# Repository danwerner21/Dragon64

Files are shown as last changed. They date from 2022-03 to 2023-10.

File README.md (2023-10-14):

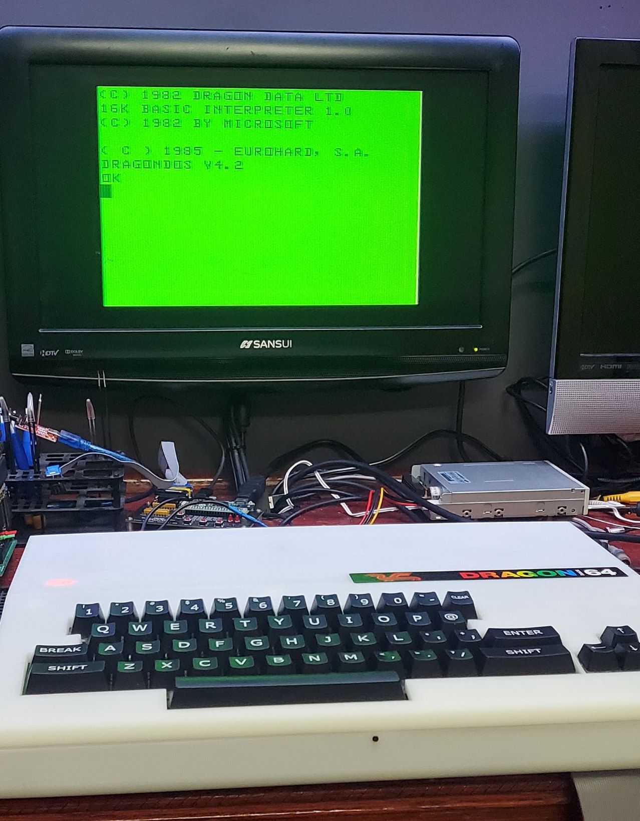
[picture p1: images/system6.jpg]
System

(note that I need to get a better picture of the screen, this is s-video and is very clear in person)

# Dragon 64 Clone PCB

The Dragon 64 is a home computer that was built in the 1980s for the European market by Dragon Data, Ltd. The Dragons are very similar to the TRS-80 Color Computer, and in fact provisions have been made to allow the keyboard to become compatible with a TRS-80 color computer clone.   This version of the Dragon 64 computer produces NTSC rather than PAL composite video and has the ability to produce "Commodore style LCA" s-video output for a much clearer video display.  It also supports either a vertical or horizontal cartridge slot and TTL level serial capabilities for convenient use of modern TTL to USB adaptors.

It should be possible for this PCB to become a Tandy Color Computer clone as well, but this is not implimented in V1.

A regulated 12V and 5V power supply is required.

The main PCB also includes a DragonDOS floppy controller that can be optionally populated to support floppy disk support.

A design is included for a 3d-printed retro style case.

Note that much of this work is based on the work done by Ciaran Anscomb.  Without that original work, this would have taken much longer to complete.

More generalized information on this line of retro computers can be found here:

   * https://en.wikipedia.org/wiki/Dragon_32/64
   * https://colorcomputerarchive.com/
   * https://cococentral.com/
   * https://www.6809.org.uk/dragon/
   * http://dragondata.co.uk/

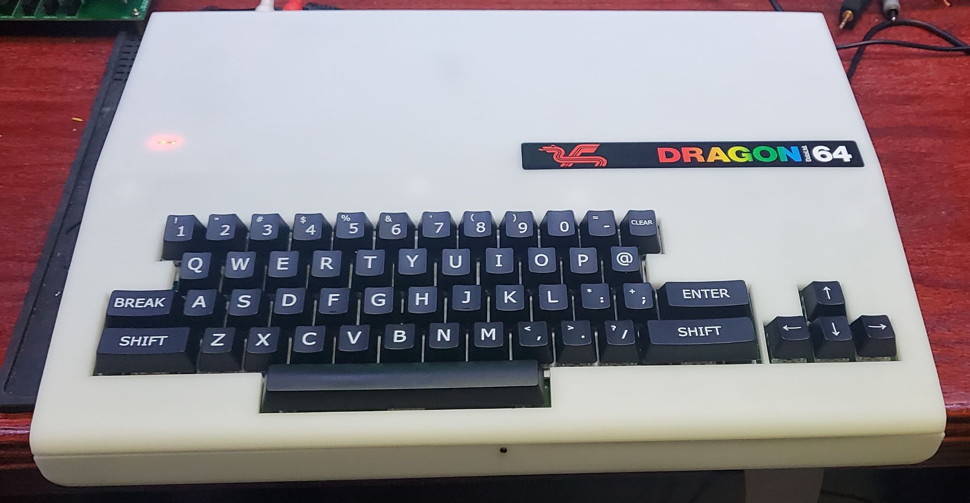
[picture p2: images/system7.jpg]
System

System
System

---

## To Do:
* test the joystick interface
* test the cassette interface
* test the printer interface
---

## What is included in this repo?
As of this time, the repo includes

1. The Mainboard PCB Kicad design and Gerber files
2. The Keyboard PCB Kicad design and Gerber files
3. OpenSCAD and STL files for a 3d printed case
4. SVG file for custom keycaps from MAX Keyboard

---

## Known Bugs

### System Jumpers
LK1 - Ram Size Selection 64K=1&2, 32K=2&3

J3 - Composite on Luma J3 on for composite video, off for S-video

J5 - Enable Disk ROM

---

## Bill Of Materials

### Mainboard
QTY|ref|value|part|description
--------|--------|----|--------|--------
1|IC4|4050|4050|
1|IC7|4069|4069|Hex inverter
8|IC15, IC16, IC21, IC22, IC26, IC27, IC32, IC33|4164|4164|
1|IC6|4529|4529|
1|IC11|6551|6551|
2|IC5,IC8|6821|6821|Peripheral Interface Adapter 1MHz| DIP-40
1|IC10|6847|6847|
1|IC39|6883|6883|
1|D8|1N914|1N914|100V 0.3A Small Signal Fast Switching Diode| DO-35
2|IC34,IC37|27C128|27C128|OTP EPROM 128 KiBit| [Obsolete 2004-01]
1|U5|27C64|27C64|OTP EPROM 64 KiBit| [Obsolete 2004-01]
2|IC35,U3|74LS00|74LS00|quad 2-input NAND gate
1|IC36|74LS02|74LS02|quad 2-input NOR gate
1|U6|74LS04|74LS04|Hex Inverter
1|U8|74LS06N|74LS06N|Inverter Open Collect
1|U4|74LS07|74LS07|Hex Buffers and Drivers With Open Collector High Voltage Outputs
1|IC40|74LS138|74LS138|Decoder 3 to 8 active low outputs
1|U7|74LS139|74LS139|Dual Decoder 1 of 4| Active low outputs
1|U9|74LS174|74LS174|Hex D-type Flip-Flop| reset
2|IC1|,C25|74LS244|74LS244|Octal Buffer and Line Driver With 3-State Output| active-low enables| non-inverting outputs
1|IC20|74LS273|74LS273|8-bit D Flip-Flop| reset
1|J1|Screw Terminal|5mm pitch|Power supply
1|C3|.002u|C|Unpolarized capacitor
37|C1, C7, C11, C12, C18, C20, C21, C22, C29, C31, C32, C34, C38, C39, C40, C41, C42, C43, C45, C46, C47, C50, C51, C52, C53, C55, C56, C57, C62, C65, C66, C70, C71, C72, C73, C74, C75, C76|.01u|C|Unpolarized capacitor
5|C6,C13,C14,C15,C16|.02u|C|Unpolarized capacitor
7|C27, C33, C4, C49, C59, C60, C61|.1u|C|Unpolarized capacitor
2|C33,C49|0.1uf|C|Unpolarized capacitor
1|C2|0.22uf|C|Unpolarized capacitor
1|C37|100pf|C|Unpolarized capacitor
1|C78|10nf|C|Unpolarized capacitor
2|C8,C48|1u|C|Unpolarized capacitor
1|C17|22p|C|Unpolarized capacitor
1|C35|25uf|C|Unpolarized capacitor
1|C44|470pf|C|Unpolarized capacitor
1|C67|47p|C|Unpolarized capacitor
1|C30|56pf|C|Unpolarized capacitor
1|C10|10u|C_Polarized_Small_US|Polarized capacitor| small US symbol
4|C9,C24,C25,C54|1u|C_Polarized_Small_US|Polarized capacitor| small US symbol
1|C26|C63|100uf|C_Polarized_US|Polarized capacitor| US symbol
1|C19|10uf|C_Polarized_US|Polarized capacitor| US symbol
1|C23|10uf 16v|C_Polarized_US|Polarized capacitor| US symbol
2|C58,C64|4.7uf|C_Polarized_US|Polarized capacitor| US symbol
1|C36|47uf|C_Polarized_US|Polarized capacitor| US symbol
2|C11,C7|.01u|C_Small|Unpolarized capacitor| small symbol
1|C77|8-70pf|C_Trim|Trimmable capacitor
1|J3|composite on luma|Conn_01x02_Male|Generic connector| single row| 01x02| script generated (kicad-library-utils/schlib/autogen/connector/)
1|J5|DISK ROM ENABLE|Conn_01x02_Male|Generic connector| single row| 01x02| script generated (kicad-library-utils/schlib/autogen/connector/)
1|J2|TTL Serial Connector|Conn_01x06_Male|Generic connector| single row| 01x06| script generated (kicad-library-utils/schlib/autogen/connector/)
1|PL6|Power/Video|Conn_01x09|Generic connector| single row| 01x09| script generated (kicad-library-utils/schlib/autogen/connector/)
1|PL1|Keyboard|Conn_01x16|Generic connector| single row| 01x16| script generated (kicad-library-utils/schlib/autogen/connector/)
1|PL2|Printer|Conn_02x10_Odd_Even|Generic connector| double row| 02x10| odd/even pin numbering scheme (row 1 odd numbers| row 2 even numbers)| script generated (kicad-library-utils/schlib/autogen/connector/)
1|J6|Floppy Interface|Conn_02x17_Odd_Even|Generic connector| double row| 02x17| odd/even pin numbering scheme (row 1 odd numbers| row 2 even numbers)| script generated (kicad-library-utils/schlib/autogen/connector/)
1|PL7|Cartridge|Conn_02x20_Odd_Even|Generic connector| double row| 02x20| odd/even pin numbering scheme (row 1 odd numbers| row 2 even numbers)| script generated (kicad-library-utils/schlib/autogen/connector/)
1|Y2|1.8432Mhz|Crystal|Two pin crystal
1|X1|14.31818Mhz|CXO_DIP14|Crystal Clock Oscillator| DIP14-style metal package
1|D4|1N4002|D|Diode
4|D5,D6,D7,D11|1N4148|D|Diode
4|D1,D12,D13,D14|1N914|D|Diode
2|D2,D3|BZX 61|D_Zener_Small|Zener diode| small symbol
1|J4|DB9_Male|DB9_Male|9-pin male D-SUB connector
1|PL4|Cassette|DIN-5_180degree|5-pin DIN connector (5-pin DIN-5 stereo)
2|PL3,PL5|Joystick L|DIN-6|6-pin DIN connector
1|LK1|Jumper_3_Bridged12| pins 1+2 closed/bridged
4|L1,L2,L3,L4|3.3u|L|Inductor
1|IC2|LM393|LM393|Low-Power| Low-Offset Voltage| Dual Comparators| DIP-8/SOIC-8/TO-99-8
1|U1|MAX232|MAX232|Dual RS232 driver/receiver| 5V supply| 120kb/s| 0C-70C
1|U2|MC1372|MC1372|
1|IC38|MC6809E|MC6809E|
2|Q2,Q3|2N2222|Q_NPN_BCE|NPN transistor| base/collector/emitter
1|TR1|BC182L|Q_NPN_BCE|NPN transistor| base/collector/emitter
1|Q1|BC557|Q_PNP_BCE|PNP transistor| base/collector/emitter
4|R45,R46,R47,R48|150|R|Resistor
2|R7,R12|390|R|Resistor
1|R30|420|R|Resistor
3|R6,R31,R85|470|R|Resistor
1|R43|750|R|Resistor
1|R13|820|R|Resistor
3|R17,R32,R42|100K|R|Resistor
1|R1|100R|R|Resistor
6|R9,R11,R15,R16,R26,R28|10K|R|Resistor
1|R29|10M|R|Resistor
1|R23|15K|R|Resistor
6|R10,R18,R27,R41,R44,R64|1K|R|Resistor
1|R22|1M5|R|Resistor
1|R4|220R|R|Resistor
11|R73,R74,R75,R76,R77 ,R78,R79,R80,R81,R82,R83|22R|R|Resistor
1|R40|33K|R|Resistor
1|R3|470R|R|Resistor
11|R14,R2,R24,R25,R65 ,R66,R67,R68,R69,R70,R71|4K7|R|Resistor
1|R8|5.6k|R|Resistor
2|R20,R21|56K|R|Resistor
1|R39|68K|R|Resistor
1|R19|6K8|R|Resistor
1|R5|8K2|R|Resistor
2|RV1,RV2|10K-Read|R_Potentiometer_Trim|Trim-potentiometer
1|R38|10K 1%|R_Small|Resistor| small symbol
1|R33|160K|R_Small|Resistor| small symbol
1|R37|20K 1%|R_Small|Resistor| small symbol
1|R34|330K|R_Small|Resistor| small symbol
1|R36|40K2 1%|R_Small|Resistor| small symbol
1|R35|80K6 1%|R_Small|Resistor| small symbol
1|RLA1|SPDT|TIANBO-HJR-4102-L|TIANBO HJR-4102-L| Single Pole Relay| 5mm Pitch| 3A
1|U10|WD2797|WD2797|Floppy disk controller| DIP-40
1|X2|1Mhz|XO91|HCMOS Clock Oscillator

### Keyboard
QTY|ref|value|part|description
--------|--------|----|--------|--------
53|SW(X)|KEYSWITCH|MX Cherry - Linear
3||Switch Leveling Kit|LEVELING KIT FOR LARGER KEYS|EXAMPLE:https://www.amazon.com/Keyboard-Screw-Stabilizers-6-25u-Mechanical/dp/B094R45K8Z  -or-   https://www.amazon.com/dp/B0978PWJG9 
1||Switch Leveling Kit|LEVELING KIT FOR SPACEBAR| EXAMPLE:https://www.amazon.com/Keyboard-Screw-Stabilizers-6-25u-Mechanical/dp/B094R45K8Z  -or-   https://www.amazon.com/dp/B0978PWJG9 
2|J1,J2|01X16 HEADER|Connector_PinHeader_2.54mm:PinHeader_1x16_P2.54mm_Vertical

### Floppy Drive Calibration (an oscilloscope is required)
1. power on, allow machine to reset and boot

2. ground Pin 22 of U10(WD2797)

3. Set VC0 by Measuring at pin 16 of the U10(WD2797),  Adjust the signal to 250 KHz (capacitor C77)

4. WP setting by Measuring signal at pin 31 of the U10(WD2797), Set pulse width to 300ns (RV2 potentiometer)

5. PR adjustment by Measuring signal at pin 29 of U10(WD2797), Set pulse width to 600ns (potentiometer RV1)

6. remove Pin 22 of the U10(WD2797) from ground

7. restart machine

### Case

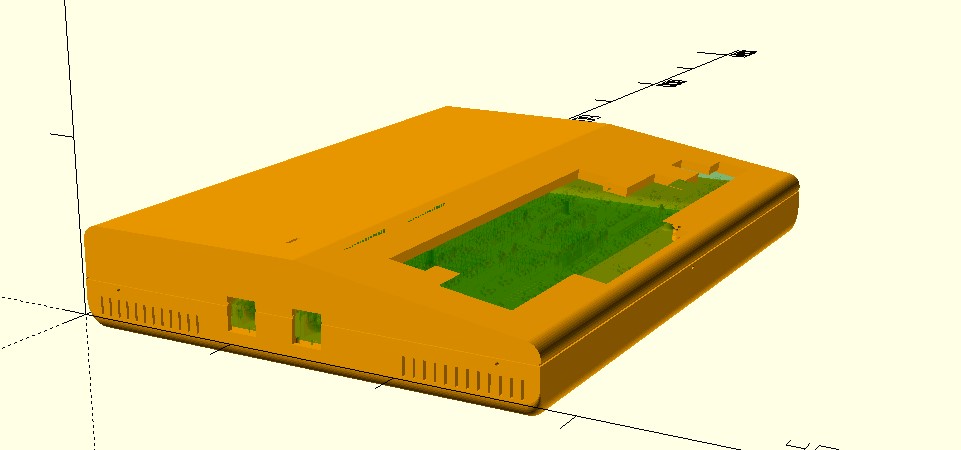
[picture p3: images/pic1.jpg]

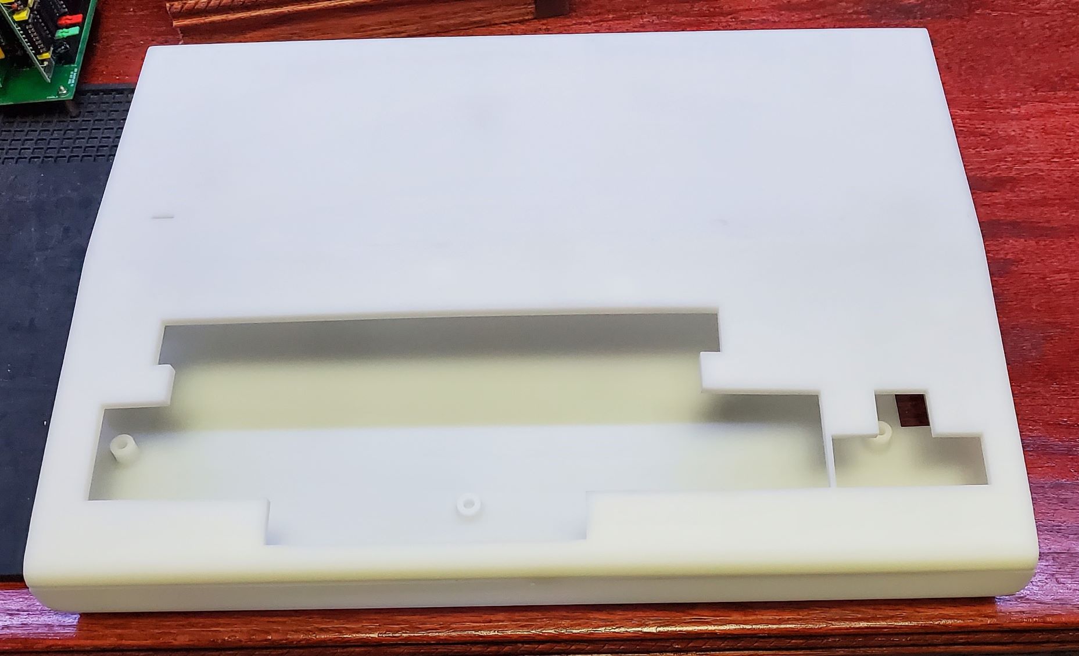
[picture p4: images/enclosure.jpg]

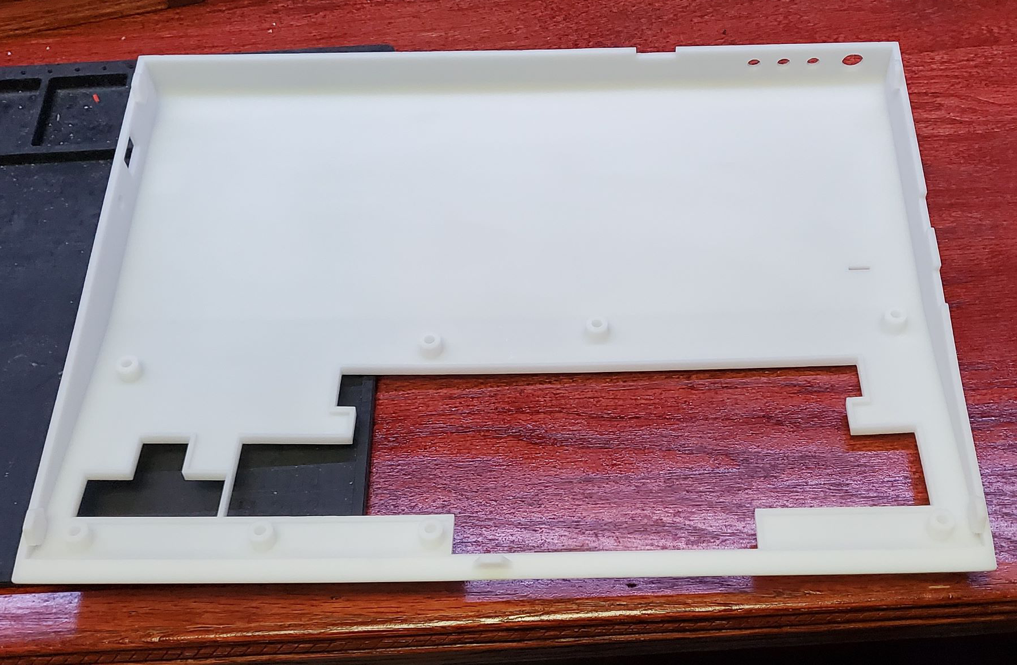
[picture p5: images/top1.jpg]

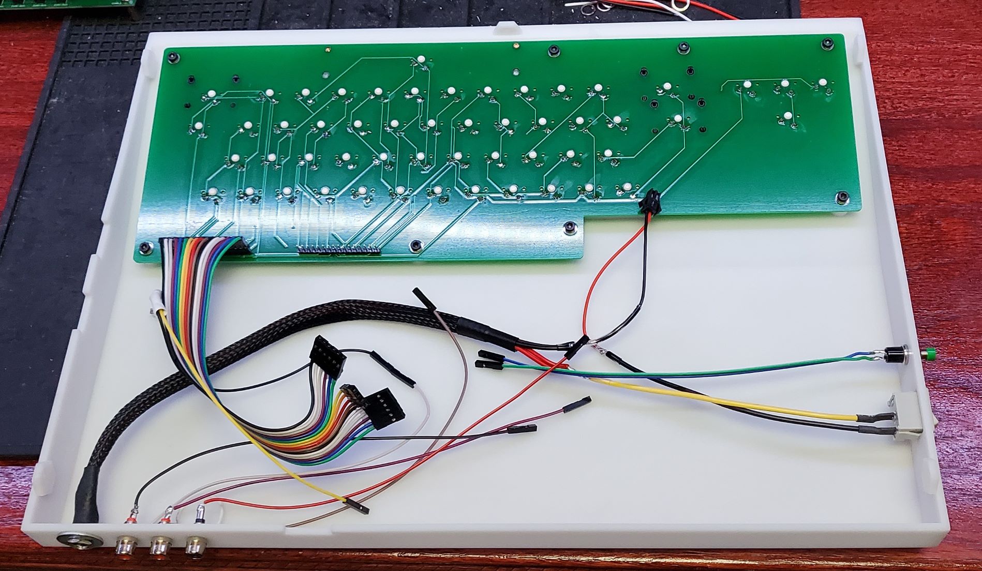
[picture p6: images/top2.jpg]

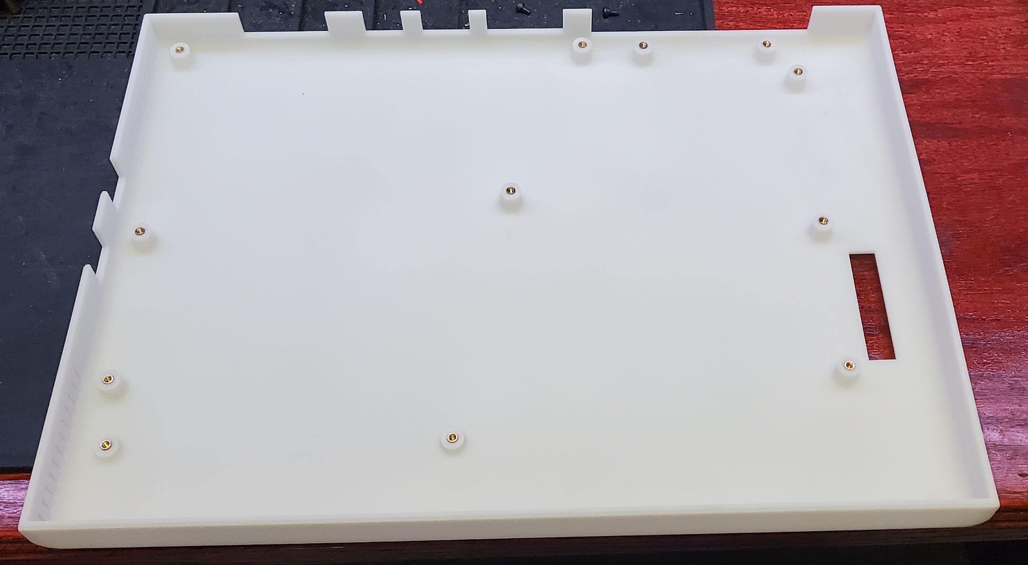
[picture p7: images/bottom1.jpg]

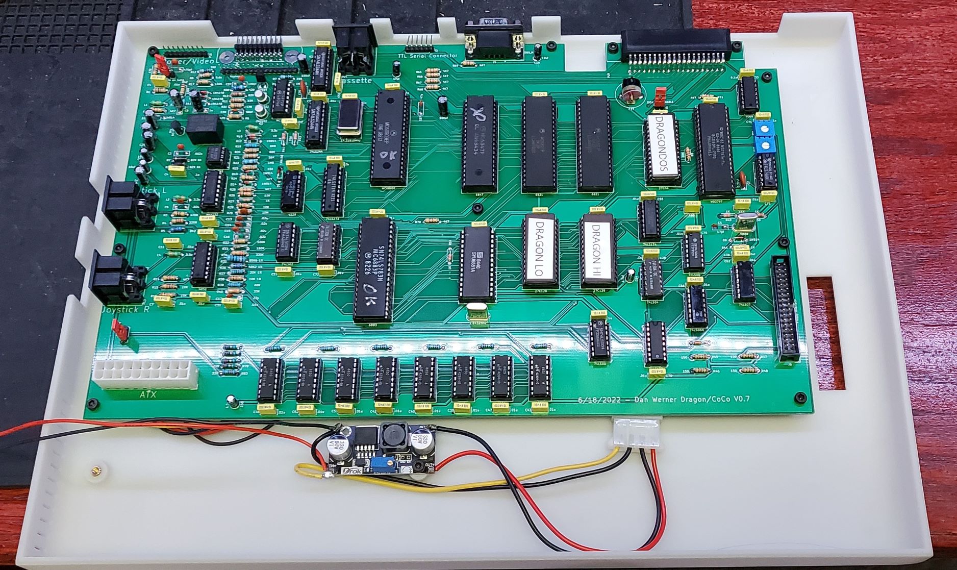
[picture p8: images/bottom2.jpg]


### Questions?

If there are any questions, I can be reached at vic2020Dan at gmail dot com.

---

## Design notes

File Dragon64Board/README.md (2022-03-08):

# Dragon 64 schematic

... and PCB layout, in [KiCad](https://www.kicad.org/).

The schematic capture is complete, and I've done one full verification pass.
But I'm still making no promises about correctness!  I've uploaded a PDF for
those without access to KiCad.

 * [Dragon 64 schematic PDF](https://www.6809.org.uk/dragon/dragon64-schematic.pdf)

A lot of the PCB positioning is now correct - at least to the nearest mm,
usually better - and everything's pointing in a sensible direction with the
exception of some diodes: Dragon Data ensured they always had the cathode to
the right, presumably to avoid manufacturing confusion, and I've preserved that
decision.

As it stands the PCB is now fully routed.  I think it has reasonable power
distribution, and where possible, I've tried to route such that the decoupling
capacitor positions make sense.  Crystal tracks should be reasonably well
separated from anything else, and apart from a tiny skirt around the outside of
the ACIA crystal housing, no tracks pass underneath them either.

[Freerouting](https://github.com/freerouting/freerouting) did the rest, and it
looks ok to me!  Less than 200 vias in the end.  Fully autorouted achieves a
lot less, but I wasn't terribly happy with how it dealt with the sensitive bits
above.  I think 200 still compares pretty well to the original boards.

It would be nice to learn some FreeCAD to make the 3D view nicer, but
I must admit that's looking pretty low priority for now.

 * [3D view](https://www.6809.org.uk/dragon/dragon64-kicad-pcb.jpg)

Changes from the original:

 * The 240° 5-pin DIN sockets used for joysticks appear to be a bit harder to
   find now.  I've replaced them with (compatible) 6-pin sockets.
 * The footprint for the 7-pin DIN serial connector is incompatible (2-3-2
   instead of 3-4).  This reflects what I've found to be available today.
 * Two more inductors and capacitors have been added as optional components to
   enable the second firebutton on CoCo 3 compatible joysticks.

Note also that the mounting holes for the edge connector are placed
differently, and not very well with respect to the board, so definitely don't
use this layout as-is.  40-way 2.54mm pitch card edge connector sockets seem to
be like hen's teeth at the moment.  Stewart Orchard points out that EDAC list
some, and that's the footprint you currently see.  Not that anyone appears to
sell it.  Likely I'll update the footprint to match what's in our Dragons so
that if anyone's fool enough to get a board made, they can take a donor.

## Acknowledgements

Thanks to Richard Harding for hosting high quality copies of the original
drawings - doing this from the old scans would have been nigh on impossible.

 * [Original drawings](http://dragondata.co.uk/tech/circuit-diag/index.html)

Thanks also to Stewart Orchard, who has done a similar capture of the Dragon's
PSU board.  I also nabbed his 3D model of the DIN socket to represent all the
similar ports in this project (you'll notice they're the wrong shape for the
joystick ports, and none of them have more than three pins).

 * [DragonISS4PSU](https://gitlab.com/sorchard001/dragoniss4psu)

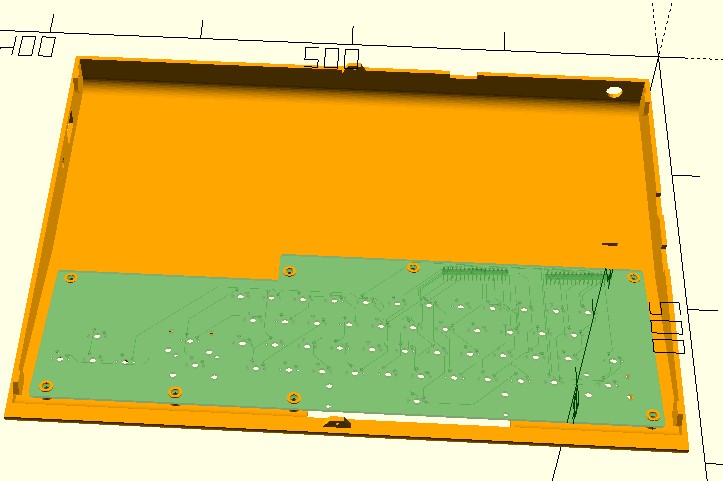
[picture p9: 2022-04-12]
images/pic5.jpg

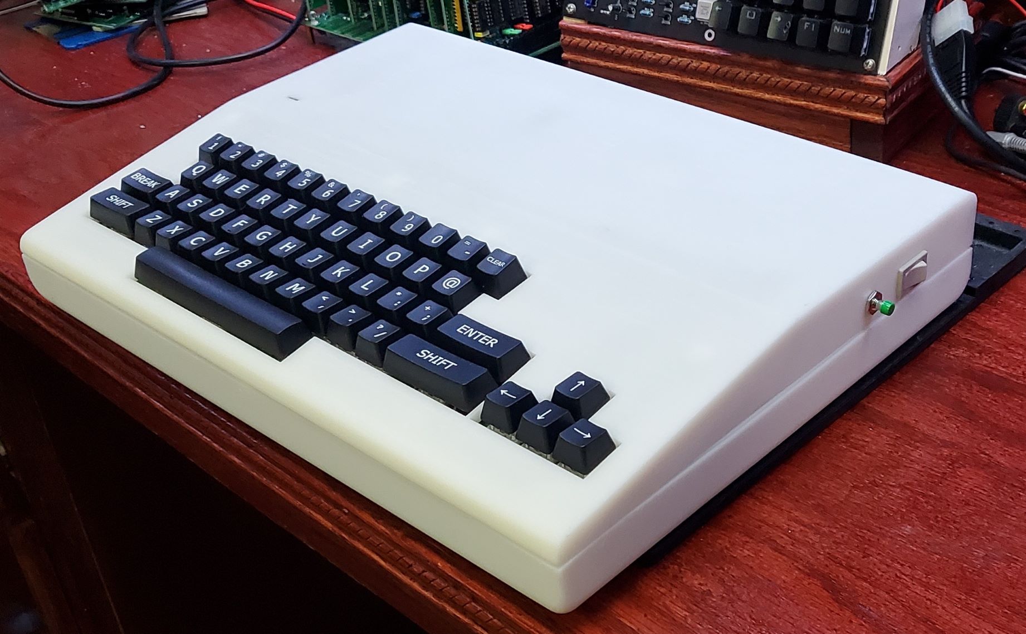
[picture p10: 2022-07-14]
images/system4.jpg

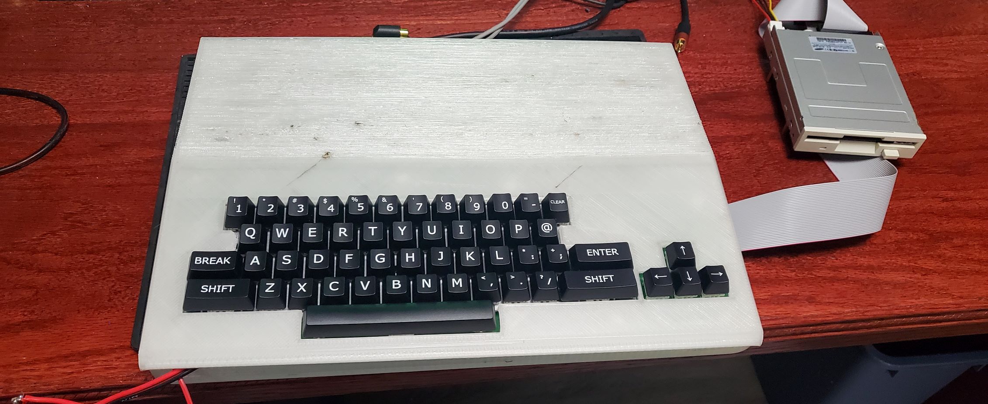
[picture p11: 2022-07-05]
images/system2.jpg

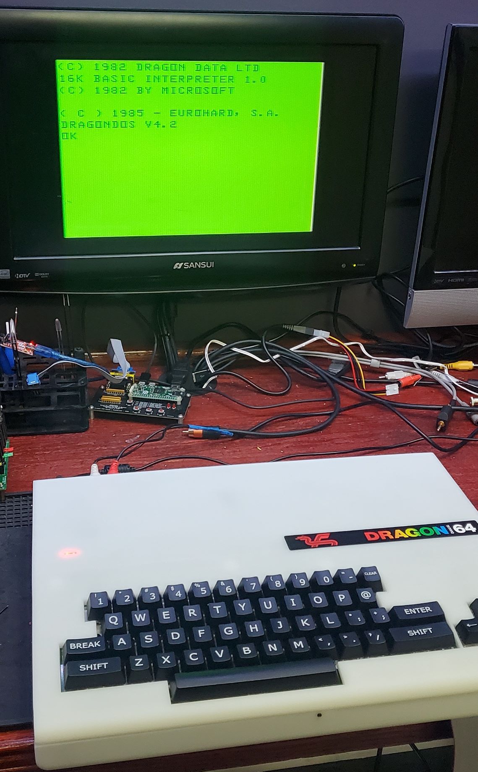
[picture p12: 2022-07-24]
images/system5.jpg

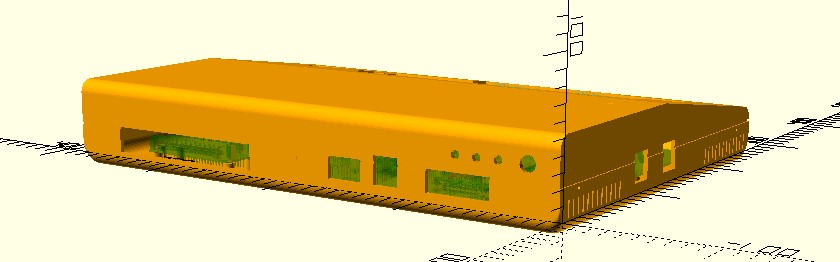
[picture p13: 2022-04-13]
images/pic2.jpg

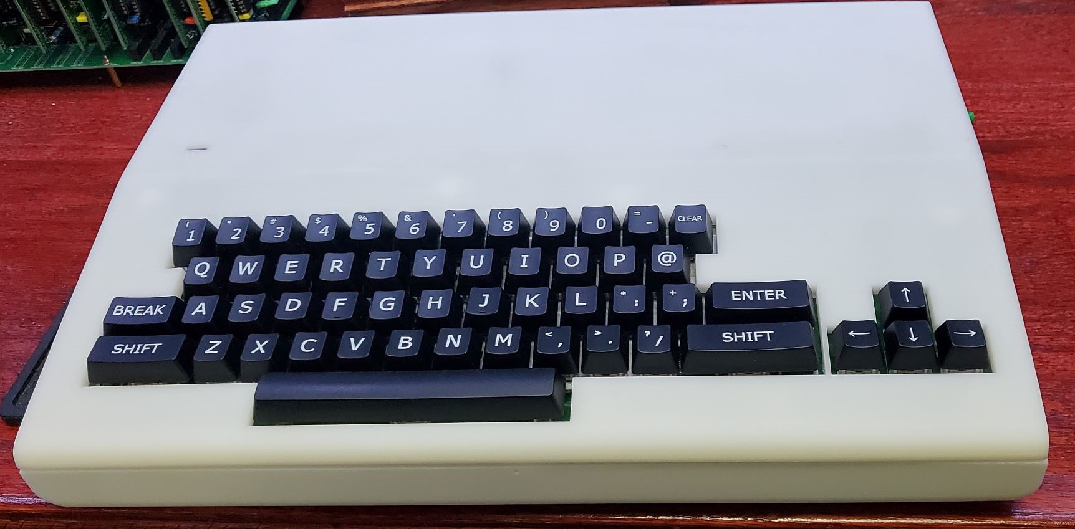
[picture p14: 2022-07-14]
images/system3a.jpg

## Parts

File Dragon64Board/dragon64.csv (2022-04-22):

Comment | Designator | Footprint | LCSC
10u | C10 | Capacitor_THT:CP_Radial_D4.0mm_P2.00mm
22p | C17 | Capacitor_THT:C_Disc_D7.5mm_W2.5mm_P5.00mm
10uf | C19 | Capacitor_THT:CP_Radial_D4.0mm_P2.00mm
10uf 16v | C23 | Capacitor_THT:CP_Radial_D4.0mm_P2.00mm
.002u | C3 | Capacitor_THT:C_Disc_D7.5mm_W2.5mm_P5.00mm
56pf | C30 | Capacitor_THT:C_Disc_D7.5mm_W2.5mm_P5.00mm
0.1uf | C33,C49 | Capacitor_THT:C_Disc_D7.5mm_W2.5mm_P5.00mm
25uf | C35 | Capacitor_THT:C_Disc_D7.5mm_W2.5mm_P5.00mm
47uf | C36 | Capacitor_THT:CP_Radial_D4.0mm_P2.00mm
100pf | C37 | Capacitor_THT:C_Disc_D7.5mm_W2.5mm_P5.00mm
470pf | C44 | Capacitor_THT:C_Disc_D7.5mm_W2.5mm_P5.00mm
.02u | C6,C13,C14,C15,C16 | Capacitor_THT:C_Disc_D7.5mm_W2.5mm_P5.00mm
.1u | C2,C4,C5,C27,C28,C59,C60,C61,C68,C69 | Capacitor_THT:C_Disc_D7.5mm_W2.5mm_P5.00mm
.01u | C1,C7,C11,C12,C18,C20,C21,C22,C29,C31,C32,C34,C38,C39,C40,C41,C42,C43,C45,C46,C47,C50,C51,C52,C53,C55,C56,C57,C62,C65,C66,C70,C71,C72,C73,C74,C75,C76 | Capacitor_THT:C_Disc_D7.5mm_W2.5mm_P5.00mm
100uf | C26,C63 | Capacitor_THT:CP_Radial_D4.0mm_P2.00mm
4.7uf | C58,C64 | Capacitor_THT:CP_Radial_D4.0mm_P2.00mm
47p | C67 | Capacitor_THT:C_Disc_D7.5mm_W2.5mm_P5.00mm
8-70pf | C77 | Capacitor_THT:C_Radial_D6.3mm_H7.0mm_P2.50mm
10nf | C78 | Capacitor_THT:C_Disc_D7.5mm_W2.5mm_P5.00mm
1u | C8,C48 | Capacitor_THT:C_Disc_D7.5mm_W2.5mm_P5.00mm
1u | C9,C24,C25,C54 | Capacitor_THT:CP_Radial_D4.0mm_P2.00mm
1N914 | D1,D8,D12,D13,D14 | Diode_THT:D_DO-35_SOD27_P7.62mm_Horizontal
1N4148 | D5,D6,D7,D11 | Diode_THT:D_DO-35_SOD27_P7.62mm_Horizontal
BZX 61 | D2,D3 | Diode_THT:D_DO-35_SOD27_P7.62mm_Horizontal
1N4002 | D4 | Diode_THT:D_DO-35_SOD27_P7.62mm_Horizontal
MountingHole | H1,H2,H3,H4,H5,H6,H7,H8 | MountingHole:MountingHole_3.2mm_M3
6847 | IC10 | Package_DIP:DIP-40_W15.24mm_Socket_LongPads
6551 | IC11 | Package_DIP:DIP-28_W15.24mm_Socket_LongPads
4164 | IC15,IC16,IC21,IC22,IC26,IC27,IC32,IC33 | Package_DIP:DIP-16_W7.62mm_Socket_LongPads
LM393 | IC2 | Package_DIP:DIP-8_W7.62mm_Socket_LongPads
74LS273 | IC20 | Package_DIP:DIP-20_W7.62mm_Socket_LongPads
74LS244 | IC1,IC25 | Package_DIP:DIP-20_W7.62mm_Socket_LongPads
74LS00 | U3,IC35 | Package_DIP:DIP-14_W7.62mm_Socket_LongPads
74LS02 | IC36 | Package_DIP:DIP-14_W7.62mm_Socket_LongPads
27C128 | IC34,IC37 | Package_DIP:DIP-28_W15.24mm_Socket_LongPads
MC6809E | IC38 | Package_DIP:DIP-40_W15.24mm_Socket_LongPads
6883 | IC39 | Package_DIP:DIP-40_W15.24mm_Socket_LongPads
4050 | IC4 | Package_DIP:DIP-16_W7.62mm_Socket_LongPads
74LS138 | IC40 | Package_DIP:DIP-16_W7.62mm_Socket_LongPads
6821 | IC5,IC8 | Package_DIP:DIP-40_W15.24mm_Socket_LongPads
4529 | IC6 | Package_DIP:DIP-16_W7.62mm_Socket_LongPads
4069 | IC7 | Package_DIP:DIP-14_W7.62mm_Socket_LongPads
ATX | J1 | Connector_Molex:Molex_Mini-Fit_Jr_5566-20A_2x10_P4.20mm_Vertical
TTL Serial Connector | J2 | Connector_PinHeader_2.54mm:PinHeader_1x06_P2.54mm_Vertical
composite on luma | J3 | Connector_PinHeader_2.54mm:PinHeader_1x02_P2.54mm_Vertical
DB9_Male | J4 | Connector_Dsub:DSUB-9_Male_Horizontal_P2.77x2.84mm_EdgePinOffset4.94mm_Housed_MountingHolesOffset7.48mm
DISK ROM ENABLE | J5 | Connector_PinHeader_2.54mm:PinHeader_1x02_P2.54mm_Vertical
Floppy Interface | J6 | Connector_IDC:IDC-Header_2x17_P2.54mm_Vertical
3.3u | L1,L2,L3,L4 | Inductor_THT:L_Axial_L5.3mm_D2.2mm_P7.62mm_Horizontal_Vishay_IM-1
~ | LK1 | Connector_PinHeader_2.54mm:PinHeader_1x03_P2.54mm_Vertical
Keyboard | PL1 | Connector_PinHeader_2.54mm:PinHeader_1x16_P2.54mm_Vertical
Printer | PL2 | dragon64:IDC-Header_2x10-1MP_P2.54mm_Latch_Horizontal
Joystick R | PL3 | dragon64:DIN-6_DELTRON_671-0601_Horizontal
Cassette | PL4 | dragon64:DIN-5_DELTRON_671-0501_45deg_Horizontal
Joystick L | PL5 | dragon64:DIN-6_DELTRON_671-0601_Horizontal
Power/Video | PL6 | Connector_PinHeader_2.54mm:PinHeader_1x09_P2.54mm_Vertical
Cartridge | PL7,PL9 | dragon64:Edge_2x20_P2.54mm_Horizontal
BC557 | Q1 | logo:TO-92_HandSolder_FIXED
2N2222 | Q2,Q3 | logo:TO-18-3_FIXED
100R | R1 | Resistor_THT:R_Axial_DIN0207_L6.3mm_D2.5mm_P7.62mm_Horizontal
10K | R9,R11,R15,R16,R26,R28 | Resistor_THT:R_Axial_DIN0207_L6.3mm_D2.5mm_P7.62mm_Horizontal
820 | R13 | Resistor_THT:R_Axial_DIN0207_L6.3mm_D2.5mm_P7.62mm_Horizontal
100K | R17,R32,R42 | Resistor_THT:R_Axial_DIN0207_L6.3mm_D2.5mm_P7.62mm_Horizontal
6K8 | R19 | Resistor_THT:R_Axial_DIN0207_L6.3mm_D2.5mm_P7.62mm_Horizontal
56K | R20,R21 | Resistor_THT:R_Axial_DIN0207_L6.3mm_D2.5mm_P7.62mm_Horizontal
1M5 | R22 | Resistor_THT:R_Axial_DIN0207_L6.3mm_D2.5mm_P7.62mm_Horizontal
15K | R23 | Resistor_THT:R_Axial_DIN0207_L6.3mm_D2.5mm_P7.62mm_Horizontal
10M | R29 | Resistor_THT:R_Axial_DIN0207_L6.3mm_D2.5mm_P7.62mm_Horizontal
470R | R3 | Resistor_THT:R_Axial_DIN0207_L6.3mm_D2.5mm_P7.62mm_Horizontal
420 | R30 | Resistor_THT:R_Axial_DIN0207_L6.3mm_D2.5mm_P7.62mm_Horizontal
160K | R33 | Resistor_THT:R_Axial_DIN0207_L6.3mm_D2.5mm_P7.62mm_Horizontal
330K | R34 | Resistor_THT:R_Axial_DIN0207_L6.3mm_D2.5mm_P7.62mm_Horizontal
80K6 1% | R35 | Resistor_THT:R_Axial_DIN0207_L6.3mm_D2.5mm_P7.62mm_Horizontal
40K2 1% | R36 | Resistor_THT:R_Axial_DIN0207_L6.3mm_D2.5mm_P7.62mm_Horizontal
20K 1% | R37 | Resistor_THT:R_Axial_DIN0207_L6.3mm_D2.5mm_P7.62mm_Horizontal
10K 1% | R38 | Resistor_THT:R_Axial_DIN0207_L6.3mm_D2.5mm_P7.62mm_Horizontal
68K | R39 | Resistor_THT:R_Axial_DIN0207_L6.3mm_D2.5mm_P7.62mm_Horizontal
220R | R4 | Resistor_THT:R_Axial_DIN0207_L6.3mm_D2.5mm_P7.62mm_Horizontal
33K | R40 | Resistor_THT:R_Axial_DIN0207_L6.3mm_D2.5mm_P7.62mm_Horizontal
750 | R43 | Resistor_THT:R_Axial_DIN0207_L6.3mm_D2.5mm_P7.62mm_Horizontal
150 | R45,R46,R47,R48 | Resistor_THT:R_Axial_DIN0207_L6.3mm_D2.5mm_P7.62mm_Horizontal
8K2 | R5 | Resistor_THT:R_Axial_DIN0207_L6.3mm_D2.5mm_P7.62mm_Horizontal
1K | R10,R18,R27,R41,R44,R64 | Resistor_THT:R_Axial_DIN0207_L6.3mm_D2.5mm_P7.62mm_Horizontal
390 | R7,R12 | Resistor_THT:R_Axial_DIN0207_L6.3mm_D2.5mm_P7.62mm_Horizontal
4K7 | R2,R14,R24,R25,R65,R66,R67,R68,R69,R70,R71 | Resistor_THT:R_Axial_DIN0207_L6.3mm_D2.5mm_P7.62mm_Horizontal
22R | R73,R74,R75,R76,R77,R78,R79,R80,R81,R82,R83 | Resistor_THT:R_Axial_DIN0207_L6.3mm_D2.5mm_P7.62mm_Horizontal
5.6k | R8 | Resistor_THT:R_Axial_DIN0207_L6.3mm_D2.5mm_P7.62mm_Horizontal
470 | R6,R31,R85 | Resistor_THT:R_Axial_DIN0207_L6.3mm_D2.5mm_P7.62mm_Horizontal
SPDT | RLA1 | Relay_THT:Relay_SPDT_HJR-4102
10K-Read | RV1 | Potentiometer_THT:Potentiometer_Vishay_T73YP_Vertical
10K-Write | RV2 | Potentiometer_THT:Potentiometer_Vishay_T73YP_Vertical
BC182L | TR1 | Package_TO_SOT_THT:TO-92
MAX232 | U1 | Package_DIP:DIP-16_W7.62mm_Socket_LongPads
WD2797 | U10 | Package_DIP:DIP-40_W15.24mm
MC1372 | U2 | Package_DIP:DIP-14_W7.62mm_Socket_LongPads
74LS07 | U4 | Package_DIP:DIP-14_W7.62mm_Socket_LongPads
27C64 | U5 | Package_DIP:DIP-28_W15.24mm_Socket_LongPads
74LS04 | U6 | Package_DIP:DIP-14_W7.62mm_Socket_LongPads
74LS139 | U7 | Package_DIP:DIP-16_W7.62mm_Socket_LongPads
74LS06N | U8 | Package_DIP:DIP-14_W7.62mm_Socket_LongPads
74LS174 | U9 | Package_DIP:DIP-16_W7.62mm_Socket_LongPads
14.31818Mhz | X1 | Package_DIP:DIP-14_W7.62mm_Socket_LongPads
4Mhz | X3 | Package_DIP:DIP-14_W7.62mm_Socket_LongPads
1.8432Mhz | Y2 | Crystal:Crystal_HC49-U_Vertical

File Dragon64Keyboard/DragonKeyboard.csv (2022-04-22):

Comment | Designator | Footprint | LCSC
MountingHole | H1,H2,H3,H4,H5,H6,H7,H8 | MountingHole:MountingHole_3.2mm_M3_Pad
DRAGON_CONNECTION | J1 | Connector_PinHeader_2.54mm:PinHeader_1x16_P2.54mm_Vertical
CoCo_CONNECTION | J2 | Connector_PinHeader_2.54mm:PinHeader_1x16_P2.54mm_Vertical
0 | SW1 | Cherry_MX:CHERRY_PCB_100H
9 | SW10 | Cherry_MX:CHERRY_PCB_100H
RIGHT | SW11 | Cherry_MX:CHERRY_PCB_100H
MINUS | SW12 | Cherry_MX:CHERRY_PCB_100H
AT | SW14 | Cherry_MX:CHERRY_PCB_100H
COLON | SW16 | Cherry_MX:CHERRY_PCB_100H
SEMICOLON | SW17 | Cherry_MX:CHERRY_PCB_100H
COMMA | SW19 | Cherry_MX:CHERRY_PCB_100H
1 | SW2 | Cherry_MX:CHERRY_PCB_100H
PERIOD | SW20 | Cherry_MX:CHERRY_PCB_100H
SLASH | SW21 | Cherry_MX:CHERRY_PCB_100H
A | SW23 | Cherry_MX:CHERRY_PCB_100H
B | SW24 | Cherry_MX:CHERRY_PCB_100H
C | SW25 | Cherry_MX:CHERRY_PCB_100H
D | SW26 | Cherry_MX:CHERRY_PCB_100H
E | SW27 | Cherry_MX:CHERRY_PCB_100H
F | SW28 | Cherry_MX:CHERRY_PCB_100H
G | SW29 | Cherry_MX:CHERRY_PCB_100H
2 | SW3 | Cherry_MX:CHERRY_PCB_100H
H | SW30 | Cherry_MX:CHERRY_PCB_100H
I | SW31 | Cherry_MX:CHERRY_PCB_100H
J | SW32 | Cherry_MX:CHERRY_PCB_100H
K | SW33 | Cherry_MX:CHERRY_PCB_100H
L | SW34 | Cherry_MX:CHERRY_PCB_100H
M | SW35 | Cherry_MX:CHERRY_PCB_100H
N | SW36 | Cherry_MX:CHERRY_PCB_100H
O | SW37 | Cherry_MX:CHERRY_PCB_100H
P | SW38 | Cherry_MX:CHERRY_PCB_100H
Q | SW39 | Cherry_MX:CHERRY_PCB_100H
3 | SW4 | Cherry_MX:CHERRY_PCB_100H
R | SW40 | Cherry_MX:CHERRY_PCB_100H
S | SW41 | Cherry_MX:CHERRY_PCB_100H
T | SW42 | Cherry_MX:CHERRY_PCB_100H
U | SW43 | Cherry_MX:CHERRY_PCB_100H
V | SW44 | Cherry_MX:CHERRY_PCB_100H
W | SW45 | Cherry_MX:CHERRY_PCB_100H
X | SW46 | Cherry_MX:CHERRY_PCB_100H
Y | SW47 | Cherry_MX:CHERRY_PCB_100H
Z | SW48 | Cherry_MX:CHERRY_PCB_100H
SHIFT | SW49 | Cherry_MX:CHERRY_PCB_225H
4 | SW5 | Cherry_MX:CHERRY_PCB_100H
DOWN | SW50 | Button_Switch_Keyboard:SW_Cherry_MX_1.00u_PCB
5 | SW6 | Cherry_MX:CHERRY_PCB_100H
BREAK | SW61 | Button_Switch_Keyboard:SW_Cherry_MX_1.75u_PCB
ENTER | SW64 | Cherry_MX:CHERRY_PCB_225H
SPACE | SW65 | Cherry_MX:CHERRY_PCB_625H
CLEAR | SW66 | Cherry_MX:CHERRY_PCB_100H
LEFT | SW69 | Cherry_MX:CHERRY_PCB_100H
6 | SW7 | Cherry_MX:CHERRY_PCB_100H
UP | SW70 | Cherry_MX:CHERRY_PCB_100H
SHIFT | SW73 | Cherry_MX:CHERRY_PCB_275H
7 | SW8 | Cherry_MX:CHERRY_PCB_100H
8 | SW9 | Cherry_MX:CHERRY_PCB_100H

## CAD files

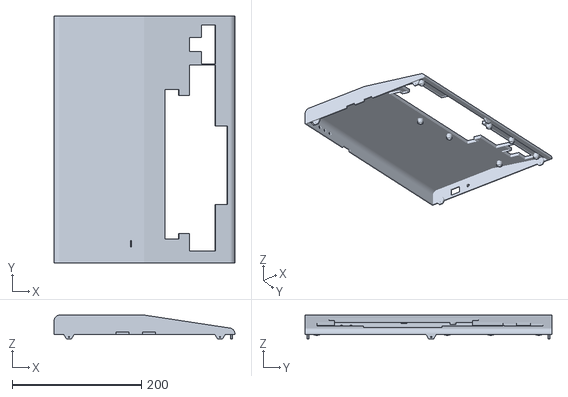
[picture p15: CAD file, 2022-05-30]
Enclosure/DragonCase_top.stl
280.0 x 382.5 x 36.9

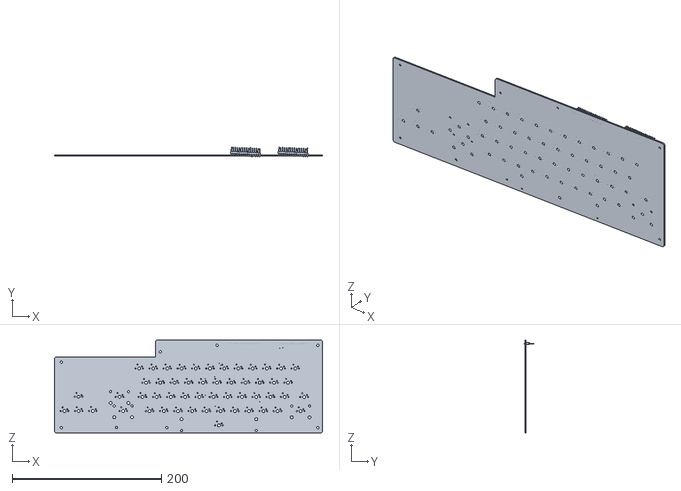
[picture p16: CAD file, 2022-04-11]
Enclosure/keyboard.stl
359.1 x 13.4 x 124.5

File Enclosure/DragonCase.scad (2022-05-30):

/* [Box dimensions] */
  Length        = 280;       
  Width         = 385;                     
  TopHeight        = 10;  
  BottomHeight     = 21;  
  SlopeHeight      = 20;
  BackShelf     =130;
  Thick         = 3;//[2:5]  


  
/* [Box options] */
  PCBFeet       = 1;// [0:No, 1:Yes]
  Vent          = 1;// [0:No, 1:Yes]
  Vent_width    = 1.5;   



  Filet         = 9;//[0.1:12] 
  Resolution    = 50;//[1:100] 
  m             = 0.9;
  
/* [PCB_Feet--the_board_will_not_be_exported) ] */
PCBPosX         = 0;
PCBPosY         = 0;
PCBLength       = 142;
PCBWidth        = 360;
FootHeight      = 5;
FootDia         = 10;
FootHole        = 5;  /* 4.4 for melt in 5 for glue in */
  

/* [STL element to export] */
//Top shell
  TShell        = 0;// [0:No, 1:Yes]
//Bottom shell
  BShell        = 1;// [0:No, 1:Yes]
// Show PCBs
  ShowPCB       = 0;// [0:No, 1:Yes]
  
/* [Hidden] */
Couleur1        = "Orange";       
Couleur2        = "OrangeRed";    
Dec_Thick       = Vent ? Thick*2 : Thick; 
Dec_size        = Vent ? Thick*2 : 0.8;

PCBL=PCBLength;
PCBW=PCBWidth;



   
module SlopeRoundBox($a=Length, $b=Width, $c=TopHeight+BottomHeight){
                    $fn=Resolution;     
                         
                        translate([Filet,-Filet/2,Filet])
                        {  
                    minkowski ()
                    {  
              
                    translate([0,($b/2)+1,TopHeight])
                       rotate(a=[0,-90,90])
                          linear_extrude(height =(($b/2)-Filet/2)+1, center = false, convexity = 0, twist = 0)
                              polygon(points=[[0,0],[(SlopeHeight+TopHeight)*-1,0],[(SlopeHeight+TopHeight)*-1,BackShelf*-1],  [TopHeight*-1,($a-Filet*2)*-1],[0,($a-Filet*2)*-1]], paths=[[3,2,1,0]]);                      
                        
                     rotate([270,0,0]){    
                        cylinder(r=Filet,h=Width/2+1, center = false);
                            } 
                        }
                    }
                }// End of SlopeRoundBox Module                


module RoundBox($a=Length, $b=Width, $c=TopHeight+BottomHeight){
                    $fn=Resolution;            
                    translate([0,Filet,Filet]){  
                    minkowski (){                                              
                        cube ([$a-(Length/2),$b-(2*Filet),$c-(2*Filet)], center = false);
                        rotate([0,90,0]){   
                           translate([0,0,Filet]){  
                        cylinder(r=Filet,h=Length/2-(2*Filet), center = false);}
                            } 
                        rotate([270,0,0]){    
                        cylinder(r=Filet,h=.1, center = false);
                            } 
                        }
                    }
                }// End of RoundBox Module

      


module TopShell(){
    Thick = Thick*2;  
    difference(){    
        difference(){
            union(){    
                     difference() {
                      
                        difference(){
                            union() {                                
                                        KeyboardCutoutReinforcement();

                            difference(){
                                SlopeRoundBox();
                                translate([Thick/2,Thick/2,Thick/2]){     
                                        SlopeRoundBox($a=Length-Thick*2, $b=Width-Thick*2, $c=TopHeight+BottomHeight-Thick);
                                        }
                                        }
                                    }
                               translate([-Thick,-Thick,TopHeight]){
                                   cube ([Length+100, Width+100, TopHeight+BottomHeight], center=false);
                                            }                                            
                                      }
                                }                                          
                // These are the tabs that attach the top to the bottom
                difference(){
                    union(){
                        
                        // four sides
                        translate([3*Thick +5,Thick,TopHeight]){
                            rotate([90,0,0]){
                                    $fn=6;
                                    cylinder(d=16,Thick/2);
                                    }   
                            }
                            
                       translate([Length-((3*Thick)+5),Thick,TopHeight]){
                            rotate([90,0,0]){
                                    $fn=6;
                                    cylinder(d=16,Thick/2);
                                    }   
                            }

                    translate([3*Thick +5,Width-Thick/2-2.4,TopHeight]){
                            rotate([90,0,0]){
                                    $fn=6;
                                    cylinder(d=16,Thick/2);
                                    }   
                            }
                            
                       translate([Length-((3*Thick)+5),Width-Thick/2-2.4,TopHeight]){
                            rotate([90,0,0]){
                                    $fn=6;
                                    cylinder(d=16,Thick/2);
                                    }   
                            }

                        // front and back
                       translate([Length-Thick-0.5,(Width/2)-Thick/2-2.4,TopHeight]){
                            rotate([90,0,90]){
                                    $fn=6;
                                    cylinder(d=16,Thick/2);
                                    }   
                            }
                            
                        }




                            
                    } 
                    
                    
            }

       }


///Put Difference Keyboard Cutout Here

            union(){ //sides holes
                $fn=50;
                translate([3*Thick+5,20,TopHeight+4]){
                    rotate([90,0,0]){
                    cylinder(d=2,20);
                    }
                }
                translate([Length-((3*Thick)+5),20,TopHeight+4]){
                    rotate([90,0,0]){
                    cylinder(d=2,20);
                    }
                }
                translate([3*Thick+5,Width+5,TopHeight+4]){
                    rotate([90,0,0]){
                    cylinder(d=2,20);
                    }
                }
                translate([Length-((3*Thick)+5),Width+5,TopHeight+4]){
                    rotate([90,0,0]){
                    cylinder(d=2,20);
                    }
                }
                
                
                translate([Thick/2,(Width/2)-Thick/2-2.4,TopHeight+4]){
                    rotate([90,0,90]){
                    cylinder(d=2,20);
                    }
                }
                translate([Length-Thick-0.5,(Width/2)-Thick/2-2.4,TopHeight+4]){
                    rotate([90,0,90]){
                    cylinder(d=2,20);
                    }
                }
                
            }

         // Serial Opening    
            translate([-1,(Thick)+245,Thick]){
              cube([20,20,BottomHeight-9]);
            }   
            
        // Joystick Opening    
            translate([96,20,Thick]){    
              cube([20,Width+2,BottomHeight-9]);
            }
            translate([137,20,Thick]){    
              cube([20,Width+2,BottomHeight-9]);
            }

         // Power Switch Opening    
            translate([45,Thick-10,Thick-13]){
              cube([20,13,13]);
            }   


         // Reset Switch Opening    
            translate([85,(Thick),Thick-7]){
             rotate([90,0,0])
                    cylinder(d=7,20);
            }   


        // Power Jack Opening    
            translate([-1,(Thick)+355,Thick-7]){
             rotate([0,90,0])
                    cylinder(d=11,20);
            }
                
       
        // Audio and Video RCA Jack Openings    
            translate([-1,(Thick)+305,Thick-7]){
             rotate([0,90,0])
                    cylinder(d=7,20);
            }   
             translate([-1,(Thick)+320,Thick-7]){
             rotate([0,90,0])
                    cylinder(d=7,20);
            }   
             translate([-1,(Thick)+335,Thick-7]){
             rotate([0,90,0])
                    cylinder(d=7,20);
            }   



        KeyboardCutout();

        }//fin de difference holes
        KeyboardFeet();
        
   // Reset Switch Opening    
          //  translate([85,(Thick),Thick-7]){
           //  rotate([90,0,0])
             //       cylinder(d=7,20);
            //}   
        
        

}// fin coque
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

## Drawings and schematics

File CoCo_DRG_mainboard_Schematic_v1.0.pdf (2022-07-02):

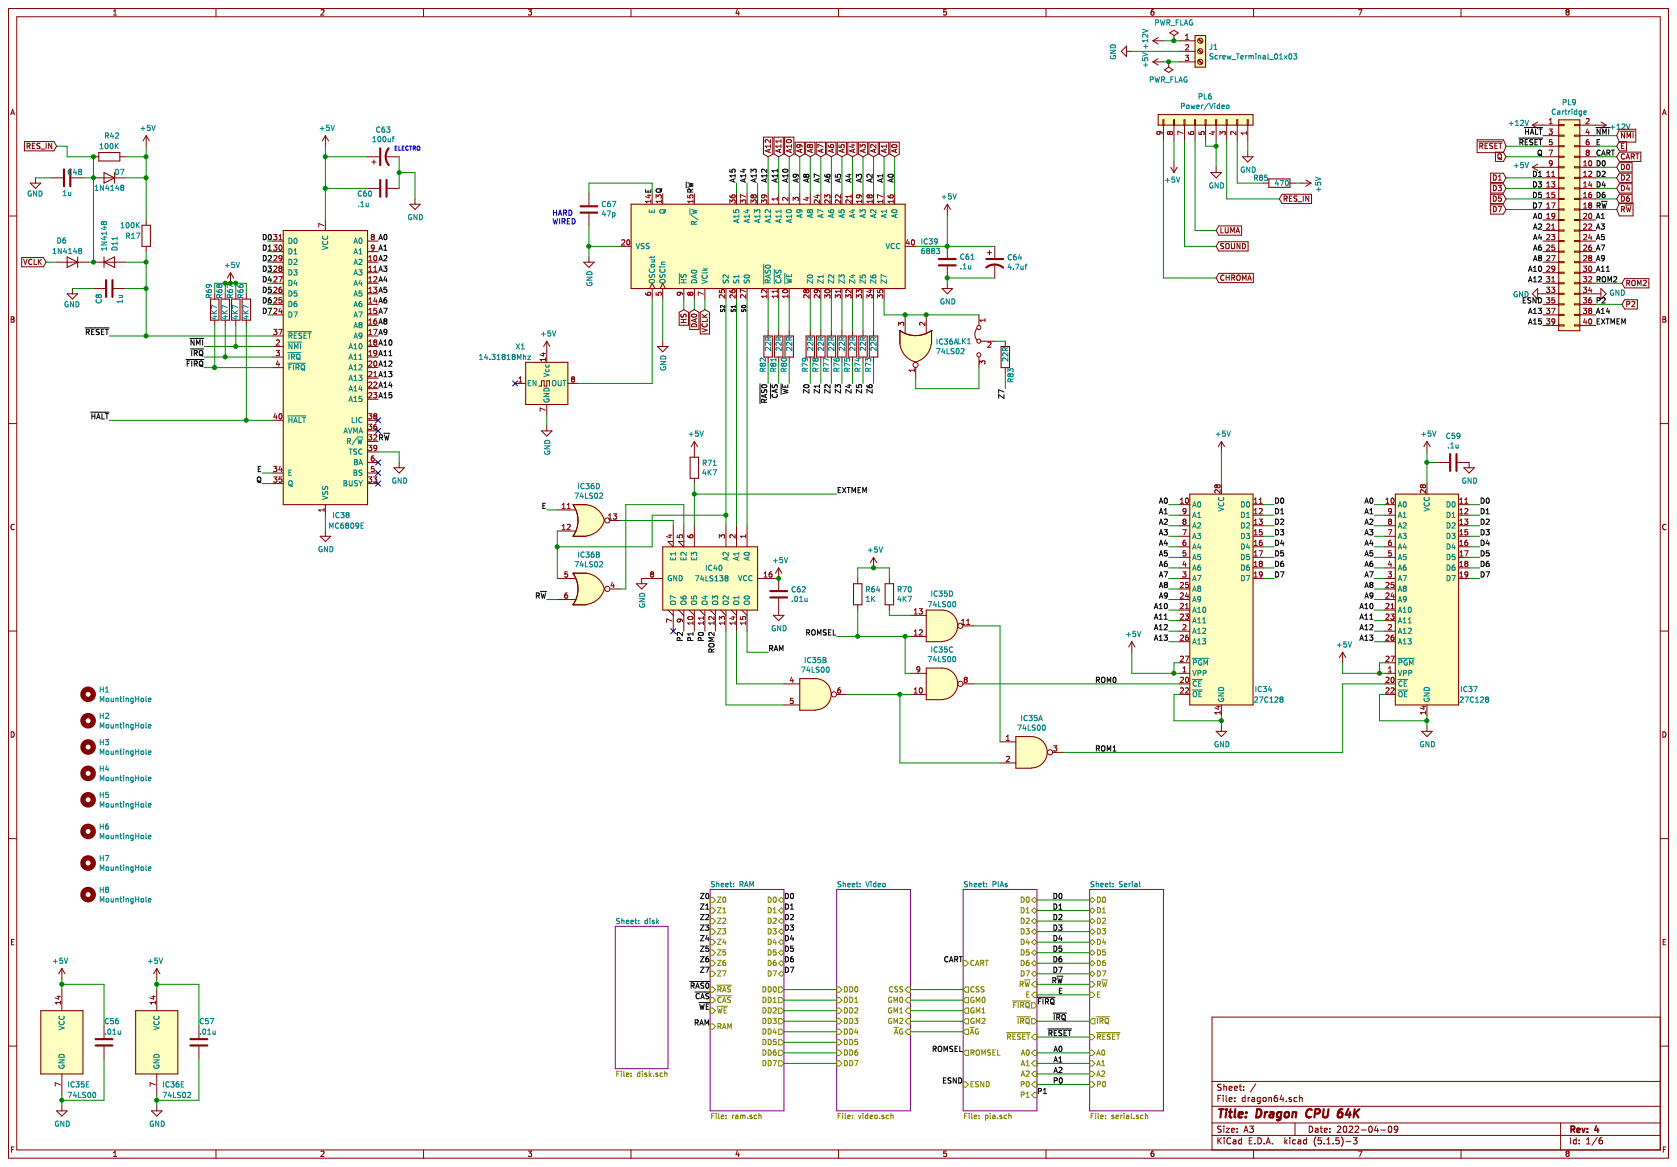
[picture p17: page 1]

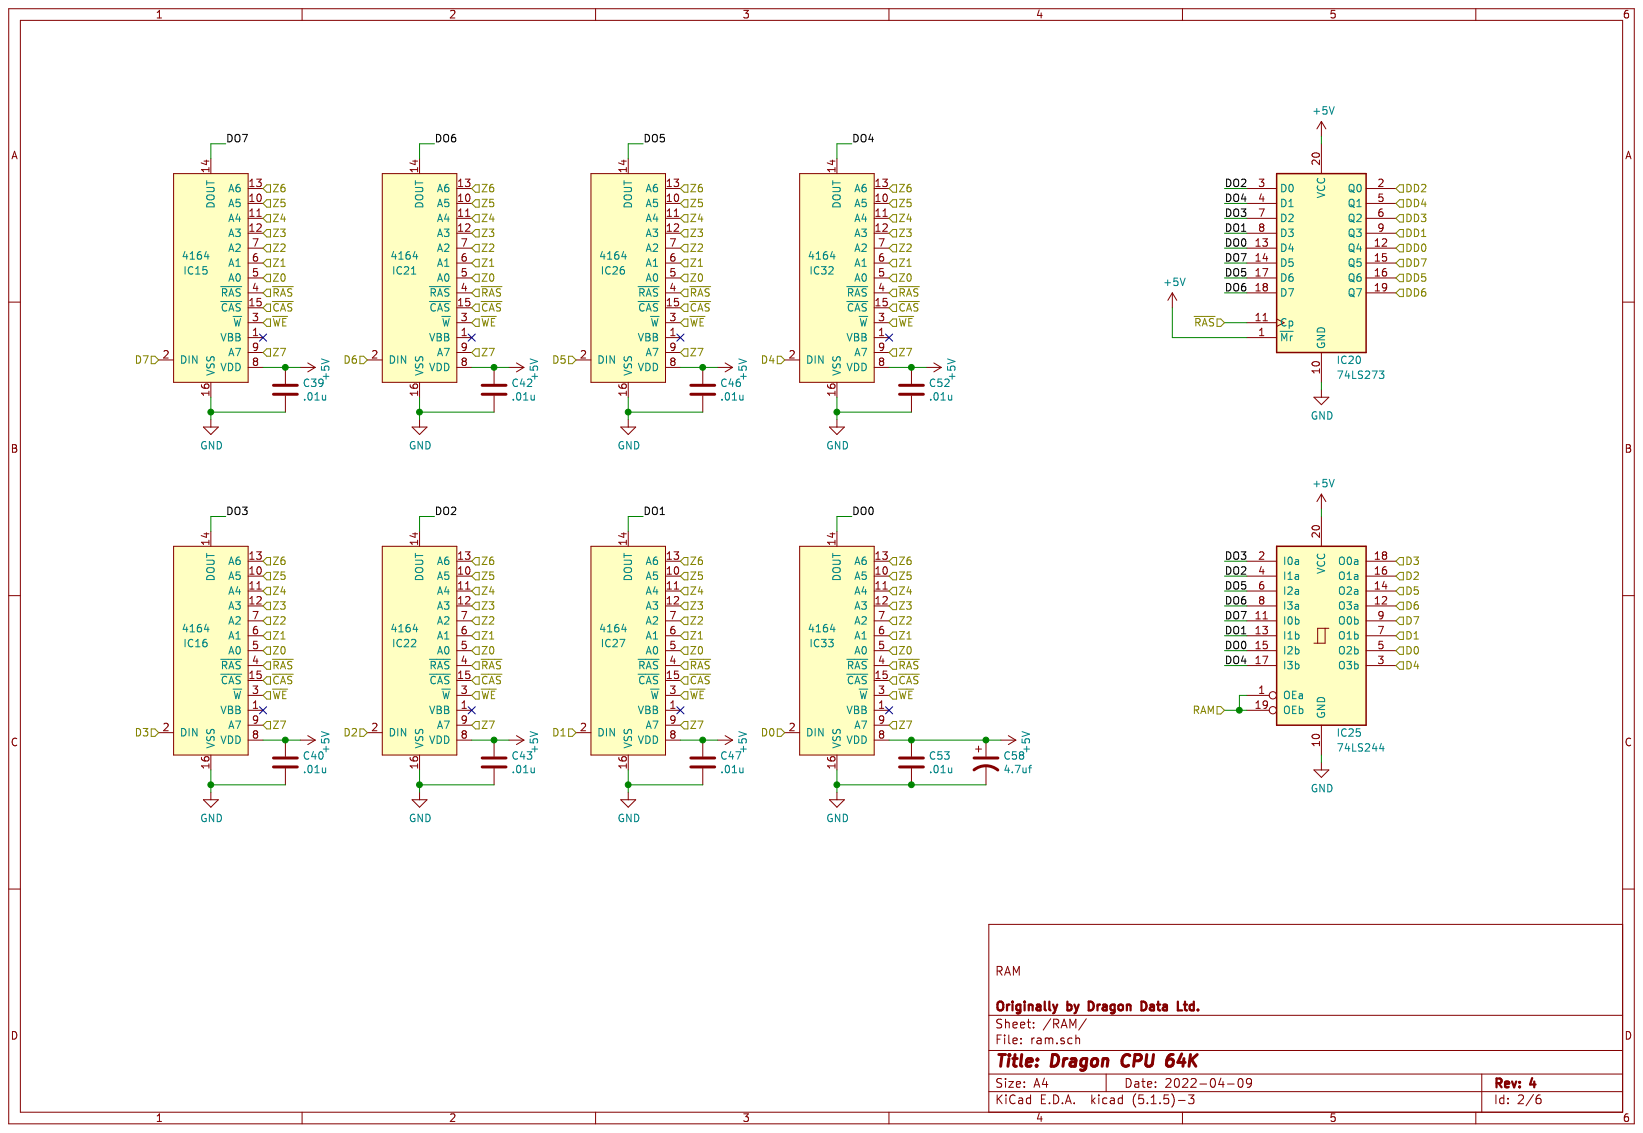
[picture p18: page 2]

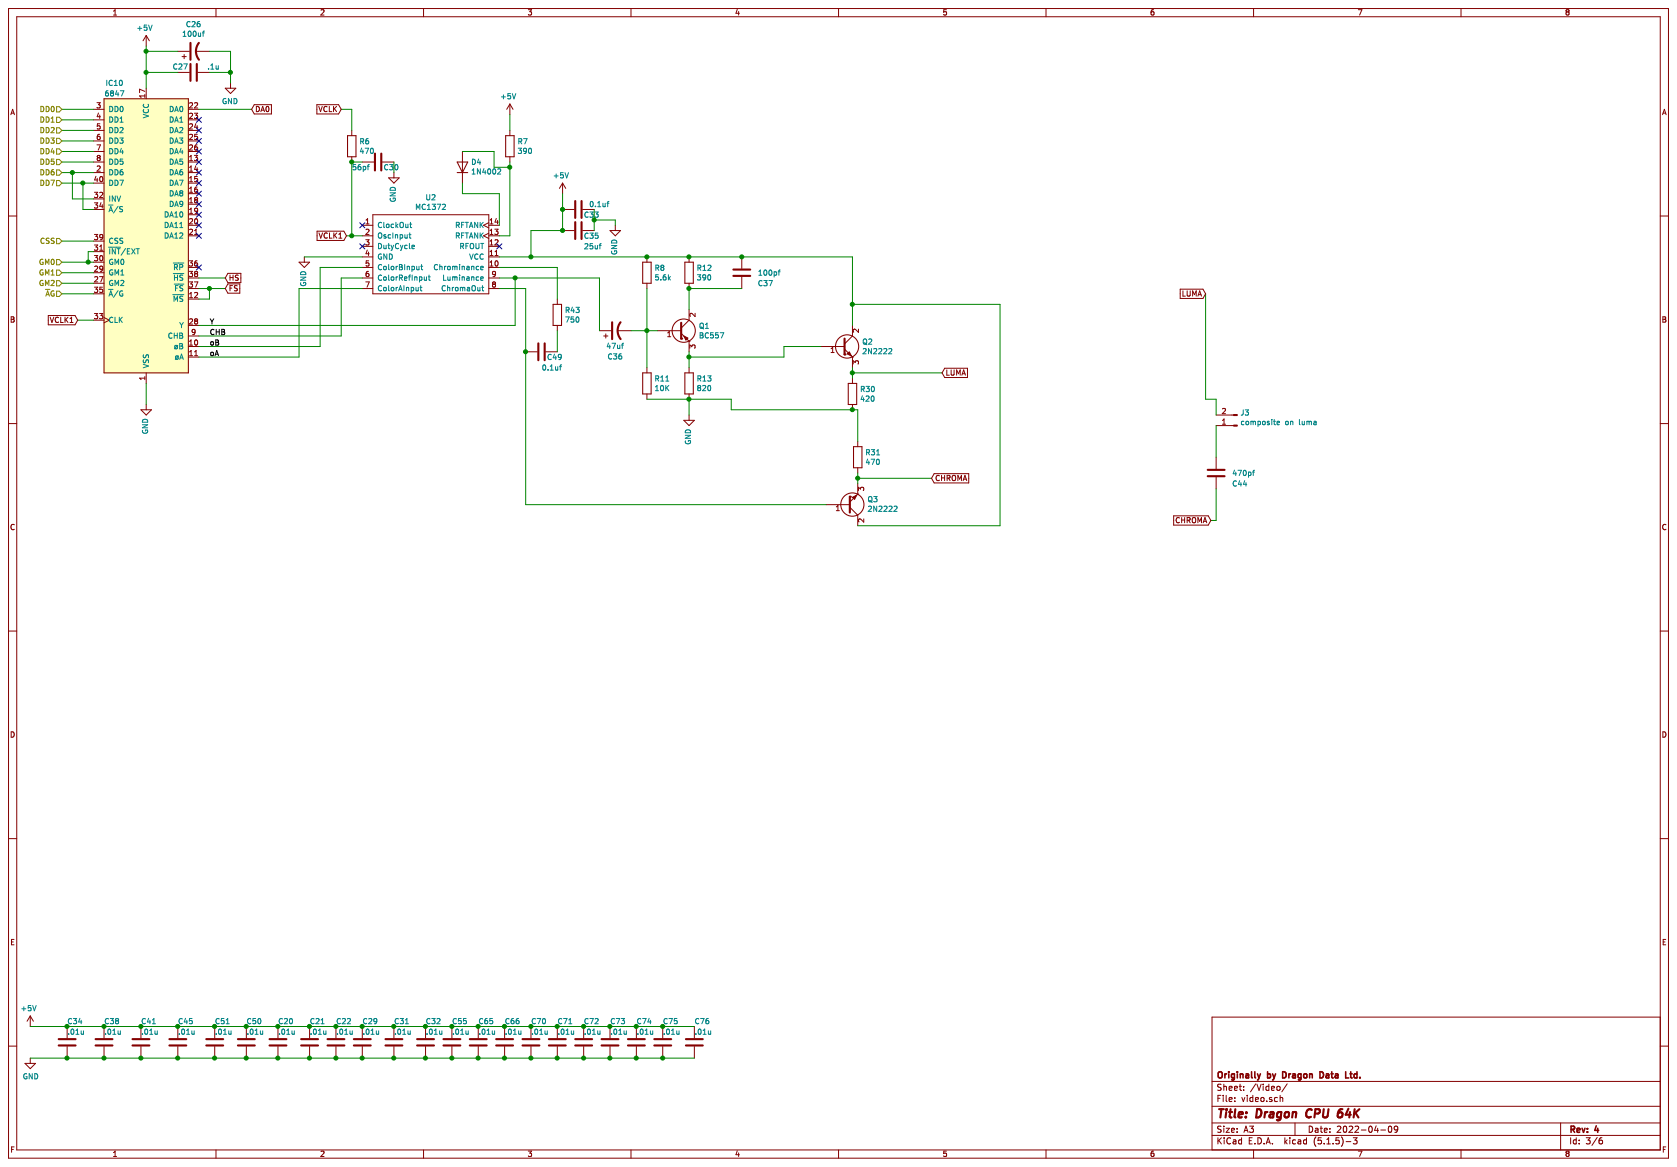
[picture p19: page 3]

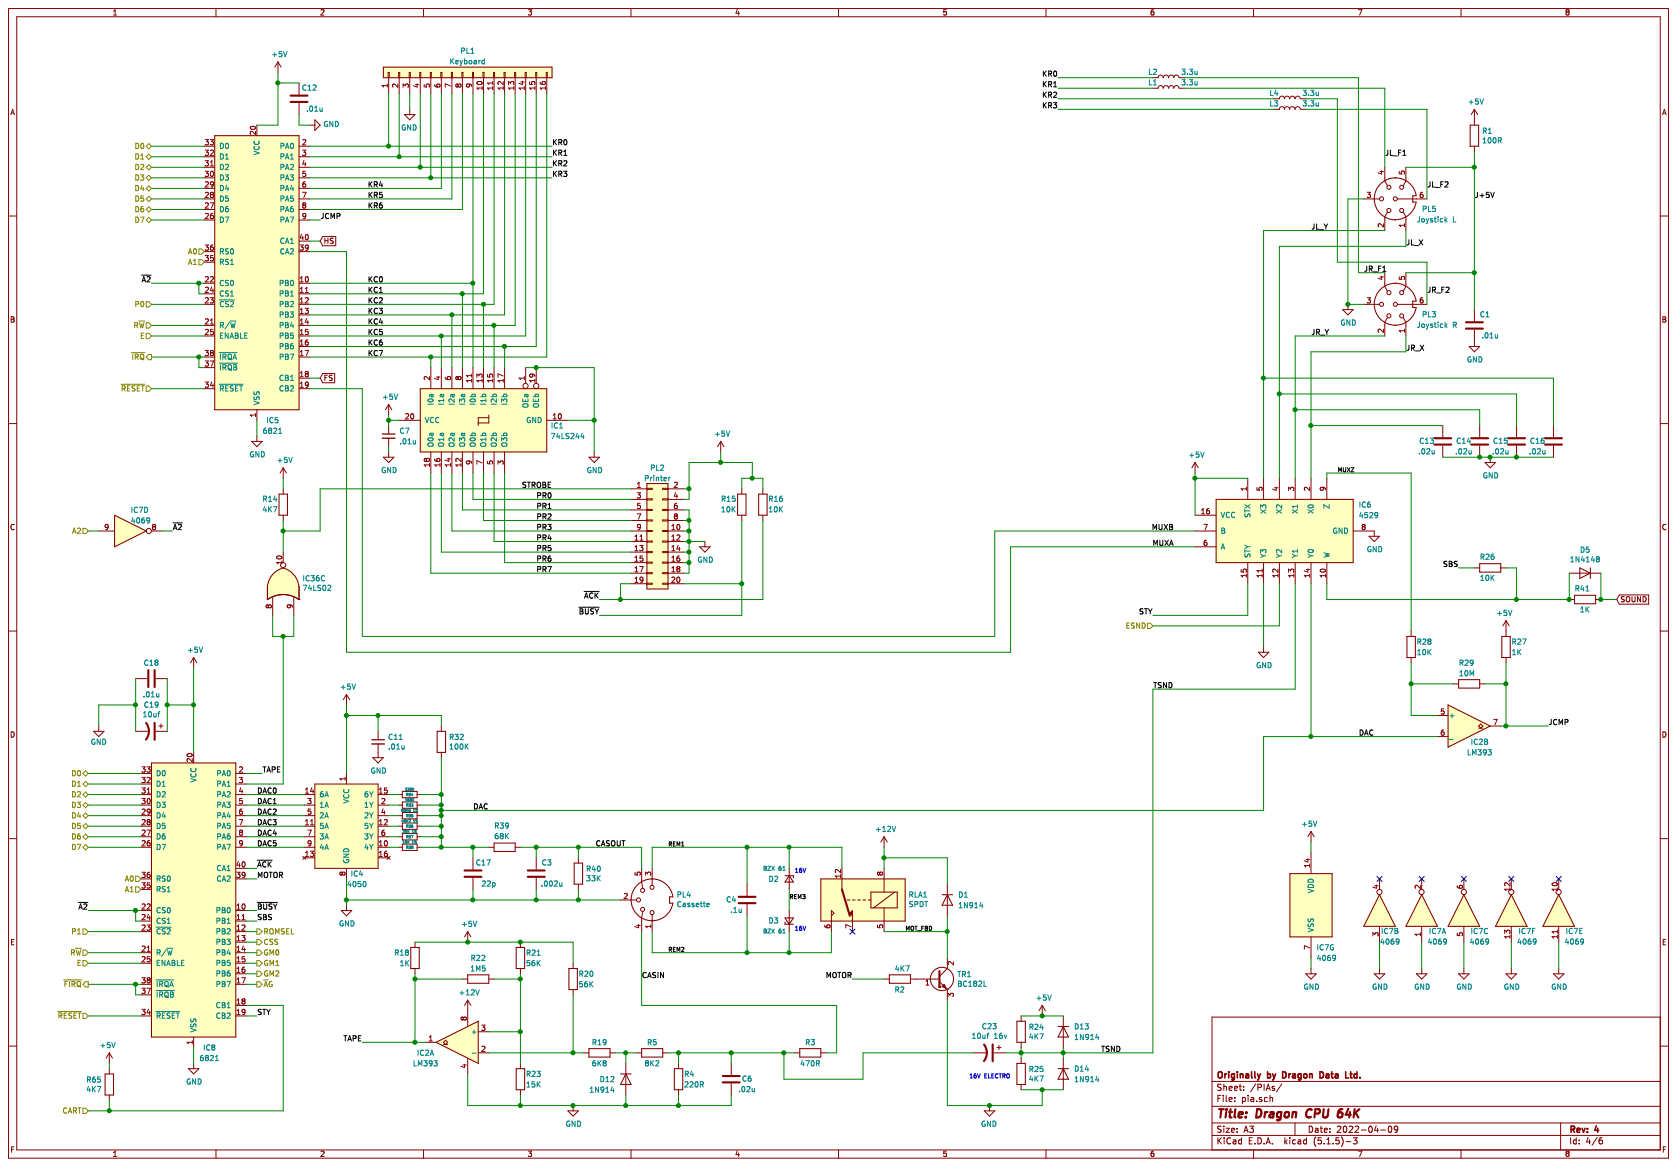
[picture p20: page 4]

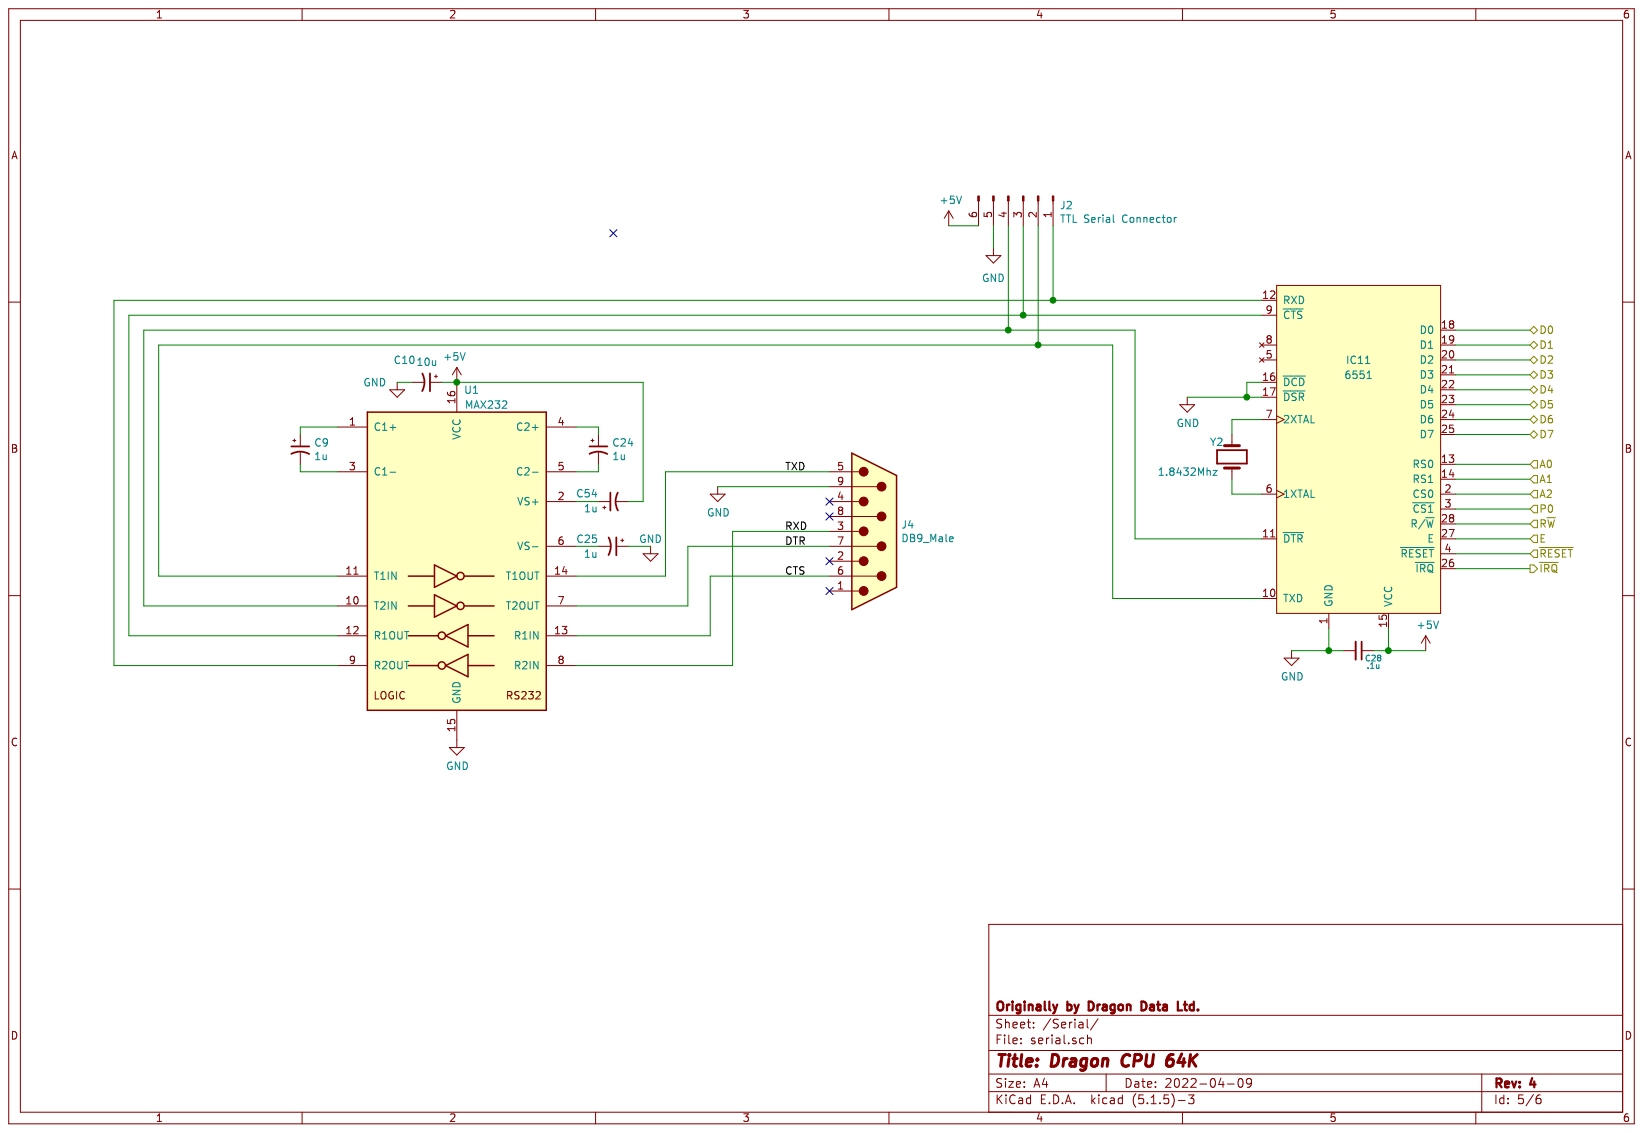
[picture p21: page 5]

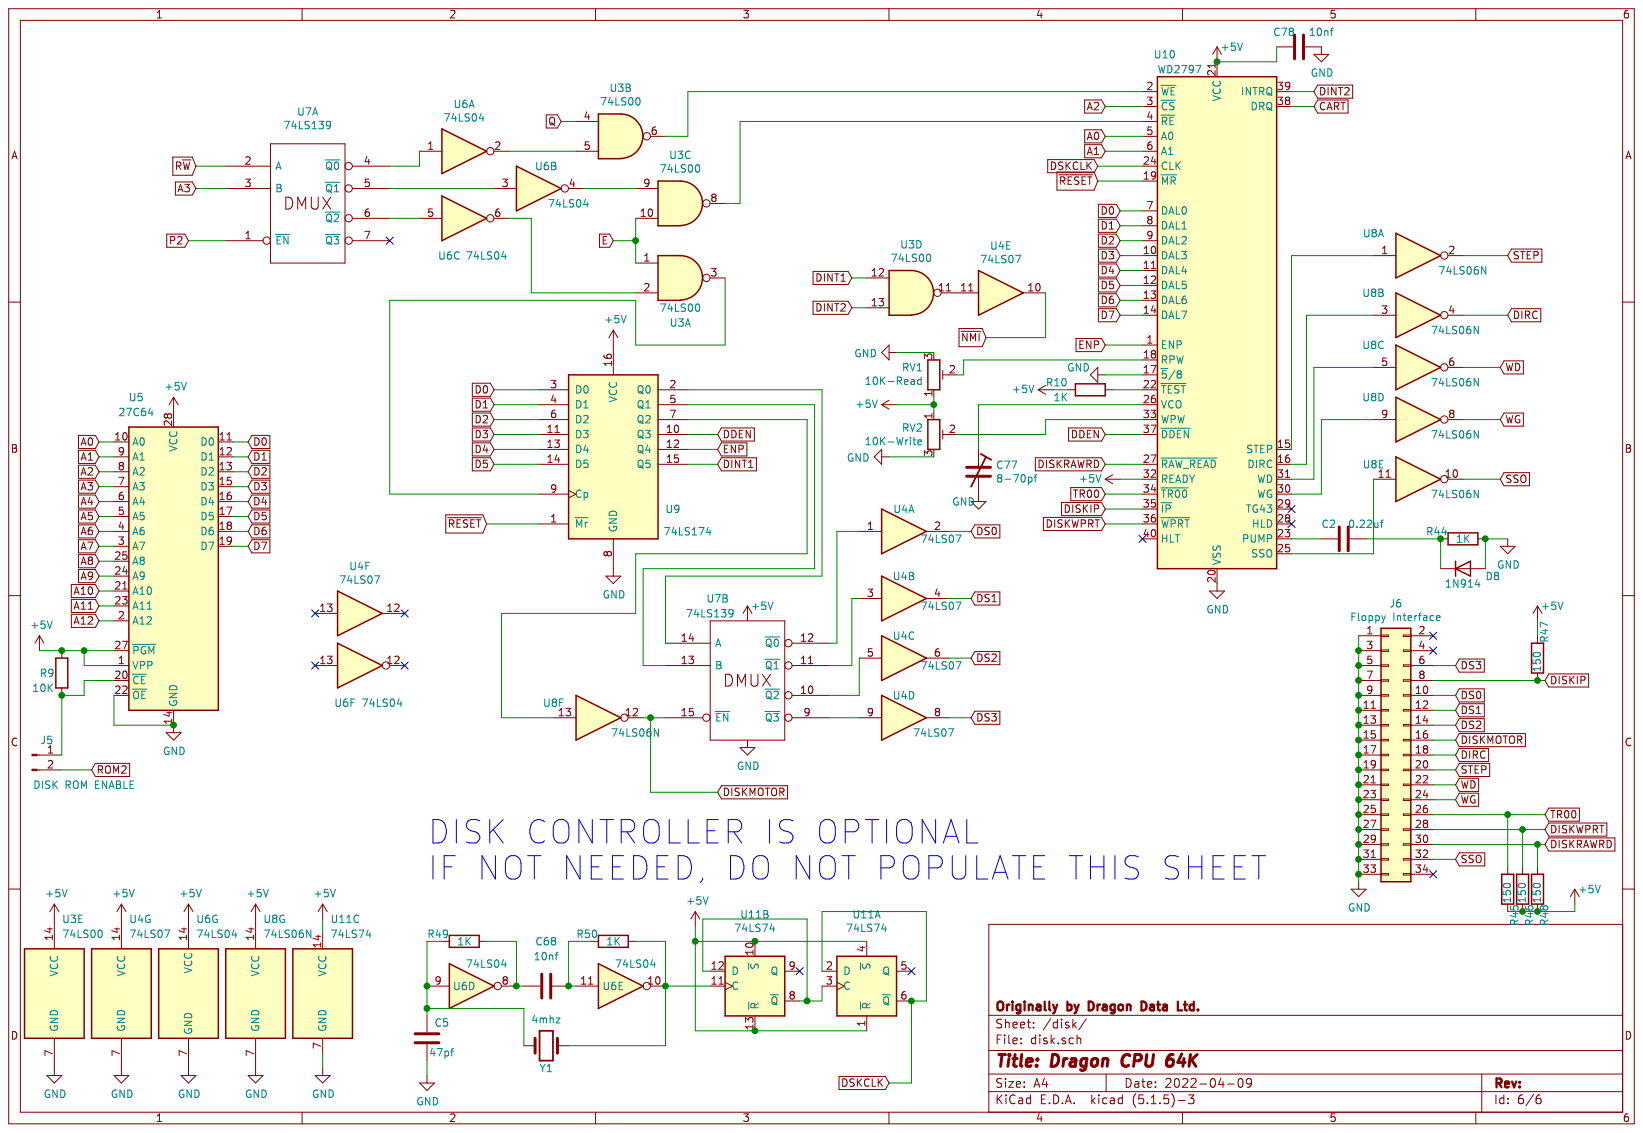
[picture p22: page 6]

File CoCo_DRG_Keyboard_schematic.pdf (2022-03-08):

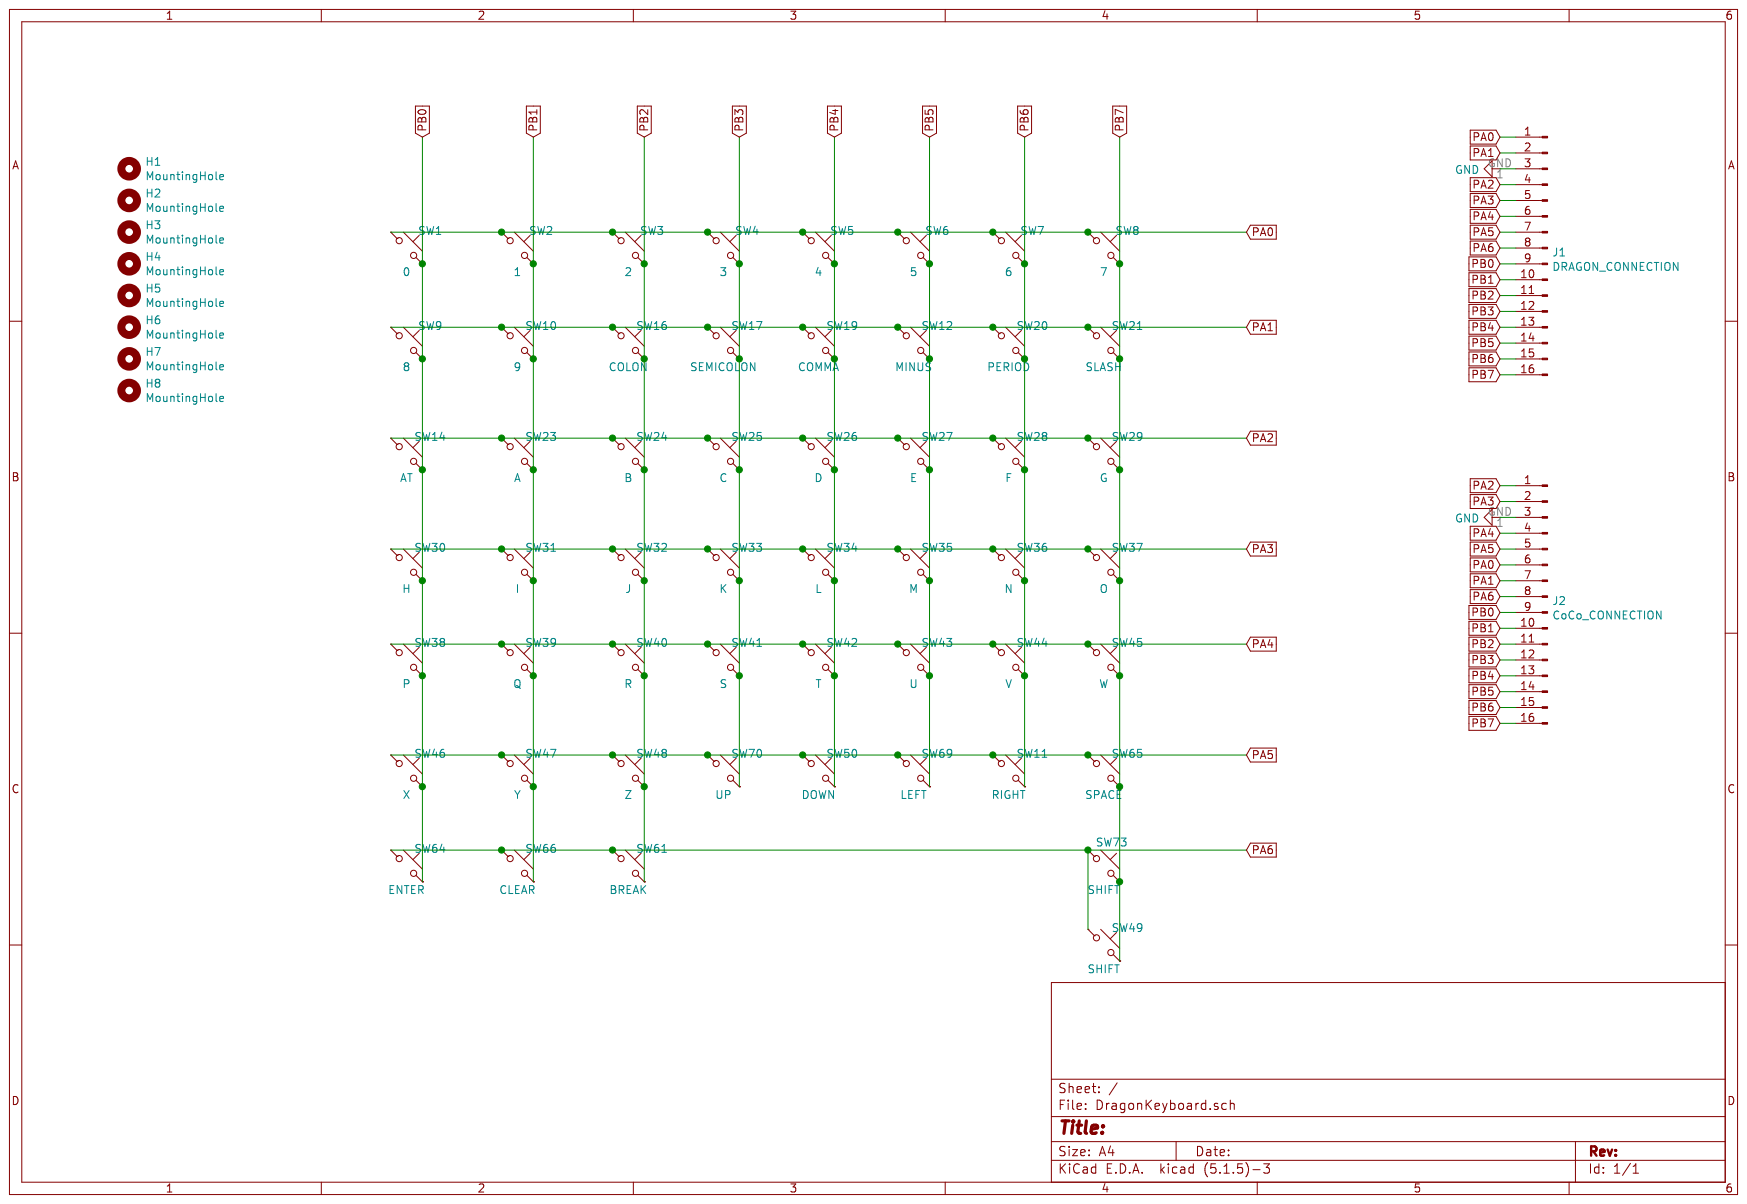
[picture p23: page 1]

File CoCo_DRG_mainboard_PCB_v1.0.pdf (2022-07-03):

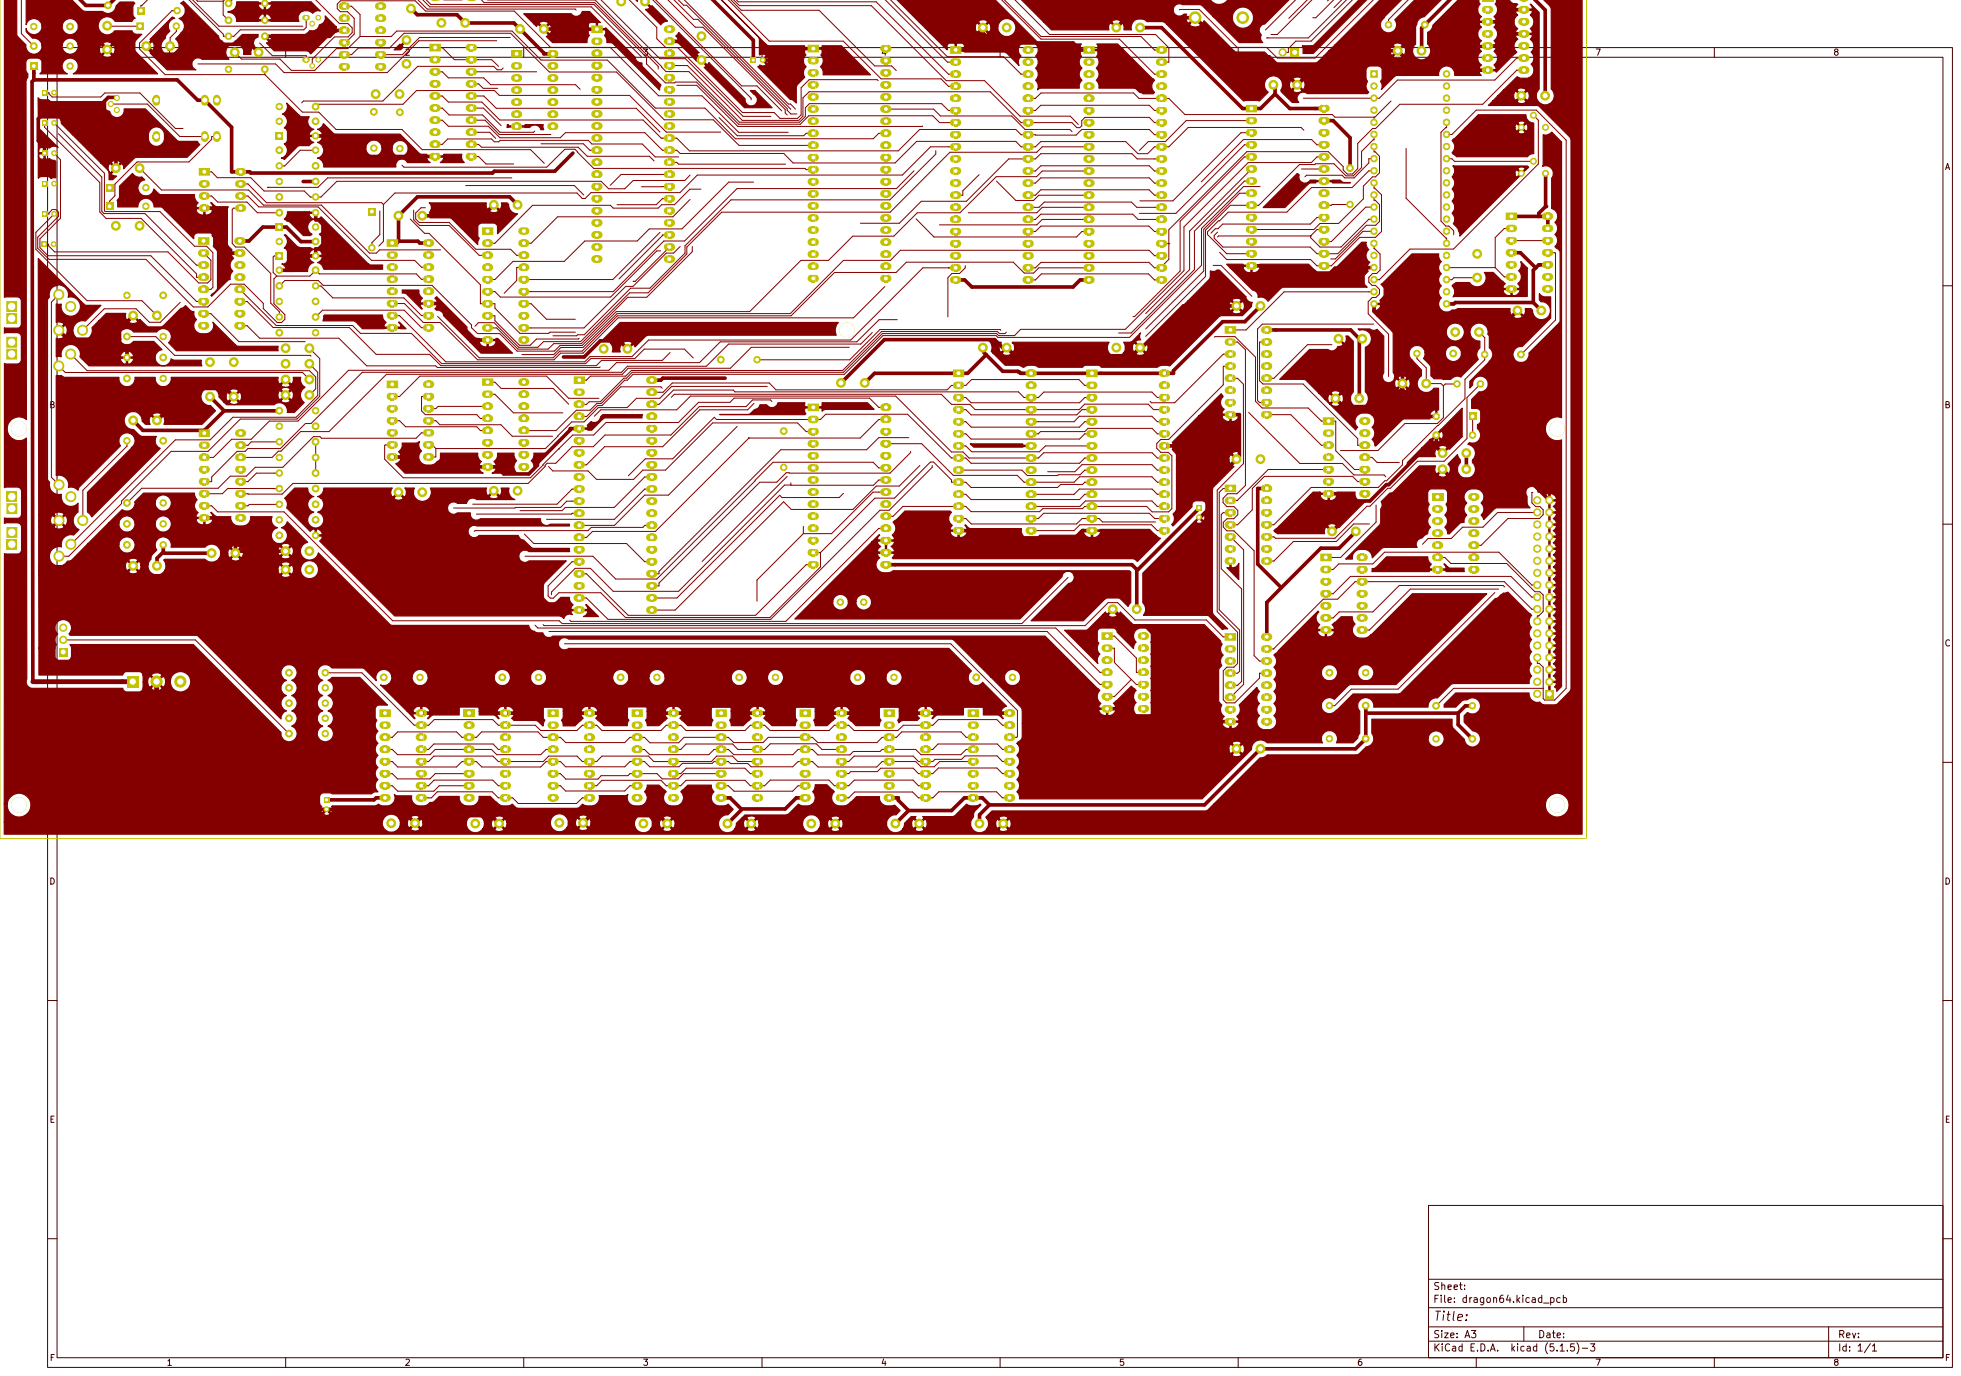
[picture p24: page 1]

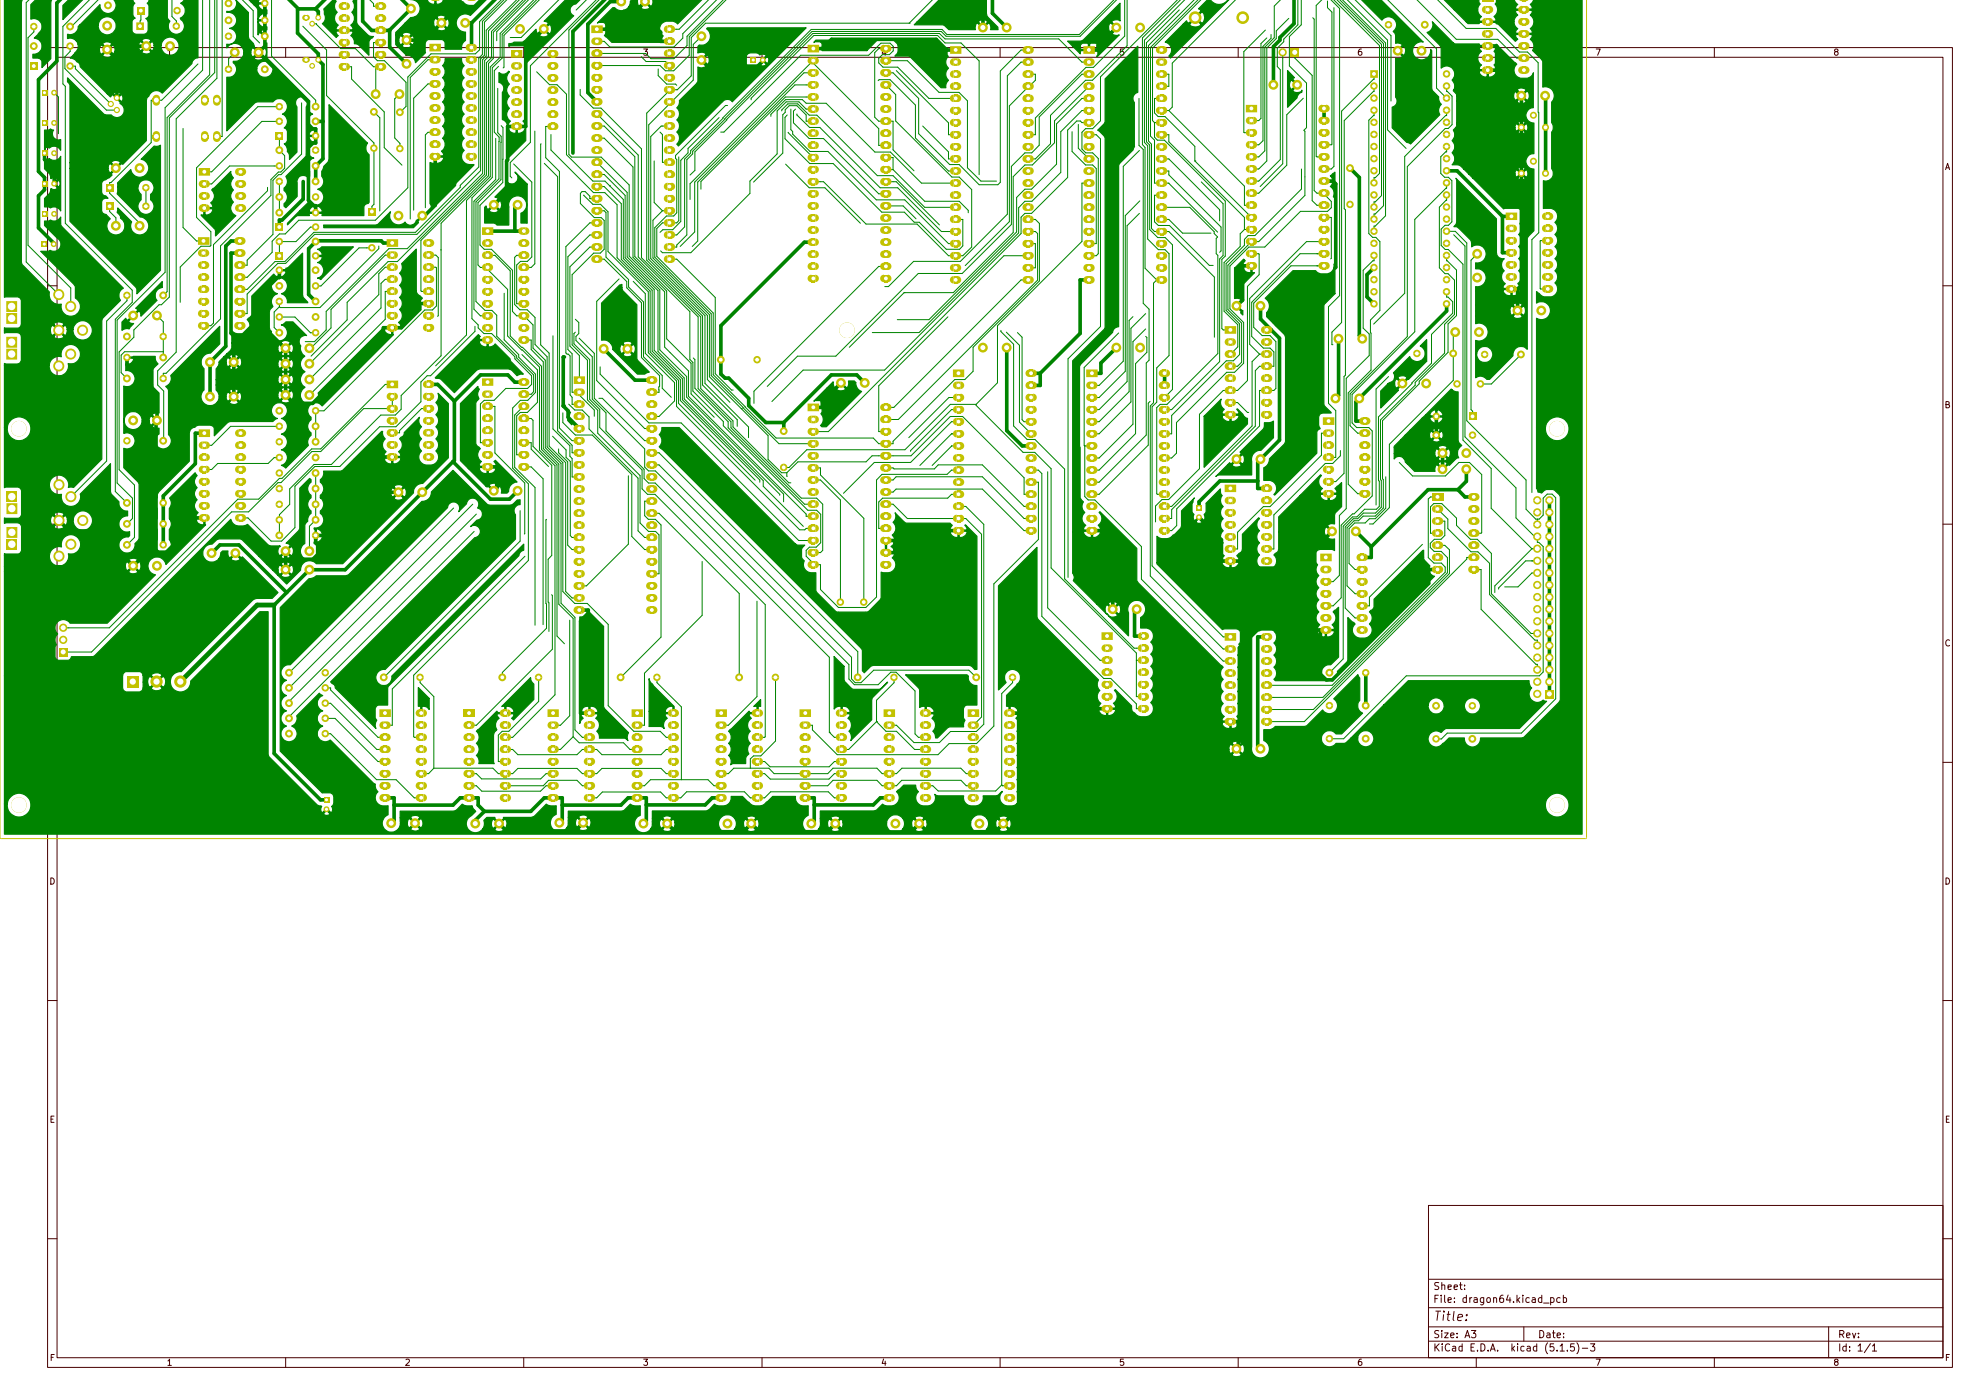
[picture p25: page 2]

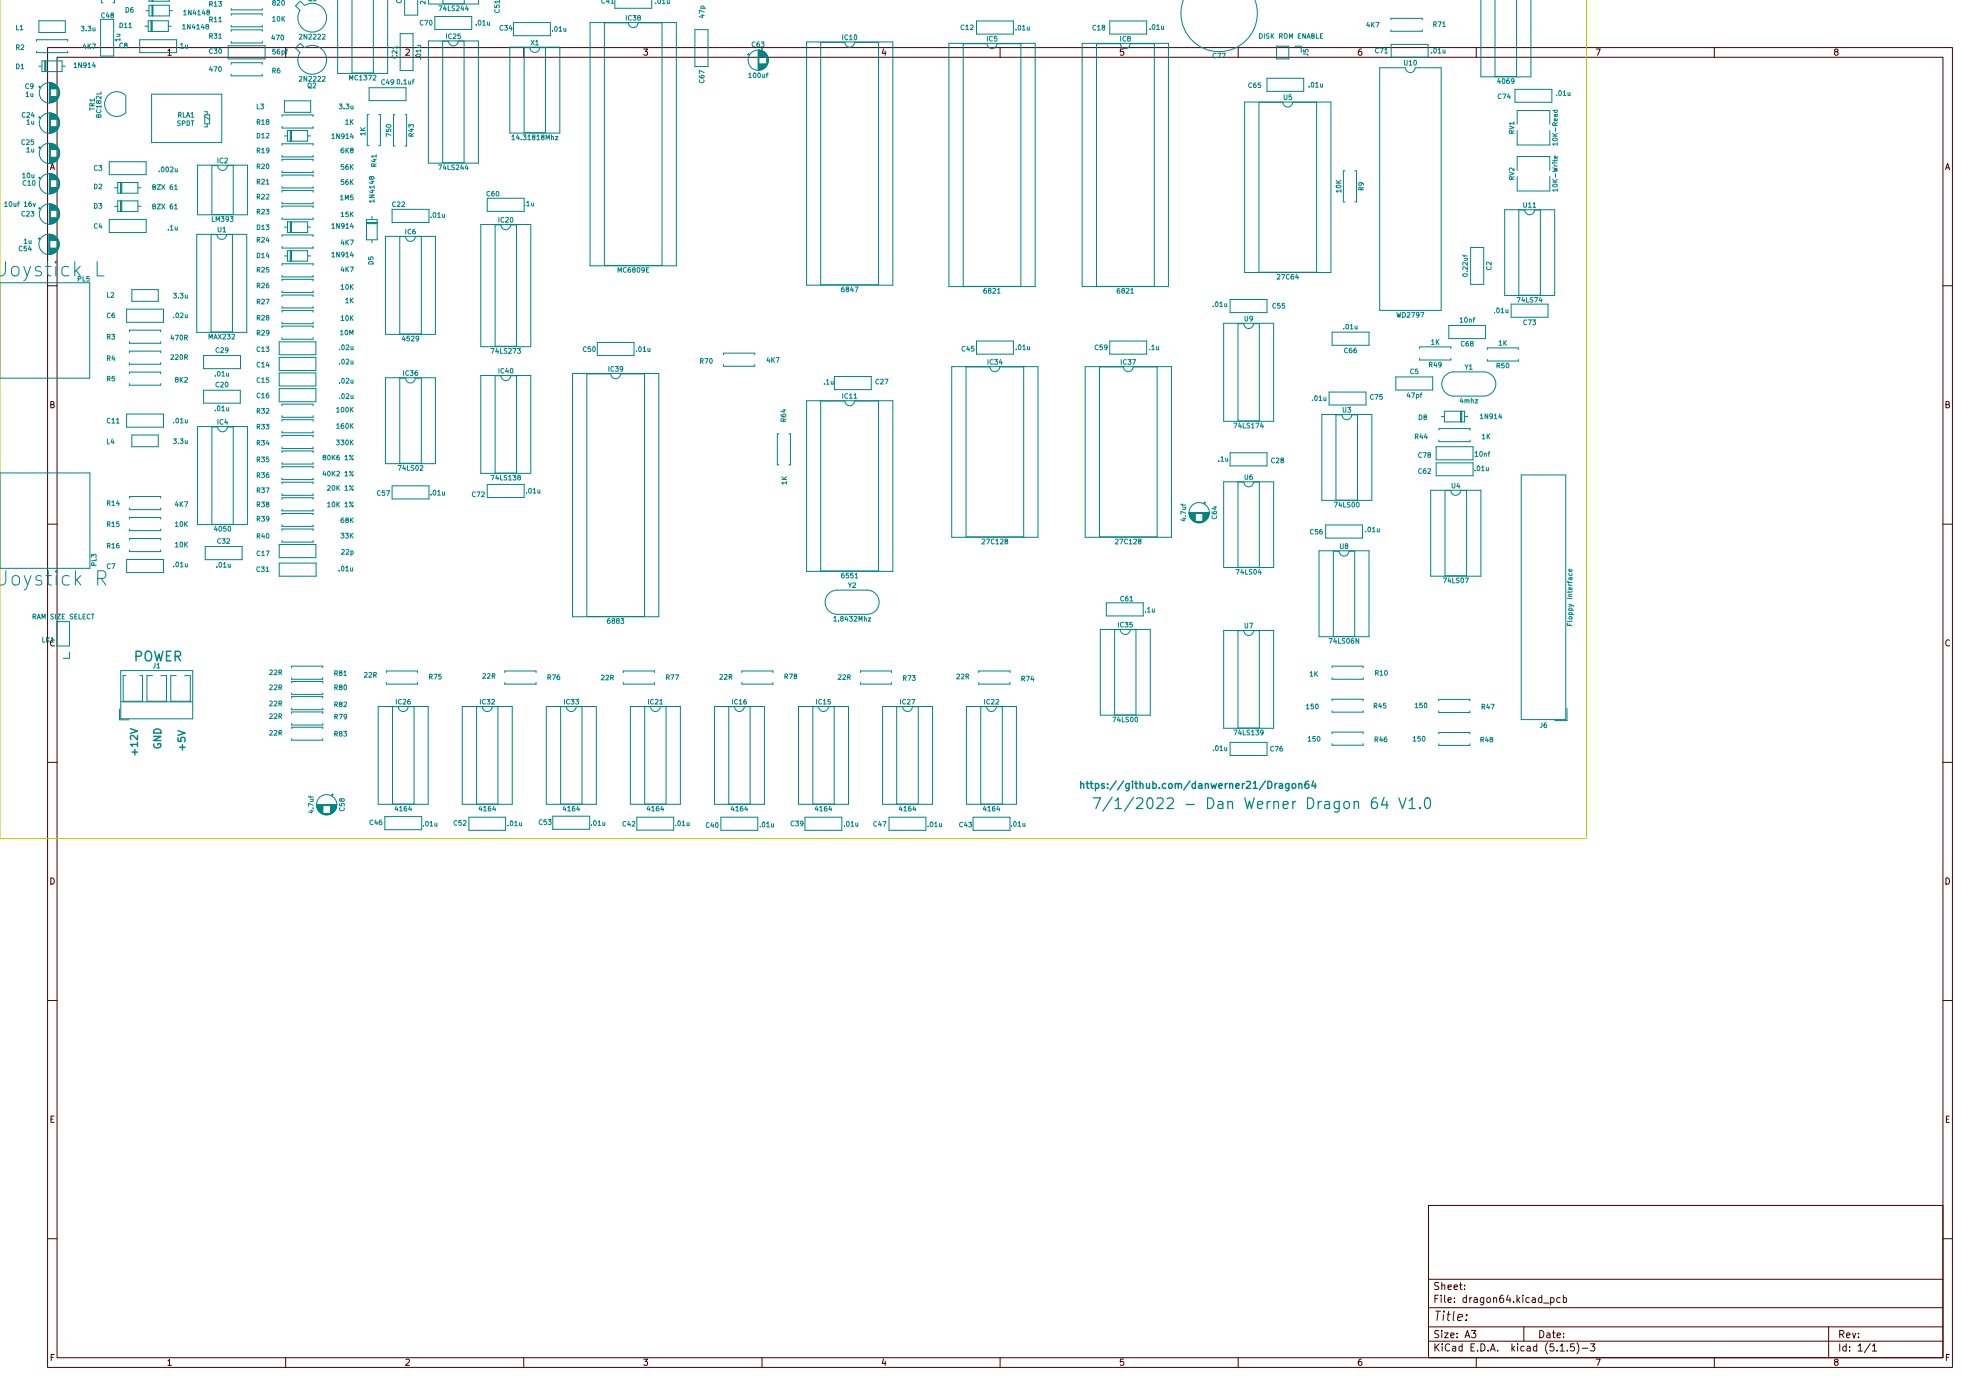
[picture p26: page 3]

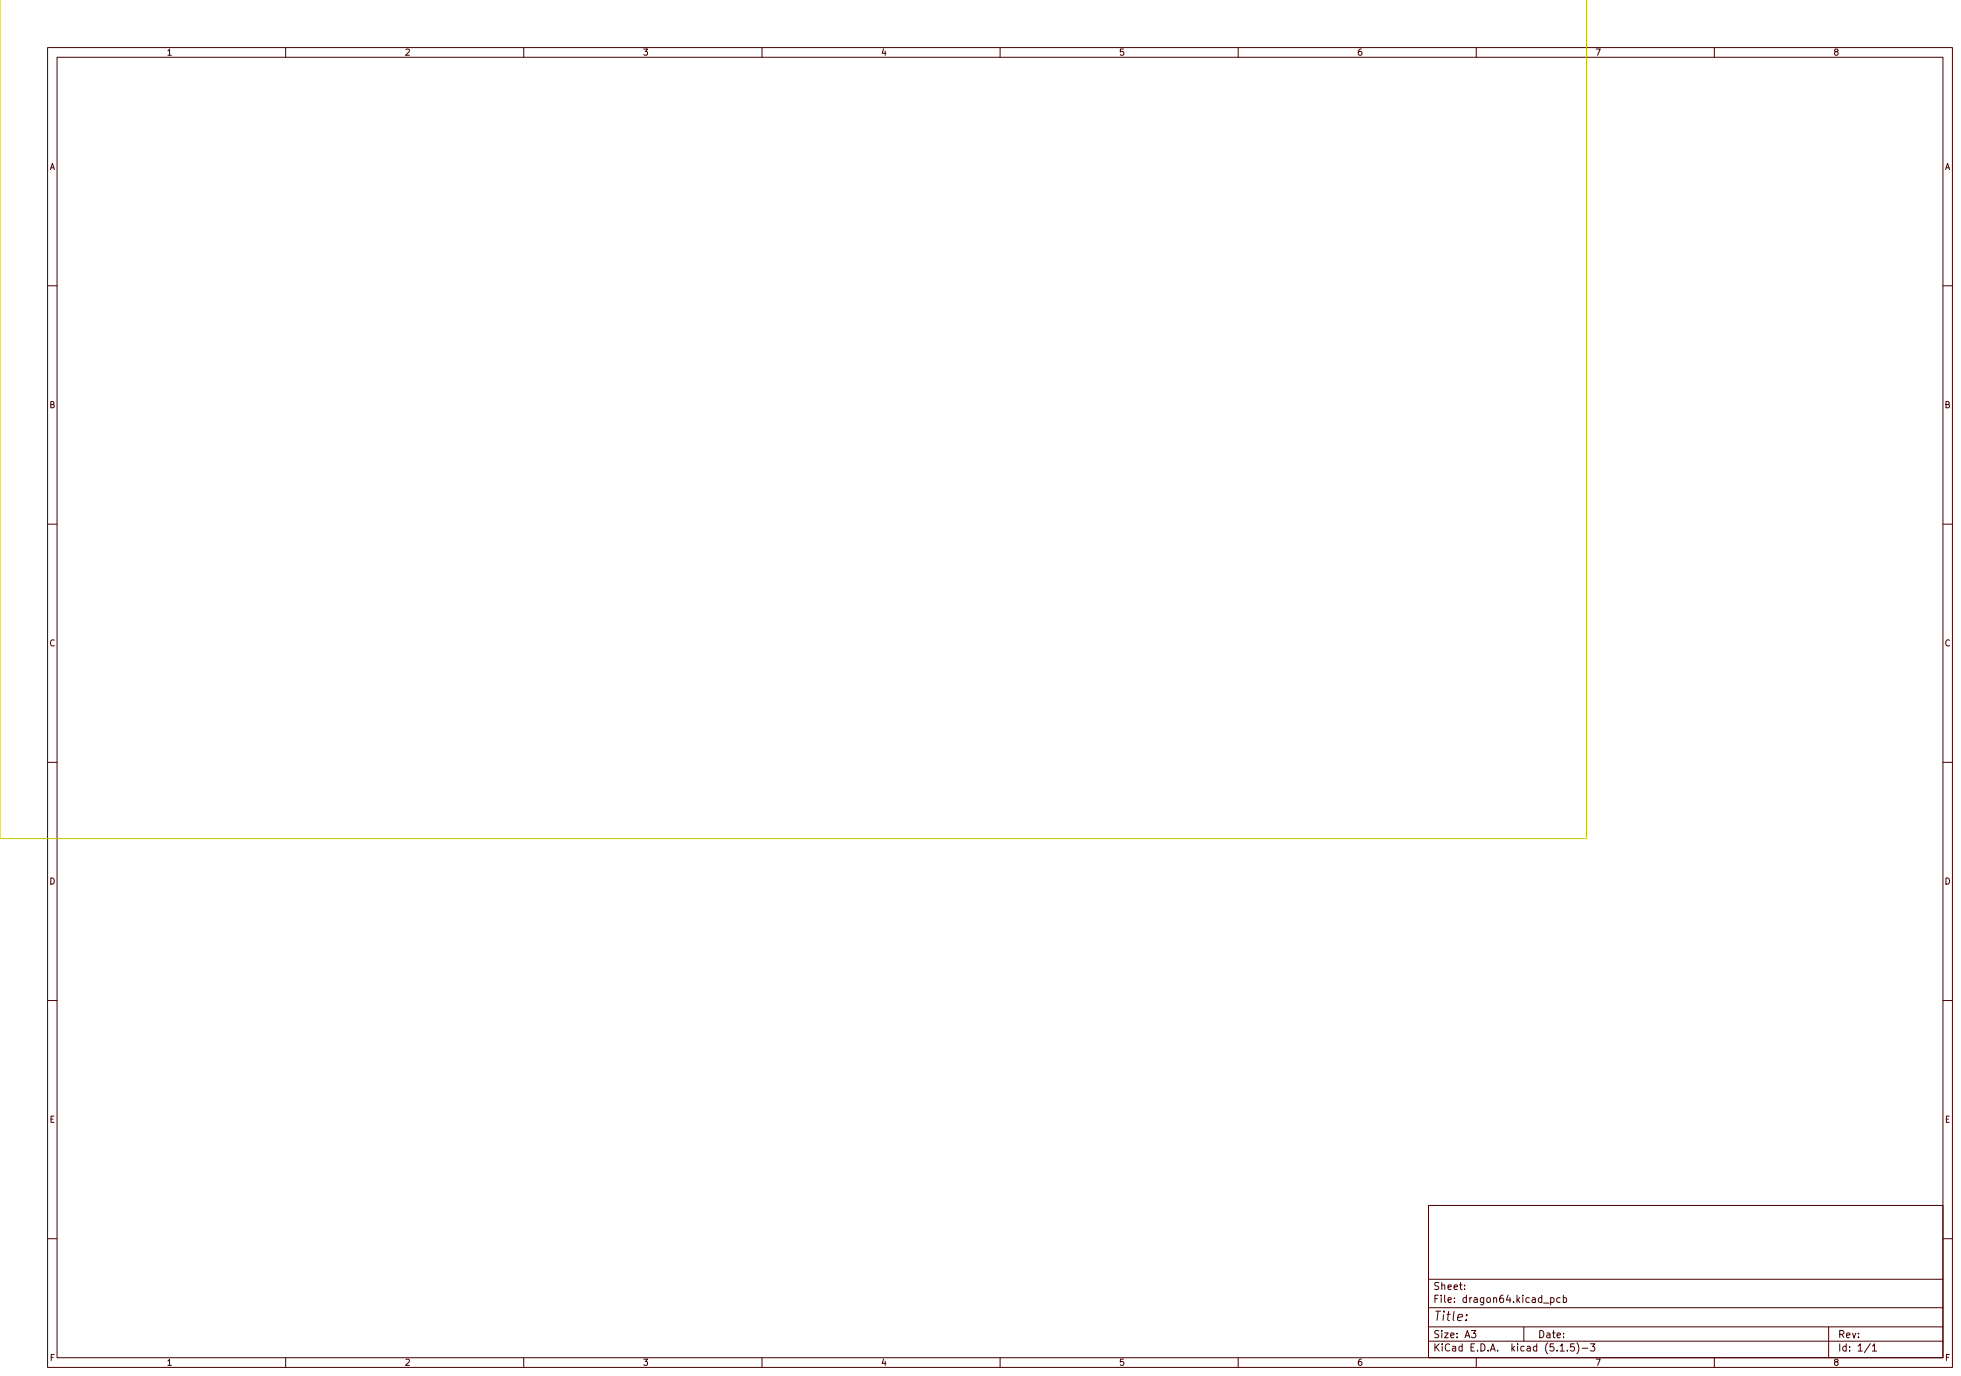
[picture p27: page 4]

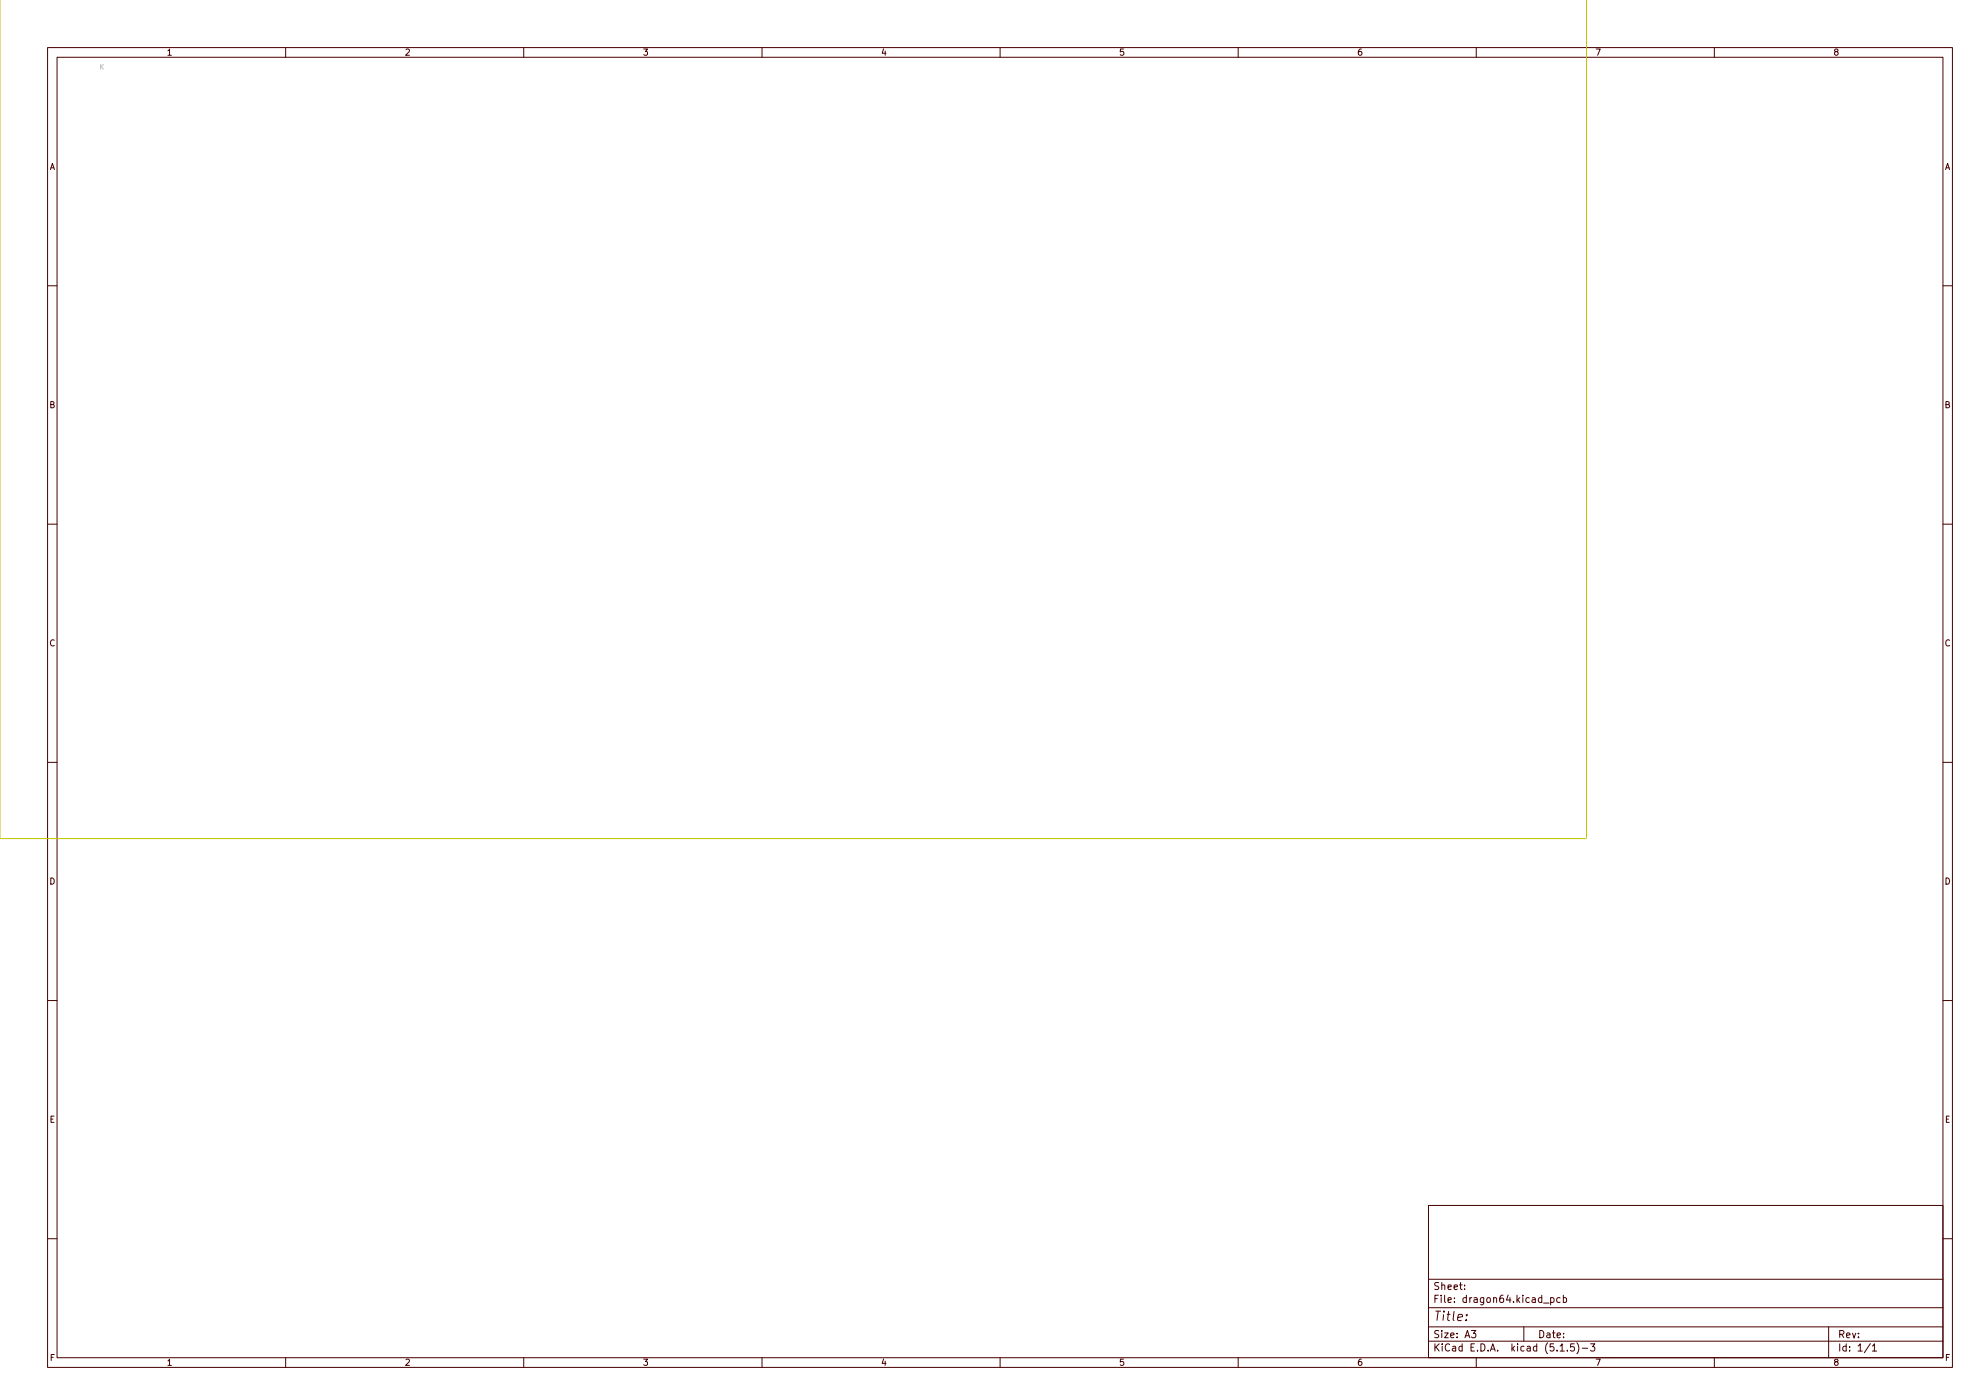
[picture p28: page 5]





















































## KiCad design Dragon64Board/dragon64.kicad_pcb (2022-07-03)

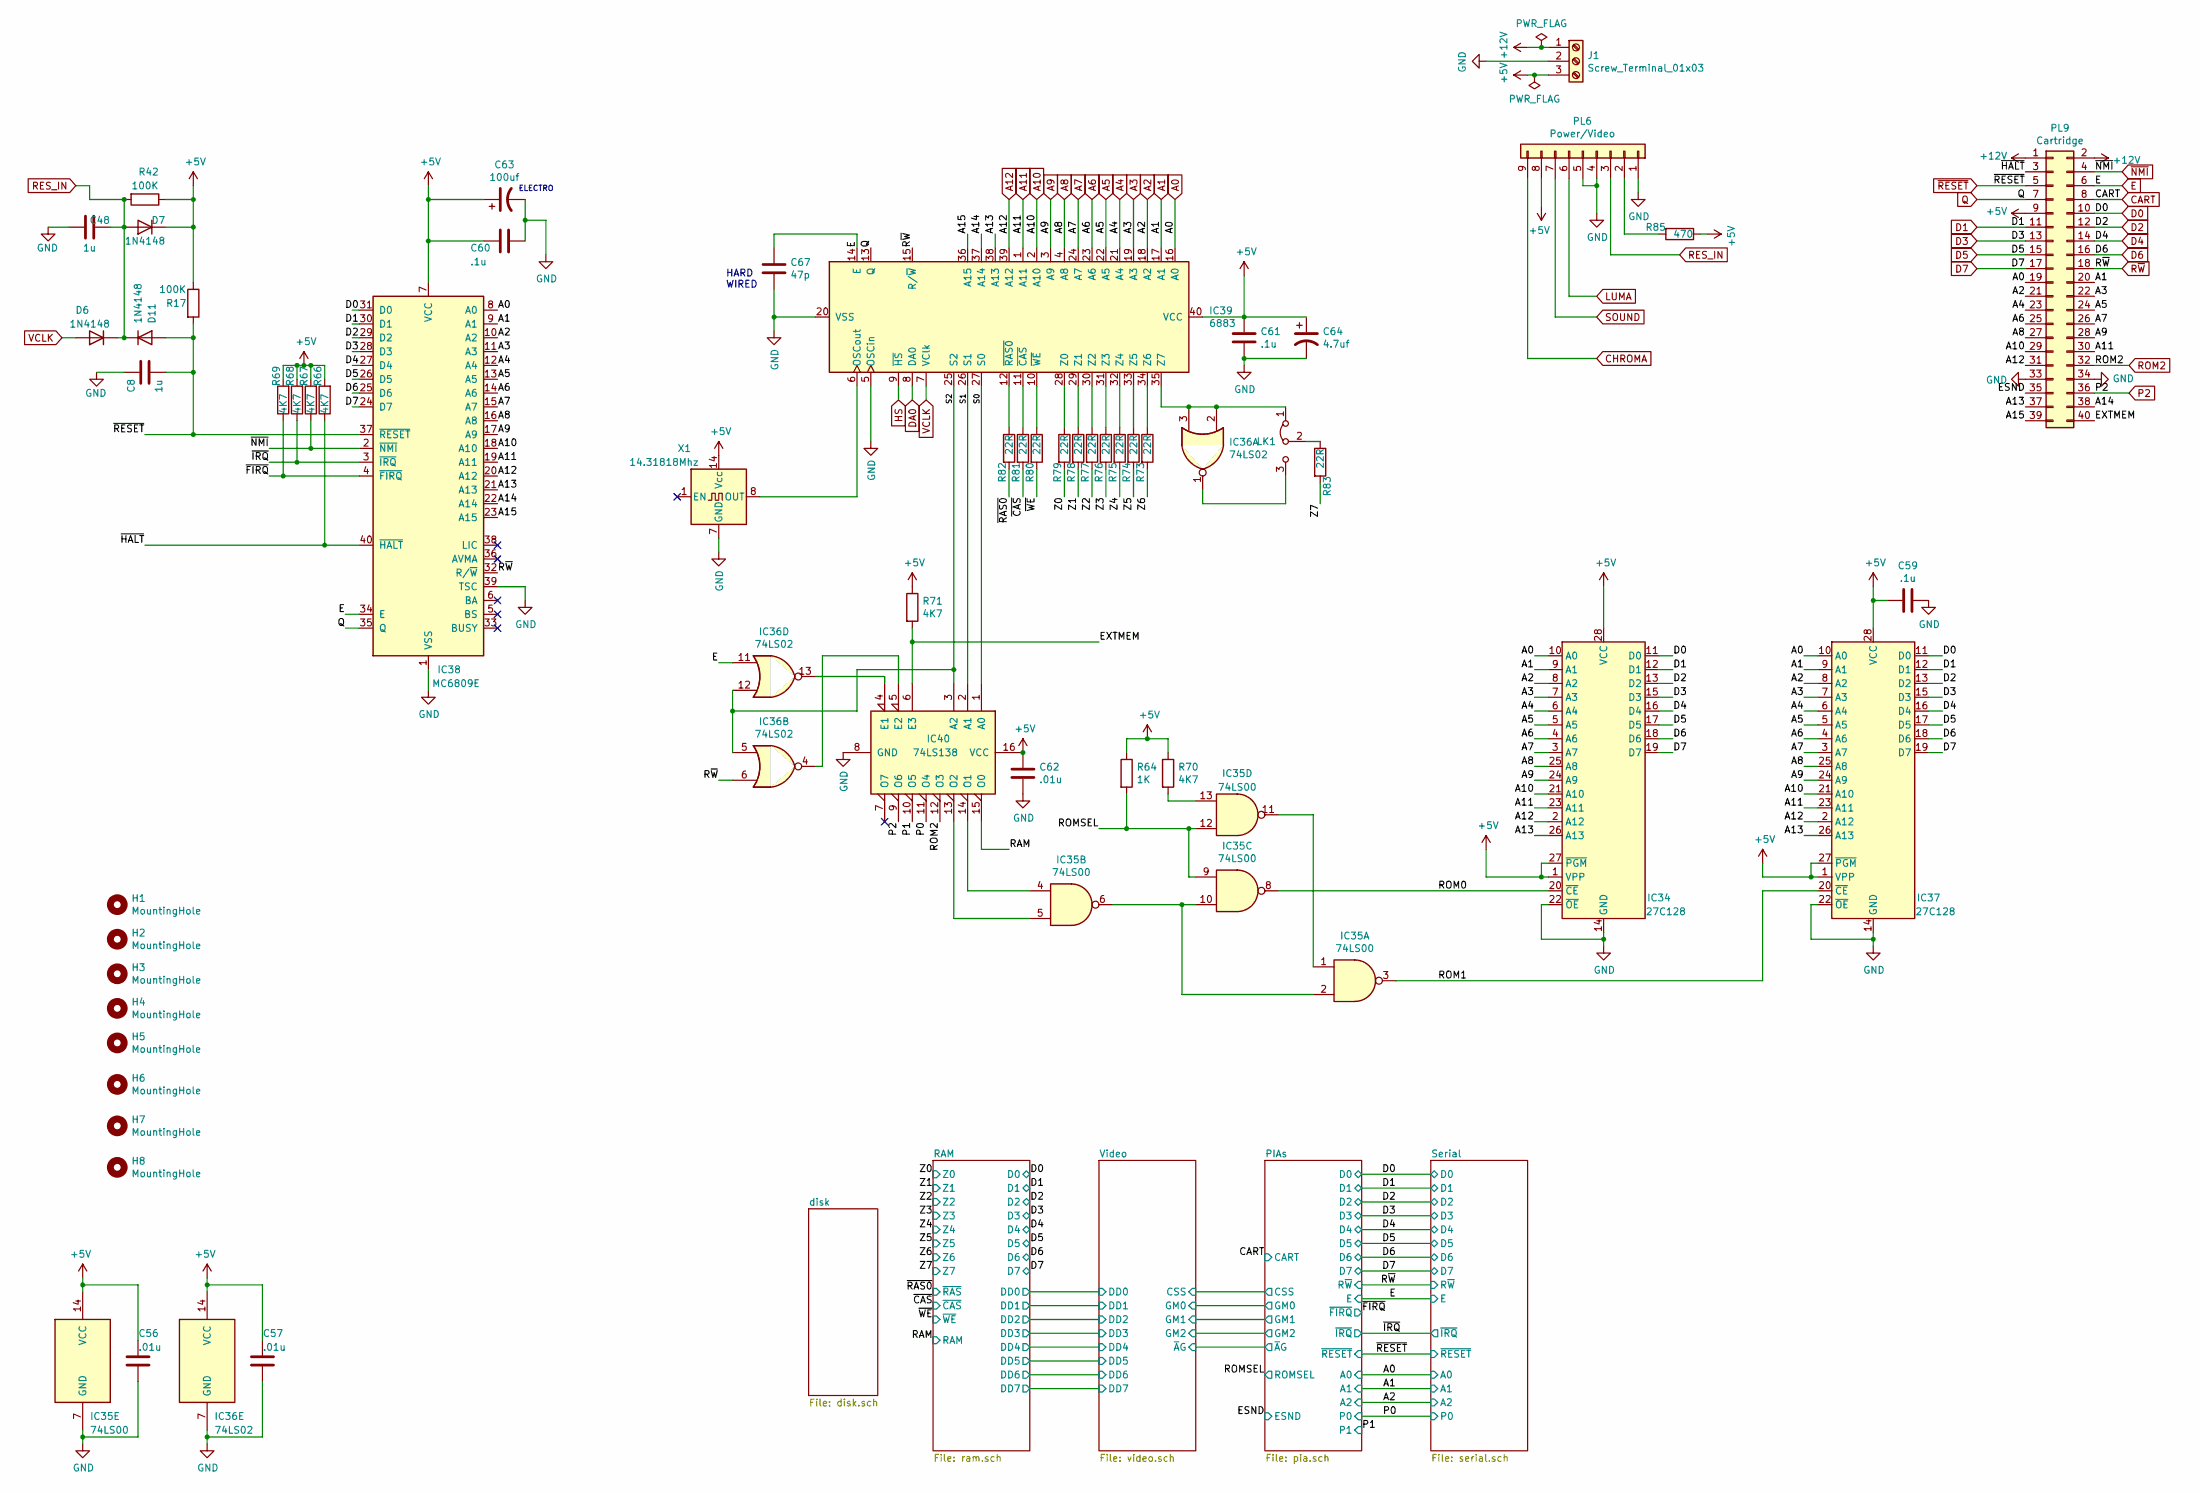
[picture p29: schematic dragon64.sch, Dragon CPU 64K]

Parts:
C8, C48: 1u; C_Disc_D7.5mm_W2.5mm_P5.00mm
C56, C57, C62: .01u; C_Disc_D7.5mm_W2.5mm_P5.00mm
C59, C60, C61: .1u; C_Disc_D7.5mm_W2.5mm_P5.00mm
C63: 100uf; CP_Radial_D4.0mm_P2.00mm
C64: 4.7uf; CP_Radial_D4.0mm_P2.00mm
C67: 47p; C_Disc_D7.5mm_W2.5mm_P5.00mm
D6, D7, D11: 1N4148; D_DO-35_SOD27_P7.62mm_Horizontal
H1, H2, H3, H4, H5, H6, H7, H8: MountingHole; MountingHole_3.2mm_M3
IC34, IC37: 27C128; DIP-28_W15.24mm_Socket_LongPads
IC35: 74LS00; DIP-14_W7.62mm_Socket_LongPads
IC36: 74LS02; DIP-14_W7.62mm_Socket_LongPads
IC38: MC6809E; DIP-40_W15.24mm_Socket_LongPads
IC39: 6883; DIP-40_W15.24mm_Socket_LongPads
IC40: 74LS138; DIP-16_W7.62mm_Socket_LongPads
J1: Screw_Terminal_01x03; TerminalBlock_RND_205-00277_1x03_P5.00mm_Vertical
LK1: PinHeader_1x03_P2.54mm_Vertical
PL6: Power/Video; PinHeader_1x09_P2.54mm_Vertical
PL9: Cartridge; Edge_2x20_P2.54mm_Horizontal
R17, R42: 100K; R_Axial_DIN0207_L6.3mm_D2.5mm_P7.62mm_Horizontal
R64: 1K; R_Axial_DIN0207_L6.3mm_D2.5mm_P7.62mm_Horizontal
R66, R67, R68, R69, R70, R71: 4K7; R_Axial_DIN0207_L6.3mm_D2.5mm_P7.62mm_Horizontal
R73, R74, R75, R76, R77, R78, R79, R80, R81, R82, R83: 22R; R_Axial_DIN0207_L6.3mm_D2.5mm_P7.62mm_Horizontal
R85: 470; R_Axial_DIN0207_L6.3mm_D2.5mm_P7.62mm_Horizontal
X1: 14.31818Mhz; DIP-14_W7.62mm_Socket_LongPads

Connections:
+5V: C56.1, C57.1, C59.2, C60.2, C61.2, C62.1, C63.1, C64.1, D7.1 (K), IC34.1 (VPP), IC34.27 (~PGM), IC34.28 (VCC), IC35.14 (VCC), IC36.14 (VCC), IC37.1 (VPP), IC37.27 (~PGM), IC37.28 (VCC), IC38.7 (VCC), IC39.40 (VCC), IC40.16 (VCC), J1.3, PL6.8, PL9.9, R17.1, R42.1, R64.1, R66.2, R67.2, R68.2, R69.2, R70.1, R71.1, R85.1, X1.14 (Vcc); also elsewhere on the board
+12V: J1.1, PL9.1, PL9.2; also elsewhere on the board
/A13: IC34.26 (A13), IC37.26 (A13), IC38.21 (A13), IC39.38 (A13), PL9.37
/A14: IC38.22 (A14), IC39.37 (A14), PL9.38
/A15: IC38.23 (A15), IC39.36 (A15), PL9.39
/ESND: PL9.35; also elsewhere on the board
/EXTMEM: IC40.6 (E3), PL9.40, R71.2
/P0: IC40.11 (O4); also elsewhere on the board
/P1: IC40.10 (O5); also elsewhere on the board
/RAM: IC40.15 (O0); also elsewhere on the board
/ROM0: IC34.20 (~CE), IC35.8
/ROM1: IC35.3, IC37.20 (~CE)
/ROMSEL: IC35.9, IC35.12, R64.2; also elsewhere on the board
/S0: IC39.27 (S0), IC40.1 (A0)
/S1: IC39.26 (S1), IC40.2 (A1)
/S2: IC36.5, IC36.12, IC39.25 (S2), IC40.3 (A2)
/Z0: R79.2; also elsewhere on the board
/Z1: R78.2; also elsewhere on the board
/Z2: R77.2; also elsewhere on the board
/Z3: R76.2; also elsewhere on the board
/Z4: R75.2; also elsewhere on the board
/Z5: R74.2; also elsewhere on the board
/Z6: R73.2; also elsewhere on the board
/Z7: R83.2; also elsewhere on the board
/~CAS: R81.2; also elsewhere on the board
/~FIRQ: IC38.4 (~FIRQ), R69.1; also elsewhere on the board
/~HALT: IC38.40 (~HALT), PL9.3, R66.1
/~IRQ: IC38.3 (~IRQ), R68.1; also elsewhere on the board
/~RAS0: R82.2; also elsewhere on the board
/~WE: R80.2; also elsewhere on the board
A0: IC34.10 (A0), IC37.10 (A0), IC38.8 (A0), IC39.16 (A0), PL9.19; also elsewhere on the board
A1: IC34.9 (A1), IC37.9 (A1), IC38.9 (A1), IC39.17 (A1), PL9.20; also elsewhere on the board
A2: IC34.8 (A2), IC37.8 (A2), IC38.10 (A2), IC39.18 (A2), PL9.21; also elsewhere on the board
A3: IC34.7 (A3), IC37.7 (A3), IC38.11 (A3), IC39.19 (A3), PL9.22; also elsewhere on the board
A4: IC34.6 (A4), IC37.6 (A4), IC38.12 (A4), IC39.21 (A4), PL9.23; also elsewhere on the board
A5: IC34.5 (A5), IC37.5 (A5), IC38.13 (A5), IC39.22 (A5), PL9.24; also elsewhere on the board
A6: IC34.4 (A6), IC37.4 (A6), IC38.14 (A6), IC39.23 (A6), PL9.25; also elsewhere on the board
A7: IC34.3 (A7), IC37.3 (A7), IC38.15 (A7), IC39.24 (A7), PL9.26; also elsewhere on the board
A8: IC34.25 (A8), IC37.25 (A8), IC38.16 (A8), IC39.4 (A8), PL9.27; also elsewhere on the board
A9: IC34.24 (A9), IC37.24 (A9), IC38.17 (A9), IC39.3 (A9), PL9.28; also elsewhere on the board
A10: IC34.21 (A10), IC37.21 (A10), IC38.18 (A10), IC39.2 (A10), PL9.29; also elsewhere on the board
A11: IC34.23 (A11), IC37.23 (A11), IC38.19 (A11), IC39.1 (A11), PL9.30; also elsewhere on the board
A12: IC34.2 (A12), IC37.2 (A12), IC38.20 (A12), IC39.39 (A12), PL9.31; also elsewhere on the board
CART: PL9.8; also elsewhere on the board
CHROMA: PL6.9; also elsewhere on the board
D0: IC34.11 (D0), IC37.11 (D0), IC38.31 (D0), PL9.10; also elsewhere on the board
D1: IC34.12 (D1), IC37.12 (D1), IC38.30 (D1), PL9.11; also elsewhere on the board
D2: IC34.13 (D2), IC37.13 (D2), IC38.29 (D2), PL9.12; also elsewhere on the board
D3: IC34.15 (D3), IC37.15 (D3), IC38.28 (D3), PL9.13; also elsewhere on the board
D4: IC34.16 (D4), IC37.16 (D4), IC38.27 (D4), PL9.14; also elsewhere on the board
D5: IC34.17 (D5), IC37.17 (D5), IC38.26 (D5), PL9.15; also elsewhere on the board
D6: IC34.18 (D6), IC37.18 (D6), IC38.25 (D6), PL9.16; also elsewhere on the board
D7: IC34.19 (D7), IC37.19 (D7), IC38.24 (D7), PL9.17; also elsewhere on the board
DA0: IC39.8 (DA0); also elsewhere on the board
E: C67.2, IC36.11, IC38.34 (E), IC39.14 (E), PL9.6; also elsewhere on the board
GND: C8.1, C48.1, C56.2, C57.2, C59.1, C60.1, C61.1, C62.2, C63.2, C64.2, C67.1, IC34.14 (GND), IC34.22 (~OE), IC35.7 (GND), IC36.7 (GND), IC37.14 (GND), IC37.22 (~OE), IC38.1 (VSS), IC38.39 (TSC), IC39.5 (OSCin), IC39.20 (VSS), IC40.8 (GND), J1.2, PL6.1, PL6.4, PL6.5, PL9.33, PL9.34, X1.7 (GND); also elsewhere on the board
HS: IC39.9 (~HS~); also elsewhere on the board
LUMA: PL6.6; also elsewhere on the board
unnamed: IC35.1, IC35.11
unnamed: IC35.4, IC40.14 (O1)
unnamed: IC35.5, IC40.13 (O2)
unnamed: IC35.2, IC35.6, IC35.10
unnamed: IC35.13, R70.2
unnamed: IC36.1, LK1.3 (B)
unnamed: IC36.2, IC36.3, IC39.35 (Z7), LK1.1 (A)
unnamed: IC36.4, IC40.5 (E2)
unnamed: IC36.13, IC40.4 (E1)
unnamed: IC39.6 (OSCout), X1.8 (OUT)
unnamed: IC39.10 (~WE~), R80.1
unnamed: IC39.11 (~CAS~), R81.1
unnamed: IC39.12 (~RAS0~), R82.1
unnamed: IC39.28 (Z0), R79.1
unnamed: IC39.29 (Z1), R78.1
unnamed: IC39.30 (Z2), R77.1
unnamed: IC39.31 (Z3), R76.1
unnamed: IC39.32 (Z4), R75.1
unnamed: IC39.33 (Z5), R74.1
unnamed: IC39.34 (Z6), R73.1
unnamed: LK1.2 (C), R83.1
unnamed: PL6.2, R85.2
P2: IC40.9 (O6), PL9.36; also elsewhere on the board
Q: IC38.35 (Q), IC39.13 (Q), PL9.7; also elsewhere on the board
RES_IN: C48.2, D6.1 (K), D7.2 (A), D11.1 (K), PL6.3, R42.2
ROM2: IC40.12 (O3), PL9.32; also elsewhere on the board
R~W~: IC36.6, IC38.32 (R/~W), IC39.15 (R/~W~), PL9.18; also elsewhere on the board
SOUND: PL6.7; also elsewhere on the board
VCLK: D6.2 (A), IC39.7 (VClk); also elsewhere on the board
~NMI: IC38.2 (~NMI), PL9.4, R67.1; also elsewhere on the board
~RESET: C8.2, D11.2 (A), IC38.37 (~RESET), PL9.5, R17.2; also elsewhere on the board

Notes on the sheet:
HARD WIRED
ELECTRO

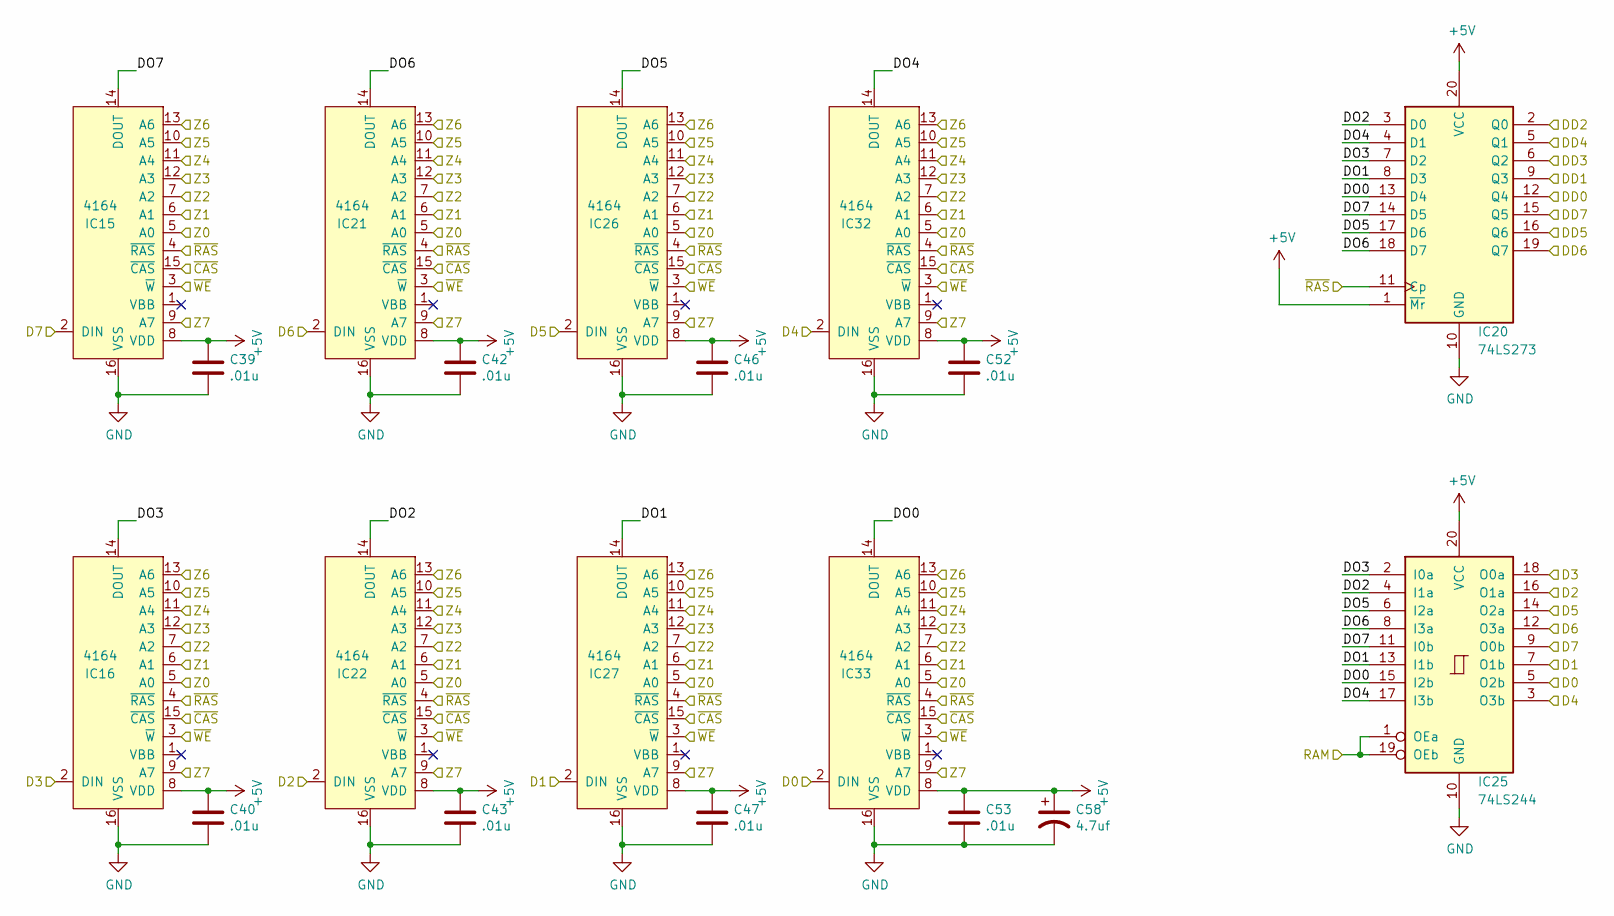
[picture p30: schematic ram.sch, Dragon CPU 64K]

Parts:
C39, C40, C42, C43, C46, C47, C52, C53: .01u; C_Disc_D7.5mm_W2.5mm_P5.00mm
C58: 4.7uf; CP_Radial_D4.0mm_P2.00mm
IC15, IC16, IC21, IC22, IC26, IC27, IC32, IC33: 4164; DIP-16_W7.62mm_Socket_LongPads
IC20: 74LS273; DIP-20_W7.62mm_Socket_LongPads
IC25: 74LS244; DIP-20_W7.62mm_Socket_LongPads

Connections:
+5V: C39.1, C40.1, C42.1, C43.1, C46.1, C47.1, C52.1, C53.1, C58.1, IC15.8 (VDD), IC16.8 (VDD), IC20.1 (~Mr), IC20.20 (VCC), IC21.8 (VDD), IC22.8 (VDD), IC25.20 (VCC), IC26.8 (VDD), IC27.8 (VDD), IC32.8 (VDD), IC33.8 (VDD); also elsewhere on the board
/RAM: IC25.1 (OEa), IC25.19 (OEb); also elsewhere on the board
/RAM/DD0: IC20.12 (Q4); also elsewhere on the board
/RAM/DD1: IC20.9 (Q3); also elsewhere on the board
/RAM/DD2: IC20.2 (Q0); also elsewhere on the board
/RAM/DD3: IC20.6 (Q2); also elsewhere on the board
/RAM/DD4: IC20.5 (Q1); also elsewhere on the board
/RAM/DD5: IC20.16 (Q6); also elsewhere on the board
/RAM/DD6: IC20.19 (Q7); also elsewhere on the board
/RAM/DD7: IC20.15 (Q5); also elsewhere on the board
/RAM/DO0: IC20.13 (D4), IC25.15 (I2b), IC33.14 (DOUT)
/RAM/DO1: IC20.8 (D3), IC25.13 (I1b), IC27.14 (DOUT)
/RAM/DO2: IC20.3 (D0), IC22.14 (DOUT), IC25.4 (I1a)
/RAM/DO3: IC16.14 (DOUT), IC20.7 (D2), IC25.2 (I0a)
/RAM/DO4: IC20.4 (D1), IC25.17 (I3b), IC32.14 (DOUT)
/RAM/DO5: IC20.17 (D6), IC25.6 (I2a), IC26.14 (DOUT)
/RAM/DO6: IC20.18 (D7), IC21.14 (DOUT), IC25.8 (I3a)
/RAM/DO7: IC15.14 (DOUT), IC20.14 (D5), IC25.11 (I0b)
/Z0: IC15.5 (A0), IC16.5 (A0), IC21.5 (A0), IC22.5 (A0), IC26.5 (A0), IC27.5 (A0), IC32.5 (A0), IC33.5 (A0); also elsewhere on the board
/Z1: IC15.6 (A1), IC16.6 (A1), IC21.6 (A1), IC22.6 (A1), IC26.6 (A1), IC27.6 (A1), IC32.6 (A1), IC33.6 (A1); also elsewhere on the board
/Z2: IC15.7 (A2), IC16.7 (A2), IC21.7 (A2), IC22.7 (A2), IC26.7 (A2), IC27.7 (A2), IC32.7 (A2), IC33.7 (A2); also elsewhere on the board
/Z3: IC15.12 (A3), IC16.12 (A3), IC21.12 (A3), IC22.12 (A3), IC26.12 (A3), IC27.12 (A3), IC32.12 (A3), IC33.12 (A3); also elsewhere on the board
/Z4: IC15.11 (A4), IC16.11 (A4), IC21.11 (A4), IC22.11 (A4), IC26.11 (A4), IC27.11 (A4), IC32.11 (A4), IC33.11 (A4); also elsewhere on the board
/Z5: IC15.10 (A5), IC16.10 (A5), IC21.10 (A5), IC22.10 (A5), IC26.10 (A5), IC27.10 (A5), IC32.10 (A5), IC33.10 (A5); also elsewhere on the board
/Z6: IC15.13 (A6), IC16.13 (A6), IC21.13 (A6), IC22.13 (A6), IC26.13 (A6), IC27.13 (A6), IC32.13 (A6), IC33.13 (A6); also elsewhere on the board
/Z7: IC15.9 (A7), IC16.9 (A7), IC21.9 (A7), IC22.9 (A7), IC26.9 (A7), IC27.9 (A7), IC32.9 (A7), IC33.9 (A7); also elsewhere on the board
/~CAS: IC15.15 (~CAS~), IC16.15 (~CAS~), IC21.15 (~CAS~), IC22.15 (~CAS~), IC26.15 (~CAS~), IC27.15 (~CAS~), IC32.15 (~CAS~), IC33.15 (~CAS~); also elsewhere on the board
/~RAS0: IC15.4 (~RAS~), IC16.4 (~RAS~), IC20.11 (Cp), IC21.4 (~RAS~), IC22.4 (~RAS~), IC26.4 (~RAS~), IC27.4 (~RAS~), IC32.4 (~RAS~), IC33.4 (~RAS~); also elsewhere on the board
/~WE: IC15.3 (~W~), IC16.3 (~W~), IC21.3 (~W~), IC22.3 (~W~), IC26.3 (~W~), IC27.3 (~W~), IC32.3 (~W~), IC33.3 (~W~); also elsewhere on the board
D0: IC25.5 (O2b), IC33.2 (DIN); also elsewhere on the board
D1: IC25.7 (O1b), IC27.2 (DIN); also elsewhere on the board
D2: IC22.2 (DIN), IC25.16 (O1a); also elsewhere on the board
D3: IC16.2 (DIN), IC25.18 (O0a); also elsewhere on the board
D4: IC25.3 (O3b), IC32.2 (DIN); also elsewhere on the board
D5: IC25.14 (O2a), IC26.2 (DIN); also elsewhere on the board
D6: IC21.2 (DIN), IC25.12 (O3a); also elsewhere on the board
D7: IC15.2 (DIN), IC25.9 (O0b); also elsewhere on the board
GND: C39.2, C40.2, C42.2, C43.2, C46.2, C47.2, C52.2, C53.2, C58.2, IC15.16 (VSS), IC16.16 (VSS), IC20.10 (GND), IC21.16 (VSS), IC22.16 (VSS), IC25.10 (GND), IC26.16 (VSS), IC27.16 (VSS), IC32.16 (VSS), IC33.16 (VSS); also elsewhere on the board

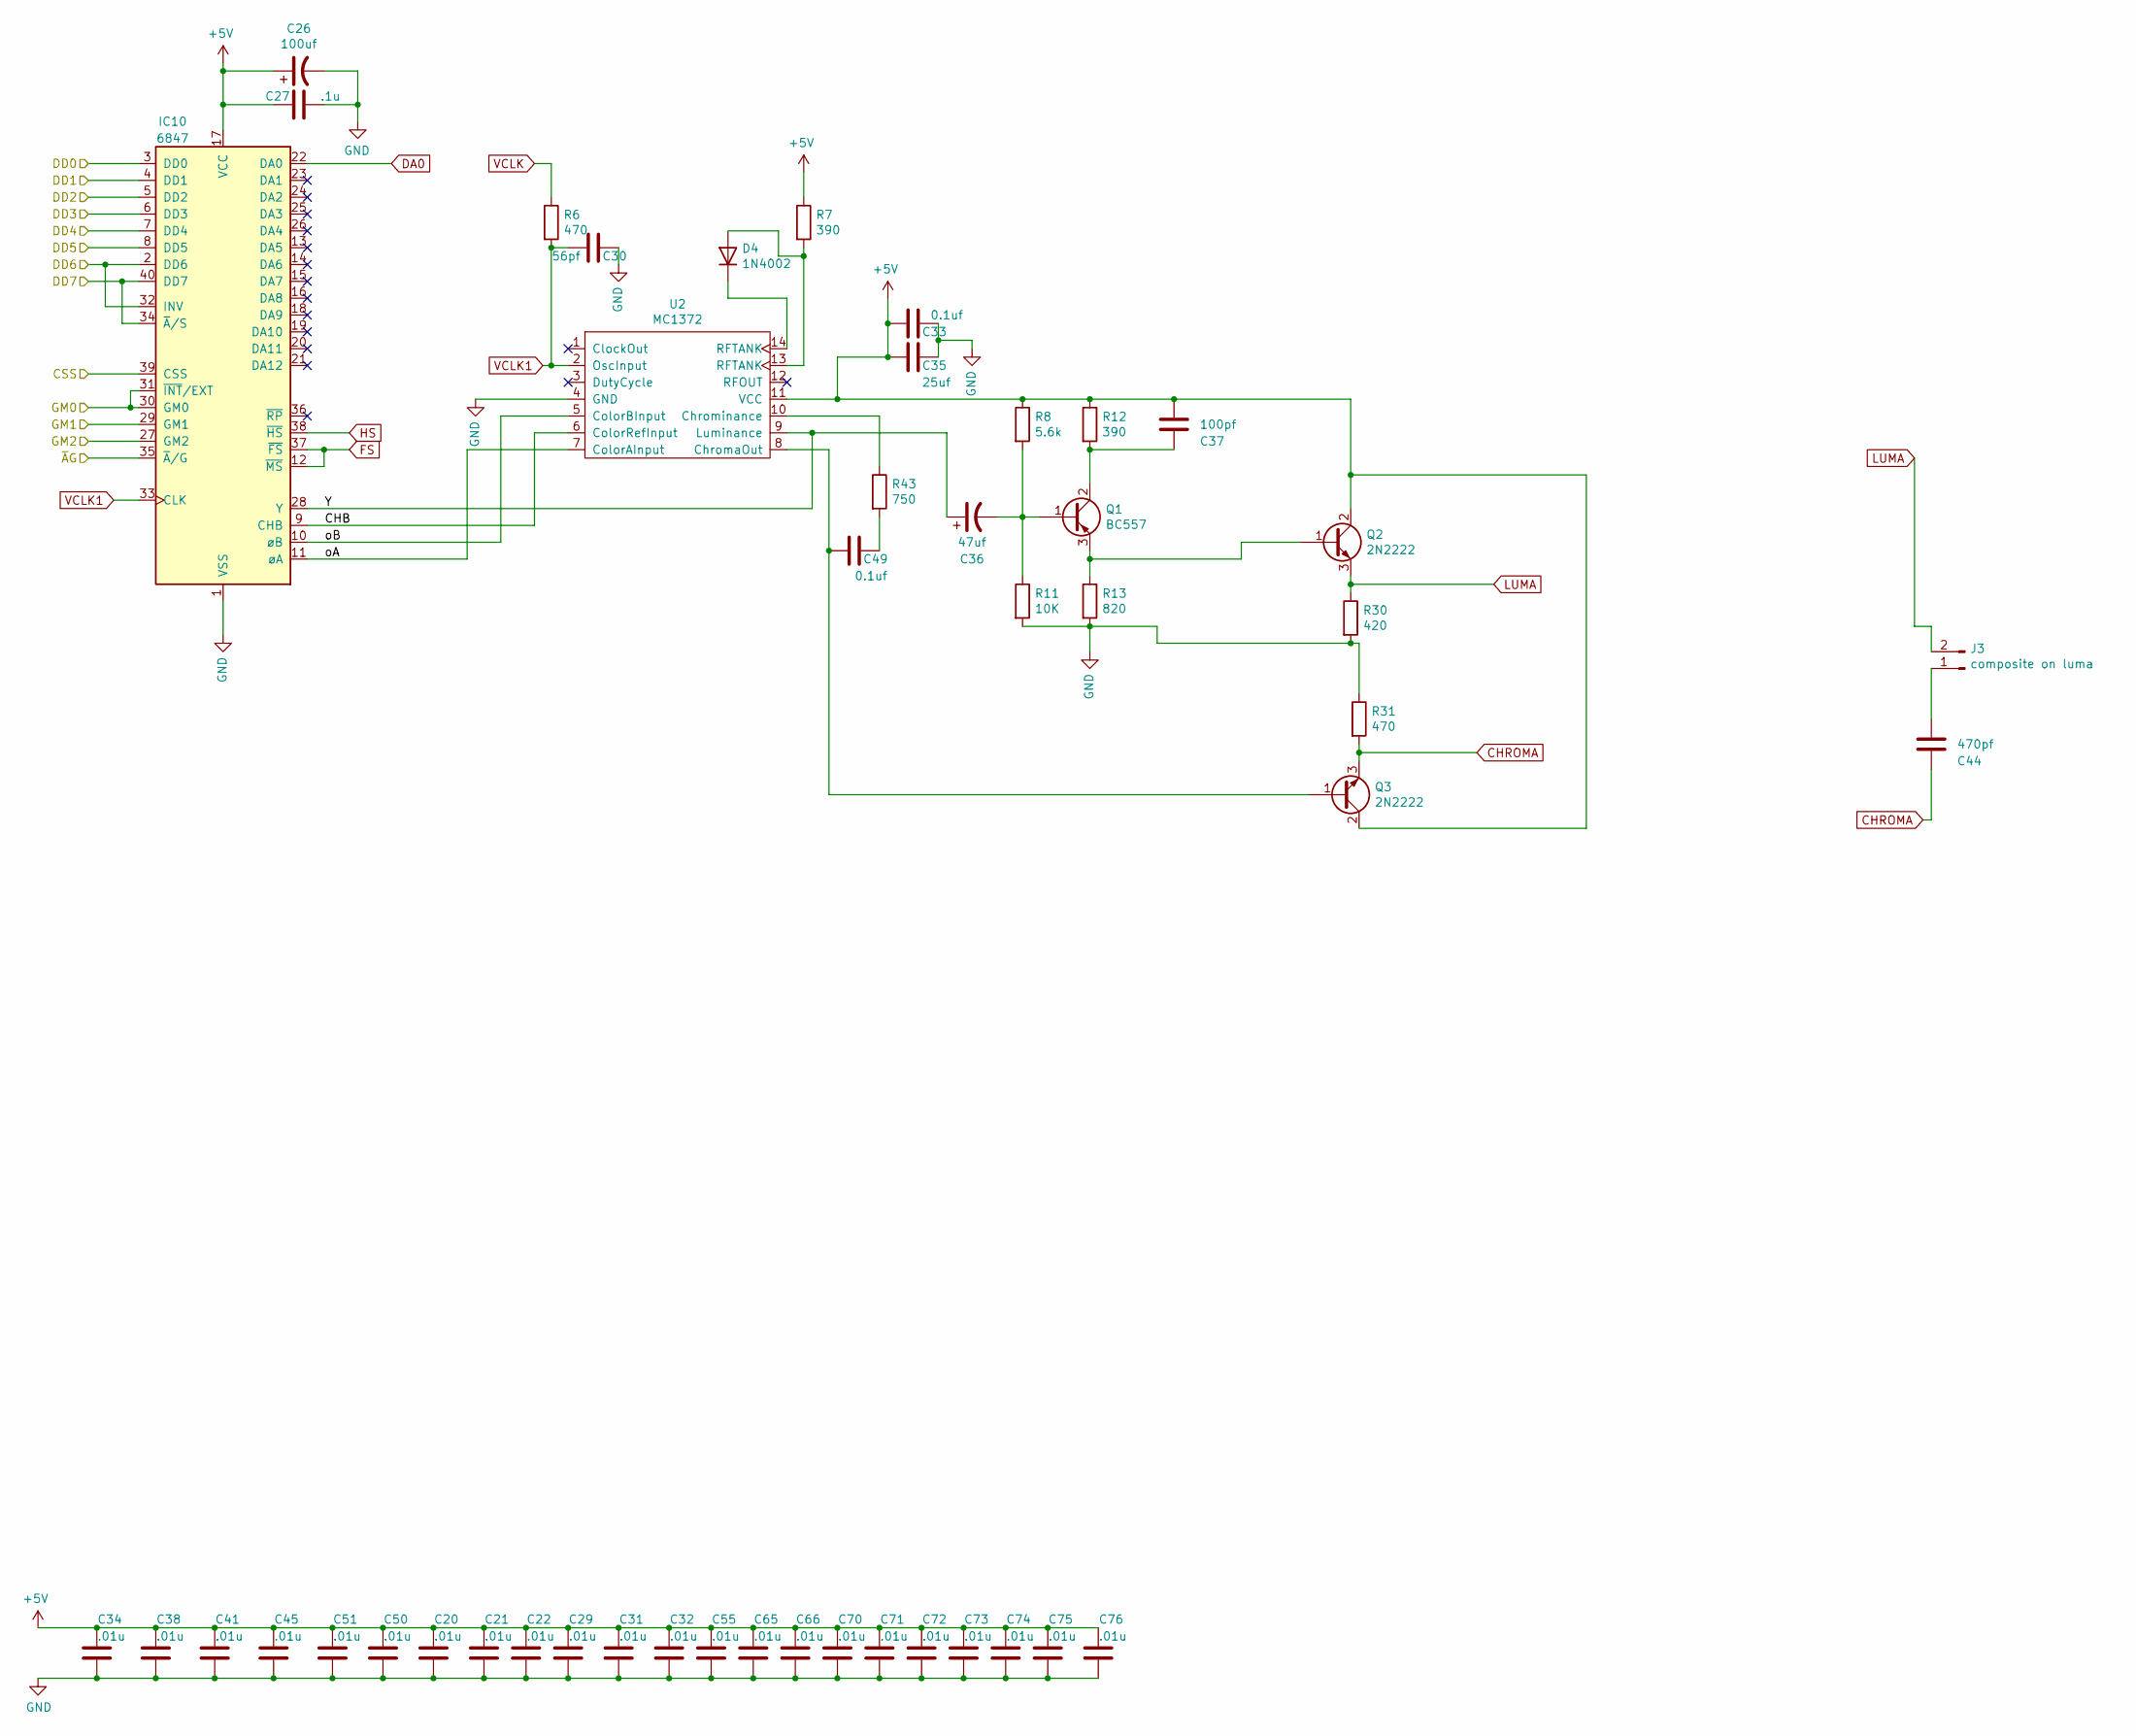
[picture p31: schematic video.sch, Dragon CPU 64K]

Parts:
C20, C21, C22, C29, C31, C32, C34, C38, C41, C45, C50, C51, C55, C65, C66, C70, C71, C72, C73, C74, C75, C76: .01u; C_Disc_D7.5mm_W2.5mm_P5.00mm
C26: 100uf; CP_Radial_D4.0mm_P2.00mm
C27: .1u; C_Disc_D7.5mm_W2.5mm_P5.00mm
C30: 56pf; C_Disc_D7.5mm_W2.5mm_P5.00mm
C33, C49: 0.1uf; C_Disc_D7.5mm_W2.5mm_P5.00mm
C35: 25uf; C_Disc_D7.5mm_W2.5mm_P5.00mm
C36: 47uf; CP_Radial_D4.0mm_P2.00mm
C37: 100pf; C_Disc_D7.5mm_W2.5mm_P5.00mm
C44: 470pf; C_Disc_D7.5mm_W2.5mm_P5.00mm
D4: 1N4002; D_DO-35_SOD27_P7.62mm_Horizontal
IC10: 6847; DIP-40_W15.24mm_Socket_LongPads
J3: composite on luma; PinHeader_1x02_P2.54mm_Vertical
Q1: BC557; TO-92_HandSolder_FIXED
Q2, Q3: 2N2222; TO-18-3_FIXED
R6, R31: 470; R_Axial_DIN0207_L6.3mm_D2.5mm_P7.62mm_Horizontal
R7, R12: 390; R_Axial_DIN0207_L6.3mm_D2.5mm_P7.62mm_Horizontal
R8: 5.6k; R_Axial_DIN0207_L6.3mm_D2.5mm_P7.62mm_Horizontal
R11: 10K; R_Axial_DIN0207_L6.3mm_D2.5mm_P7.62mm_Horizontal
R13: 820; R_Axial_DIN0207_L6.3mm_D2.5mm_P7.62mm_Horizontal
R30: 420; R_Axial_DIN0207_L6.3mm_D2.5mm_P7.62mm_Horizontal
R43: 750; R_Axial_DIN0207_L6.3mm_D2.5mm_P7.62mm_Horizontal
U2: MC1372; DIP-14_W7.62mm_Socket_LongPads

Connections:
+5V: C20.1, C21.1, C22.1, C26.1, C27.2, C29.1, C31.1, C32.1, C33.1, C34.1, C35.1, C37.1, C38.1, C41.1, C45.1, C50.1, C51.1, C55.1, C65.1, C66.1, C70.1, C71.1, C72.1, C73.1, C74.1, C75.1, C76.1, IC10.17 (VCC), Q2.2 (C), Q3.2 (C), R7.1, R8.1, R12.1, U2.11 (VCC); also elsewhere on the board
/PIAs/CSS: IC10.39 (CSS); also elsewhere on the board
/PIAs/GM0: IC10.30 (GM0), IC10.31 (~INT~/EXT); also elsewhere on the board
/PIAs/GM1: IC10.29 (GM1); also elsewhere on the board
/PIAs/GM2: IC10.27 (GM2); also elsewhere on the board
/PIAs/~A~G: IC10.35 (~A~/G); also elsewhere on the board
/RAM/DD0: IC10.3 (DD0); also elsewhere on the board
/RAM/DD1: IC10.4 (DD1); also elsewhere on the board
/RAM/DD2: IC10.5 (DD2); also elsewhere on the board
/RAM/DD3: IC10.6 (DD3); also elsewhere on the board
/RAM/DD4: IC10.7 (DD4); also elsewhere on the board
/RAM/DD5: IC10.8 (DD5); also elsewhere on the board
/RAM/DD6: IC10.2 (DD6), IC10.32 (INV); also elsewhere on the board
/RAM/DD7: IC10.34 (~A~/S), IC10.40 (DD7); also elsewhere on the board
/Video/CHB: IC10.9 (CHB), U2.6 (ColorRefInput)
/Video/Y: C36.1, IC10.28 (Y), U2.9 (Luminance)
/Video/oA: IC10.11 (øA), U2.7 (ColorAInput)
/Video/oB: IC10.10 (øB), U2.5 (ColorBInput)
CHROMA: C44.2, Q3.3 (E), R31.2; also elsewhere on the board
DA0: IC10.22 (DA0); also elsewhere on the board
FS: IC10.12 (~MS~), IC10.37 (~FS~); also elsewhere on the board
GND: C20.2, C21.2, C22.2, C26.2, C27.1, C29.2, C30.2, C31.2, C32.2, C33.2, C34.2, C35.2, C38.2, C41.2, C45.2, C50.2, C51.2, C55.2, C65.2, C66.2, C70.2, C71.2, C72.2, C73.2, C74.2, C75.2, C76.2, IC10.1 (VSS), R11.2, R13.2, R30.2, R31.1, U2.4 (GND); also elsewhere on the board
HS: IC10.38 (~HS~); also elsewhere on the board
LUMA: J3.2, Q2.3 (E), R30.1; also elsewhere on the board
unnamed: C36.2, Q1.1 (B), R8.2, R11.1
unnamed: C37.2, Q1.2 (C), R12.2
unnamed: C44.1, J3.1
unnamed: C49.1, Q3.1 (B), U2.8 (ChromaOut)
unnamed: C49.2, R43.2
unnamed: D4.1 (K), U2.14 (RFTANK)
unnamed: D4.2 (A), R7.2, U2.13 (RFTANK)
unnamed: Q1.3 (E), Q2.1 (B), R13.1
unnamed: R43.1, U2.10 (Chrominance)
VCLK: R6.1; also elsewhere on the board
VCLK1: C30.1, IC10.33 (CLK), R6.2, U2.2 (OscInput)

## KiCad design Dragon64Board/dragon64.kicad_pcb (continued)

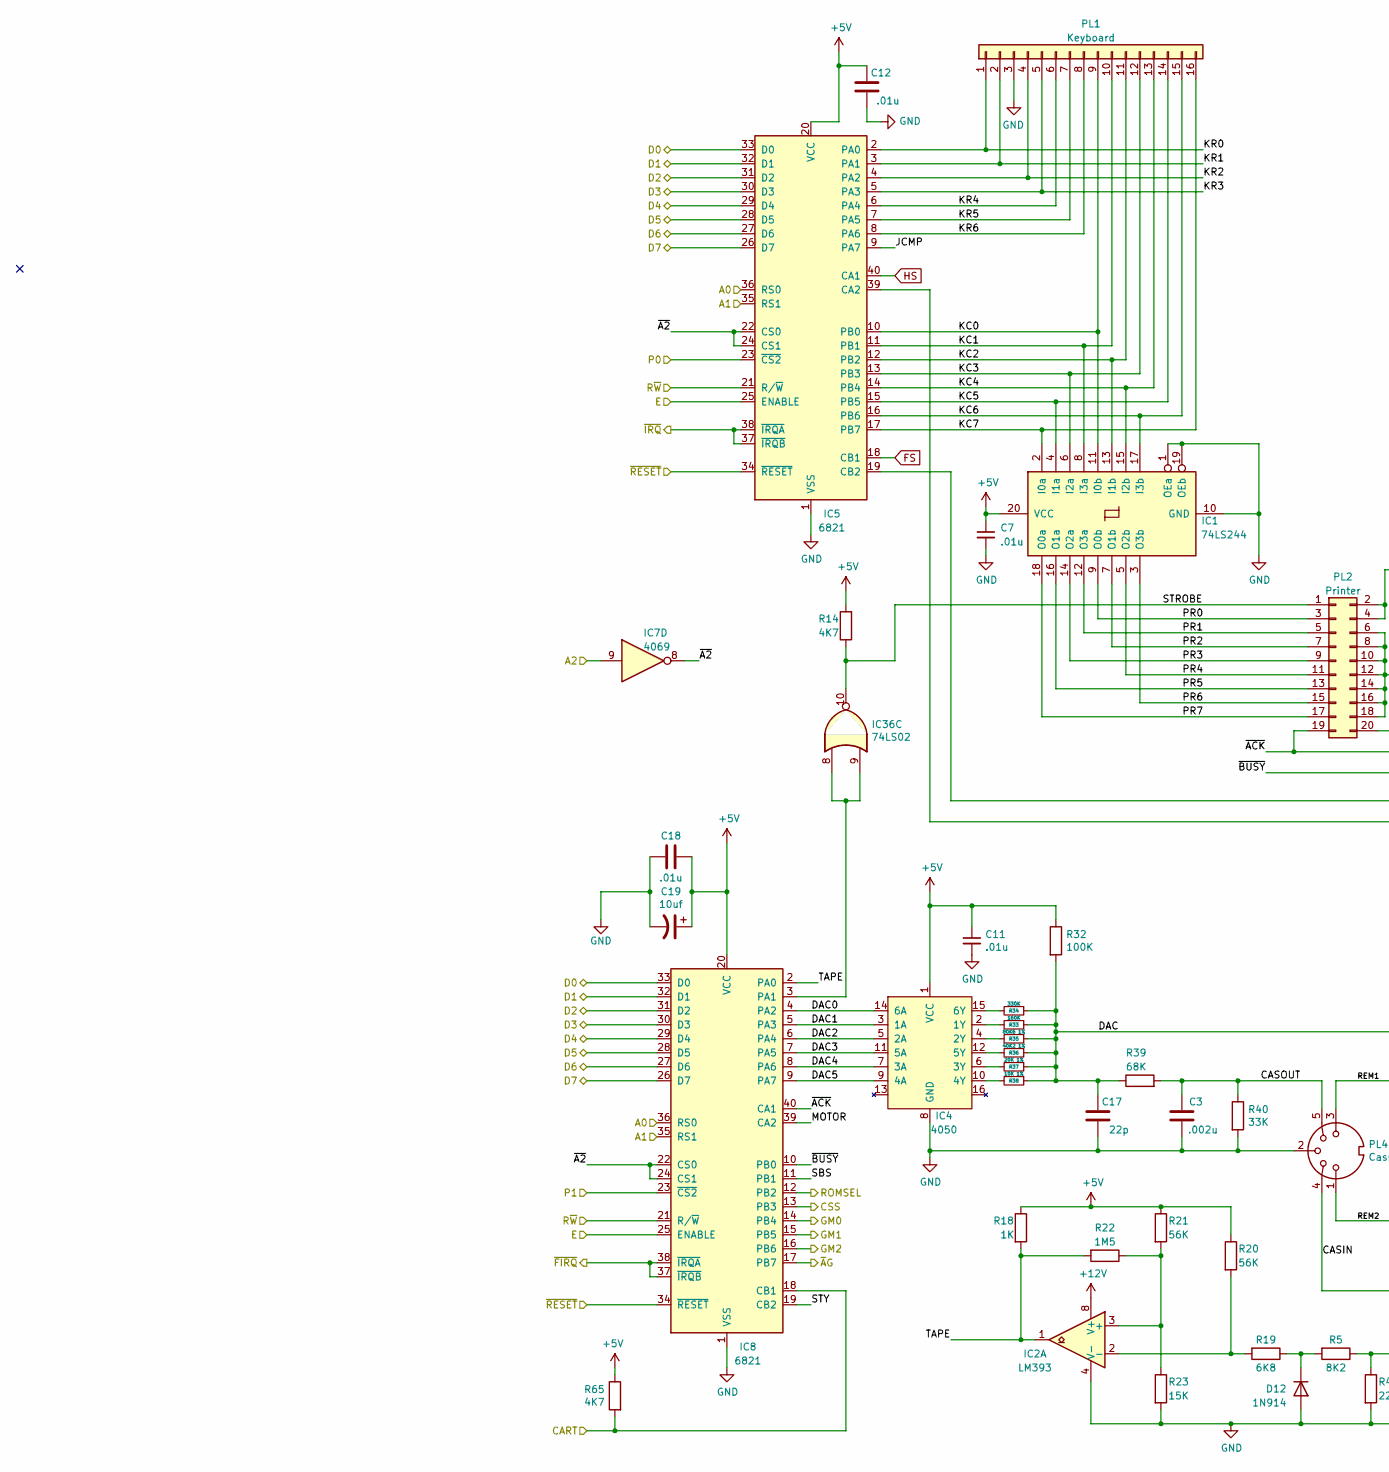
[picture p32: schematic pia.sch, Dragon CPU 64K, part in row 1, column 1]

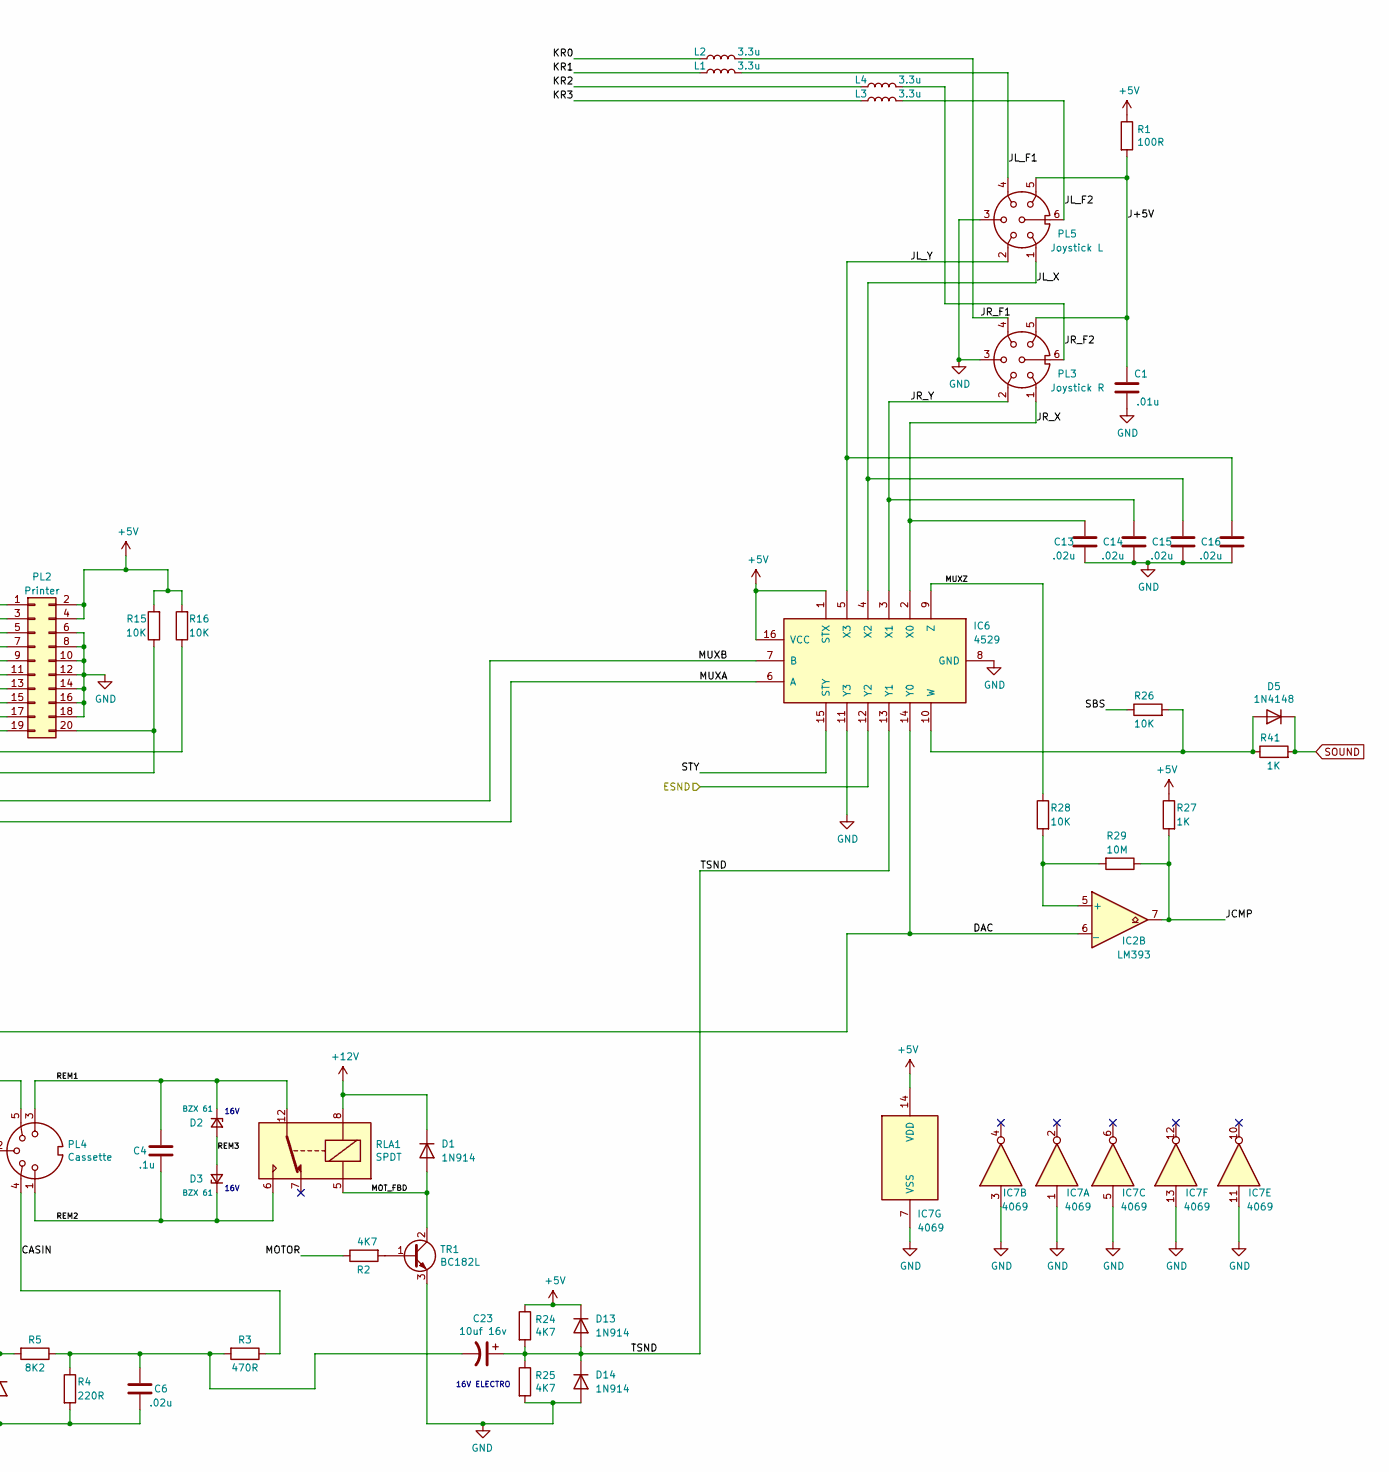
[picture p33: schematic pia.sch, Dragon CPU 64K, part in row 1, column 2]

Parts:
C1, C7, C11, C12, C18: .01u; C_Disc_D7.5mm_W2.5mm_P5.00mm
C3: .002u; C_Disc_D7.5mm_W2.5mm_P5.00mm
C4: .1u; C_Disc_D7.5mm_W2.5mm_P5.00mm
C6, C13, C14, C15, C16: .02u; C_Disc_D7.5mm_W2.5mm_P5.00mm
C17: 22p; C_Disc_D7.5mm_W2.5mm_P5.00mm
C19: 10uf; CP_Radial_D4.0mm_P2.00mm
C23: 10uf 16v; CP_Radial_D4.0mm_P2.00mm
D1, D12, D13, D14: 1N914; D_DO-35_SOD27_P7.62mm_Horizontal
D2, D3: BZX 61; D_DO-35_SOD27_P7.62mm_Horizontal
D5: 1N4148; D_DO-35_SOD27_P7.62mm_Horizontal
IC1: 74LS244; DIP-20_W7.62mm_Socket_LongPads
IC2: LM393; DIP-8_W7.62mm_Socket_LongPads
IC4: 4050; DIP-16_W7.62mm_Socket_LongPads
IC5, IC8: 6821; DIP-40_W15.24mm_Socket_LongPads
IC6: 4529; DIP-16_W7.62mm_Socket_LongPads
IC7: 4069; DIP-14_W7.62mm_Socket_LongPads
IC36: 74LS02; DIP-14_W7.62mm_Socket_LongPads
L1, L2, L3, L4: 3.3u; L_Axial_L5.3mm_D2.2mm_P7.62mm_Horizontal_Vishay_IM-1
PL1: Keyboard; PinHeader_1x16_P2.54mm_Vertical
PL2: Printer; IDC-Header_2x10-1MP_P2.54mm_Latch_Horizontal
PL3: Joystick R; DIN-6_DELTRON_671-0601_Horizontal
PL4: Cassette; DIN-5_DELTRON_671-0501_45deg_Horizontal
PL5: Joystick L; DIN-6_DELTRON_671-0601_Horizontal
R1: 100R; R_Axial_DIN0207_L6.3mm_D2.5mm_P7.62mm_Horizontal
R2, R14, R24, R25, R65: 4K7; R_Axial_DIN0207_L6.3mm_D2.5mm_P7.62mm_Horizontal
R3: 470R; R_Axial_DIN0207_L6.3mm_D2.5mm_P7.62mm_Horizontal
R4: 220R; R_Axial_DIN0207_L6.3mm_D2.5mm_P7.62mm_Horizontal
R5: 8K2; R_Axial_DIN0207_L6.3mm_D2.5mm_P7.62mm_Horizontal
R15, R16, R26, R28: 10K; R_Axial_DIN0207_L6.3mm_D2.5mm_P7.62mm_Horizontal
R18, R27, R41: 1K; R_Axial_DIN0207_L6.3mm_D2.5mm_P7.62mm_Horizontal
R19: 6K8; R_Axial_DIN0207_L6.3mm_D2.5mm_P7.62mm_Horizontal
R20, R21: 56K; R_Axial_DIN0207_L6.3mm_D2.5mm_P7.62mm_Horizontal
R22: 1M5; R_Axial_DIN0207_L6.3mm_D2.5mm_P7.62mm_Horizontal
R23: 15K; R_Axial_DIN0207_L6.3mm_D2.5mm_P7.62mm_Horizontal
R29: 10M; R_Axial_DIN0207_L6.3mm_D2.5mm_P7.62mm_Horizontal
R32: 100K; R_Axial_DIN0207_L6.3mm_D2.5mm_P7.62mm_Horizontal
R33: 160K; R_Axial_DIN0207_L6.3mm_D2.5mm_P7.62mm_Horizontal
R34: 330K; R_Axial_DIN0207_L6.3mm_D2.5mm_P7.62mm_Horizontal
R35: 80K6 1%; R_Axial_DIN0207_L6.3mm_D2.5mm_P7.62mm_Horizontal
R36: 40K2 1%; R_Axial_DIN0207_L6.3mm_D2.5mm_P7.62mm_Horizontal
R37: 20K 1%; R_Axial_DIN0207_L6.3mm_D2.5mm_P7.62mm_Horizontal
R38: 10K 1%; R_Axial_DIN0207_L6.3mm_D2.5mm_P7.62mm_Horizontal
R39: 68K; R_Axial_DIN0207_L6.3mm_D2.5mm_P7.62mm_Horizontal
R40: 33K; R_Axial_DIN0207_L6.3mm_D2.5mm_P7.62mm_Horizontal
RLA1: SPDT; Relay_SPDT_HJR-4102
TR1: BC182L; TO-92

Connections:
+5V: C7.1, C11.1, C12.2, C18.2, C19.1, D13.1 (K), IC1.20 (VCC), IC4.1 (VCC), IC5.20 (VCC), IC6.1 (STX), IC6.16 (VCC), IC7.14 (VDD), IC8.20 (VCC), PL2.2, PL2.4, R1.1, R14.2, R15.2, R16.2, R18.1, R20.1, R21.1, R24.1, R27.1, R32.1, R65.1; also elsewhere on the board
+12V: D1.1 (K), IC2.8 (V+), RLA1.8; also elsewhere on the board
/ESND: IC6.12 (Y2); also elsewhere on the board
/P0: IC5.23 (~CS2); also elsewhere on the board
/P1: IC8.23 (~CS2); also elsewhere on the board
/PIAs/CASIN: PL4.4, R3.1
/PIAs/CASOUT: C3.2, PL4.5, R39.2, R40.1
/PIAs/CSS: IC8.13 (PB3); also elsewhere on the board
/PIAs/DAC: C17.2, IC2.6 (_), IC6.14 (Y0), R32.2, R33.1, R34.1, R35.1, R36.1, R37.1, R38.1, R39.1
/PIAs/DAC0: IC4.14 (6A), IC8.4 (PA2)
/PIAs/DAC1: IC4.3 (1A), IC8.5 (PA3)
/PIAs/DAC2: IC4.5 (2A), IC8.6 (PA4)
/PIAs/DAC3: IC4.11 (5A), IC8.7 (PA5)
/PIAs/DAC4: IC4.7 (3A), IC8.8 (PA6)
/PIAs/DAC5: IC4.9 (4A), IC8.9 (PA7)
/PIAs/GM0: IC8.14 (PB4); also elsewhere on the board
/PIAs/GM1: IC8.15 (PB5); also elsewhere on the board
/PIAs/GM2: IC8.16 (PB6); also elsewhere on the board
/PIAs/J+5V: C1.2, PL3.5, PL5.5, R1.2
/PIAs/JCMP: IC2.7, IC5.9 (PA7), R27.2, R29.1
/PIAs/JL_F1: L1.2, PL5.4
/PIAs/JL_F2: L3.2, PL5.6
/PIAs/JL_X: C15.2, IC6.4 (X2), PL5.1
/PIAs/JL_Y: C16.2, IC6.5 (X3), PL5.2
/PIAs/JR_F1: L2.2, PL3.4
/PIAs/JR_F2: L4.2, PL3.6
/PIAs/JR_X: C13.2, IC6.2 (X0), PL3.1
/PIAs/JR_Y: C14.2, IC6.3 (X1), PL3.2
/PIAs/KC0: IC1.11 (I0b), IC5.10 (PB0), PL1.9
/PIAs/KC1: IC1.8 (I3a), IC5.11 (PB1), PL1.10
/PIAs/KC2: IC1.13 (I1b), IC5.12 (PB2), PL1.11
/PIAs/KC3: IC1.6 (I2a), IC5.13 (PB3), PL1.12
/PIAs/KC4: IC1.15 (I2b), IC5.14 (PB4), PL1.13
/PIAs/KC5: IC1.4 (I1a), IC5.15 (PB5), PL1.14
/PIAs/KC6: IC1.17 (I3b), IC5.16 (PB6), PL1.15
/PIAs/KC7: IC1.2 (I0a), IC5.17 (PB7), PL1.16
/PIAs/KR0: IC5.2 (PA0), L2.1, PL1.1
/PIAs/KR1: IC5.3 (PA1), L1.1, PL1.2
/PIAs/KR2: IC5.4 (PA2), L4.1, PL1.4
/PIAs/KR3: IC5.5 (PA3), L3.1, PL1.5
/PIAs/KR4: IC5.6 (PA4), PL1.6
/PIAs/KR5: IC5.7 (PA5), PL1.7
/PIAs/KR6: IC5.8 (PA6), PL1.8
/PIAs/MOTOR: IC8.39 (CA2), R2.1
/PIAs/MOT_FBD: D1.2 (A), RLA1.5, TR1.2 (C)
/PIAs/MUXA: IC5.39 (CA2), IC6.6 (A)
/PIAs/MUXB: IC5.19 (CB2), IC6.7 (B)
/PIAs/MUXZ: IC6.9 (Z), R28.1
/PIAs/PR0: IC1.9 (O0b), PL2.3
/PIAs/PR1: IC1.12 (O3a), PL2.5
/PIAs/PR2: IC1.7 (O1b), PL2.7
/PIAs/PR3: IC1.14 (O2a), PL2.9
/PIAs/PR4: IC1.5 (O2b), PL2.11
/PIAs/PR5: IC1.16 (O1a), PL2.13
/PIAs/PR6: IC1.3 (O3b), PL2.15
/PIAs/PR7: IC1.18 (O0a), PL2.17
/PIAs/REM1: C4.2, D2.1 (K), PL4.3, RLA1.12
/PIAs/REM2: C4.1, D3.1 (K), PL4.1, RLA1.6
/PIAs/REM3: D2.2 (A), D3.2 (A)
/PIAs/SBS: IC8.11 (PB1), R26.1
/PIAs/STROBE: IC36.10, PL2.1, R14.1
/PIAs/STY: IC6.15 (STY), IC8.19 (CB2)
/PIAs/TAPE: IC2.1, IC8.2 (PA0), R18.2, R22.2
/PIAs/TSND: C23.1, D13.2 (A), D14.1 (K), IC6.13 (Y1), R24.2, R25.1
/PIAs/~A2: IC5.22 (CS0), IC5.24 (CS1), IC7.8, IC8.22 (CS0), IC8.24 (CS1)
/PIAs/~ACK: IC8.40 (CA1), PL2.19, R16.1
/PIAs/~A~G: IC8.17 (PB7); also elsewhere on the board
/PIAs/~BUSY: IC8.10 (PB0), PL2.20, R15.1
/ROMSEL: IC8.12 (PB2); also elsewhere on the board
/~FIRQ: IC8.37 (~IRQB), IC8.38 (~IRQA); also elsewhere on the board
/~IRQ: IC5.37 (~IRQB), IC5.38 (~IRQA); also elsewhere on the board
A0: IC5.36 (RS0), IC8.36 (RS0); also elsewhere on the board
A1: IC5.35 (RS1), IC8.35 (RS1); also elsewhere on the board
A2: IC7.9; also elsewhere on the board
CART: IC8.18 (CB1), R65.2; also elsewhere on the board
D0: IC5.33 (D0), IC8.33 (D0); also elsewhere on the board
D1: IC5.32 (D1), IC8.32 (D1); also elsewhere on the board
D2: IC5.31 (D2), IC8.31 (D2); also elsewhere on the board
D3: IC5.30 (D3), IC8.30 (D3); also elsewhere on the board
D4: IC5.29 (D4), IC8.29 (D4); also elsewhere on the board
D5: IC5.28 (D5), IC8.28 (D5); also elsewhere on the board
D6: IC5.27 (D6), IC8.27 (D6); also elsewhere on the board
D7: IC5.26 (D7), IC8.26 (D7); also elsewhere on the board
E: IC5.25 (ENABLE), IC8.25 (ENABLE); also elsewhere on the board
FS: IC5.18 (CB1); also elsewhere on the board
GND: C1.1, C3.1, C6.1, C7.2, C11.2, C12.1, C13.1, C14.1, C15.1, C16.1, C17.1, C18.1, C19.2, D12.2 (A), D14.2 (A), IC1.1 (OEa), IC1.10 (GND), IC1.19 (OEb), IC2.4 (V-), IC4.8 (GND), IC5.1 (VSS), IC6.8 (GND), IC6.11 (Y3), IC7.1, IC7.3, IC7.5, IC7.7 (VSS), IC7.11, IC7.13, IC8.1 (VSS), PL1.3, PL2.6, PL2.8, PL2.10, PL2.12, PL2.14, PL2.16, PL2.18, PL3.3, PL4.2, PL5.3, R4.2, R23.2, R25.2, R40.2, TR1.3 (E); also elsewhere on the board
HS: IC5.40 (CA1); also elsewhere on the board
unnamed: C6.2, C23.2, R3.2, R4.1, R5.1
unnamed: D5.2 (A), IC6.10 (W), R26.2, R41.1
unnamed: D12.1 (K), R5.2, R19.1
unnamed: IC2.2 (-), R19.2, R20.2
unnamed: IC2.3 (+), R21.2, R22.1, R23.1
unnamed: IC2.5 (+), R28.2, R29.2
unnamed: IC4.2 (1Y), R33.2
unnamed: IC4.4 (2Y), R35.2
unnamed: IC4.6 (3Y), R37.2
unnamed: IC4.10 (4Y), R38.2
unnamed: IC4.12 (5Y), R36.2
unnamed: IC4.15 (6Y), R34.2
unnamed: IC8.3 (PA1), IC36.8, IC36.9
unnamed: R2.2, TR1.1 (B)
R~W~: IC5.21 (R/~W), IC8.21 (R/~W); also elsewhere on the board
SOUND: D5.1 (K), R41.2; also elsewhere on the board
~RESET: IC5.34 (~RESET), IC8.34 (~RESET); also elsewhere on the board

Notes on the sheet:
16V
16V ELECTRO

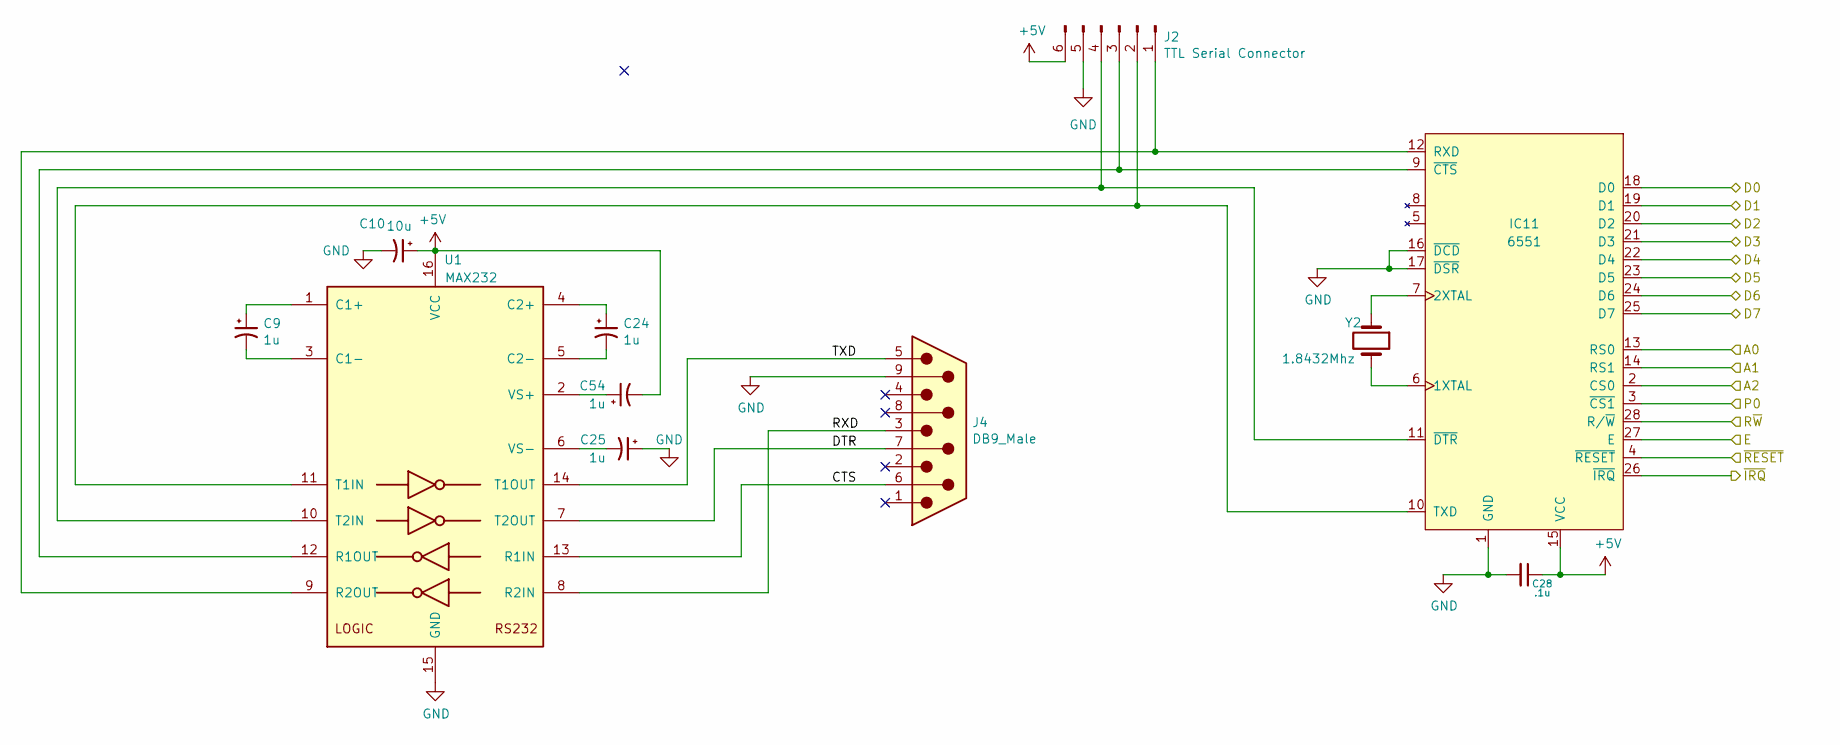
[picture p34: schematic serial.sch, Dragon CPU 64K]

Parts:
C9, C24, C25, C54: 1u; CP_Radial_D4.0mm_P2.00mm
C10: 10u; CP_Radial_D4.0mm_P2.00mm
C28: .1u; C_Disc_D7.5mm_W2.5mm_P5.00mm
IC11: 6551; DIP-28_W15.24mm_Socket_LongPads
J2: TTL Serial Connector; PinHeader_1x06_P2.54mm_Vertical
J4: DB9_Male; DSUB-9_Male_Horizontal_P2.77x2.84mm_EdgePinOffset4.94mm_Hou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
U1: MAX232; DIP-16_W7.62mm_Socket_LongPads
Y2: 1.8432Mhz; Crystal_HC49-U_Vertical

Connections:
+5V: C10.1, C28.1, C54.2, IC11.15 (VCC), J2.6, U1.16 (VCC); also elsewhere on the board
/P0: IC11.3 (~CS1~); also elsewhere on the board
/Serial/CTS: J4.6, U1.13 (R1IN)
/Serial/DTR: J4.7, U1.7 (T2OUT)
/Serial/RXD: J4.3, U1.8 (R2IN)
/Serial/TXD: J4.5, U1.14 (T1OUT)
/~IRQ: IC11.26 (~IRQ~); also elsewhere on the board
A0: IC11.13 (RS0); also elsewhere on the board
A1: IC11.14 (RS1); also elsewhere on the board
A2: IC11.2 (CS0); also elsewhere on the board
D0: IC11.18 (D0); also elsewhere on the board
D1: IC11.19 (D1); also elsewhere on the board
D2: IC11.20 (D2); also elsewhere on the board
D3: IC11.21 (D3); also elsewhere on the board
D4: IC11.22 (D4); also elsewhere on the board
D5: IC11.23 (D5); also elsewhere on the board
D6: IC11.24 (D6); also elsewhere on the board
D7: IC11.25 (D7); also elsewhere on the board
E: IC11.27 (E); also elsewhere on the board
GND: C10.2, C25.1, C28.2, IC11.1 (GND), IC11.16 (~DCD~), IC11.17 (~DSR~), J2.5, J4.9, U1.15 (GND); also elsewhere on the board
unnamed: C9.1, U1.1 (C1+)
unnamed: C9.2, U1.3 (C1-)
unnamed: C24.1, U1.4 (C2+)
unnamed: C24.2, U1.5 (C2-)
unnamed: C25.2, U1.6 (VS-)
unnamed: C54.1, U1.2 (VS+)
unnamed: IC11.6 (1XTAL), Y2.2
unnamed: IC11.7 (2XTAL), Y2.1
unnamed: IC11.9 (~CTS~), J2.3, U1.12 (R1OUT)
unnamed: IC11.10 (TXD), J2.2, U1.11 (T1IN)
unnamed: IC11.11 (~DTR~), J2.4, U1.10 (T2IN)
unnamed: IC11.12 (RXD), J2.1, U1.9 (R2OUT)
R~W~: IC11.28 (R/~W~); also elsewhere on the board
~RESET: IC11.4 (~RESET~); also elsewhere on the board

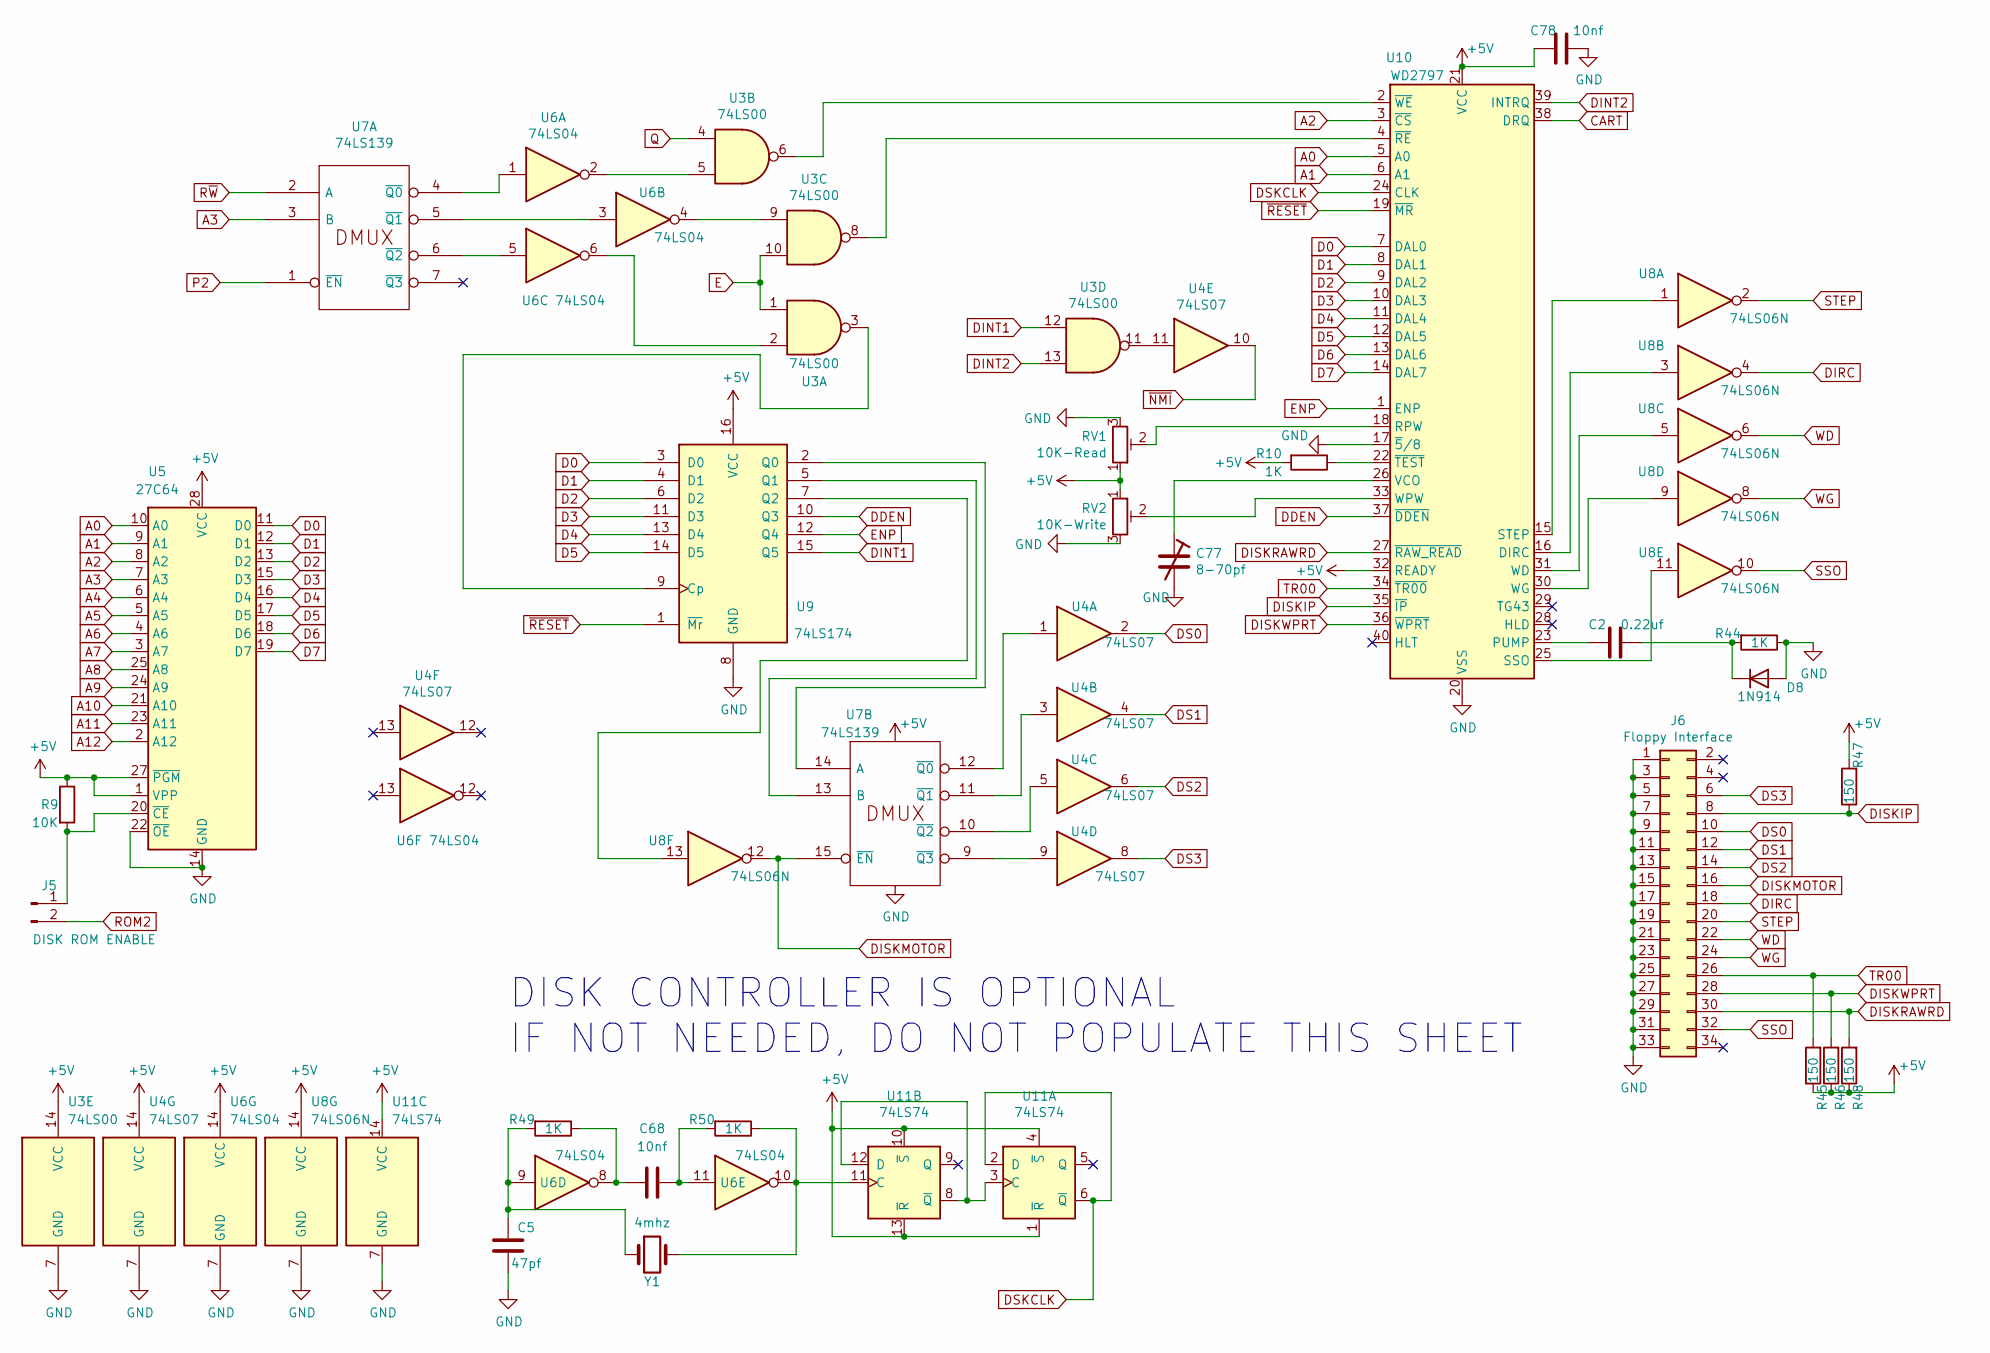
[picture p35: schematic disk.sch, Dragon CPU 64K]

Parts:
C2: 0.22uf; C_Disc_D7.5mm_W2.5mm_P5.00mm
C5: 47pf; C_Disc_D7.5mm_W2.5mm_P5.00mm
C68, C78: 10nf; C_Disc_D7.5mm_W2.5mm_P5.00mm
C77: 8-70pf; c_trimmer-10
D8: 1N914; D_DO-35_SOD27_P7.62mm_Horizontal
J5: DISK ROM ENABLE; PinHeader_1x02_P2.54mm_Vertical
J6: Floppy Interface; IDC-Header_2x17_P2.54mm_Vertical
R9: 10K; R_Axial_DIN0207_L6.3mm_D2.5mm_P7.62mm_Horizontal
R10, R44, R49, R50: 1K; R_Axial_DIN0207_L6.3mm_D2.5mm_P7.62mm_Horizontal
R45, R46, R47, R48: 150; R_Axial_DIN0207_L6.3mm_D2.5mm_P7.62mm_Horizontal
RV1: 10K-Read; Potentiometer_Vishay_T73YP_Vertical
RV2: 10K-Write; Potentiometer_Vishay_T73YP_Vertical
U3: 74LS00; DIP-14_W7.62mm_Socket_LongPads
U4: 74LS07; DIP-14_W7.62mm_Socket_LongPads
U5: 27C64; DIP-28_W15.24mm_Socket_LongPads
U6: 74LS04; DIP-14_W7.62mm_Socket_LongPads
U7: 74LS139; DIP-16_W7.62mm_Socket_LongPads
U8: 74LS06N; DIP-14_W7.62mm_Socket_LongPads
U9: 74LS174; DIP-16_W7.62mm_Socket_LongPads
U10: WD2797; DIP-40_W15.24mm
U11: 74LS74; DIP-14_W7.62mm_Socket_LongPads
Y1: 4mhz; Crystal_HC49-U_Vertical

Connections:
+5V: C78.2, R9.1, R10.2, R45.1, R46.1, R47.2, R48.1, RV1.1, RV2.1, U3.14 (VCC), U4.14 (VCC), U5.1 (VPP), U5.27 (~PGM), U5.28 (VCC), U6.14 (VCC), U7.16 (VCC), U8.14 (VCC), U9.16 (VCC), U10.21 (VCC), U10.32 (READY), U11.1 (~R), U11.4 (~S), U11.10 (~S), U11.13 (~R), U11.14 (VCC); also elsewhere on the board
A0: U5.10 (A0), U10.5 (A0); also elsewhere on the board
A1: U5.9 (A1), U10.6 (A1); also elsewhere on the board
A2: U5.8 (A2), U10.3 (~CS); also elsewhere on the board
A3: U5.7 (A3), U7.3 (B); also elsewhere on the board
A4: U5.6 (A4); also elsewhere on the board
A5: U5.5 (A5); also elsewhere on the board
A6: U5.4 (A6); also elsewhere on the board
A7: U5.3 (A7); also elsewhere on the board
A8: U5.25 (A8); also elsewhere on the board
A9: U5.24 (A9); also elsewhere on the board
A10: U5.21 (A10); also elsewhere on the board
A11: U5.23 (A11); also elsewhere on the board
A12: U5.2 (A12); also elsewhere on the board
CART: U10.38 (DRQ); also elsewhere on the board
D0: U5.11 (D0), U9.3 (D0), U10.7 (DAL0); also elsewhere on the board
D1: U5.12 (D1), U9.4 (D1), U10.8 (DAL1); also elsewhere on the board
D2: U5.13 (D2), U9.6 (D2), U10.9 (DAL2); also elsewhere on the board
D3: U5.15 (D3), U9.11 (D3), U10.10 (DAL3); also elsewhere on the board
D4: U5.16 (D4), U9.13 (D4), U10.11 (DAL4); also elsewhere on the board
D5: U5.17 (D5), U9.14 (D5), U10.12 (DAL5); also elsewhere on the board
D6: U5.18 (D6), U10.13 (DAL6); also elsewhere on the board
D7: U5.19 (D7), U10.14 (DAL7); also elsewhere on the board
DDEN: U9.10 (Q3), U10.37 (~DDEN)
DINT1: U3.12, U9.15 (Q5)
DINT2: U3.13, U10.39 (INTRQ)
DIRC: J6.18, U8.4
DISKIP: J6.8, R47.1, U10.35 (~IP)
DISKMOTOR: J6.16, U7.15 (~EN), U8.12
DISKRAWRD: J6.30, R48.2, U10.27 (~RAW_READ)
DISKWPRT: J6.28, R46.2, U10.36 (~WPRT)
DS0: J6.10, U4.2
DS1: J6.12, U4.4
DS2: J6.14, U4.6
DS3: J6.6, U4.8
DSKCLK: U10.24 (CLK), U11.2 (D), U11.6 (~Q)
E: U3.1, U3.10; also elsewhere on the board
ENP: U9.12 (Q4), U10.1 (ENP)
GND: C5.1, C77.2, C78.1, D8.2 (A), J6.1, J6.3, J6.5, J6.7, J6.9, J6.11, J6.13, J6.15, J6.17, J6.19, J6.21, J6.23, J6.25, J6.27, J6.29, J6.31, J6.33, R44.1, RV1.3, RV2.3, U3.7 (GND), U4.7 (GND), U5.14 (GND), U5.22 (~OE), U6.7 (GND), U7.8 (GND), U8.7 (GND), U9.8 (GND), U10.17 (~5~/8), U10.20 (VSS), U11.7 (GND); also elsewhere on the board
unnamed: C2.1, D8.1 (K), R44.2
unnamed: C2.2, U10.23 (PUMP)
unnamed: C5.2, R49.2, U6.9, Y1.1
unnamed: C68.1, R50.2, U6.11
unnamed: C68.2, R49.1, U6.8
unnamed: C77.1, U10.26 (VCO)
unnamed: J5.1, R9.2, U5.20 (~CE)
unnamed: R10.1, U10.22 (~TEST)
unnamed: R50.1, U6.10, U11.11 (C), Y1.2
unnamed: RV1.2, U10.18 (RPW)
unnamed: RV2.2, U10.33 (WPW)
unnamed: U3.2, U6.6
unnamed: U3.3, U9.9 (Cp)
unnamed: U3.5, U6.2
unnamed: U3.9, U6.4
unnamed: U3.11, U4.11
unnamed: U4.1, U7.12 (~Q0)
unnamed: U4.3, U7.11 (~Q1)
unnamed: U4.5, U7.10 (~Q2)
unnamed: U4.9, U7.9 (~Q3)
unnamed: U6.1, U7.4 (~Q0)
unnamed: U6.3, U7.5 (~Q1)
unnamed: U6.5, U7.6 (~Q2)
unnamed: U7.13 (B), U9.5 (Q1)
unnamed: U7.14 (A), U9.2 (Q0)
unnamed: U8.13, U9.7 (Q2)
unnamed: U3.6, U10.2 (~WE)
unnamed: U3.8, U10.4 (~RE)
unnamed: U8.1, U10.15 (STEP)
unnamed: U8.3, U10.16 (DIRC)
unnamed: U8.11, U10.25 (SSO)
unnamed: U8.9, U10.30 (WG)
unnamed: U8.5, U10.31 (WD)
unnamed: U11.3 (C), U11.8 (~Q), U11.12 (D)
P2: U7.1 (~EN); also elsewhere on the board
Q: U3.4; also elsewhere on the board
ROM2: J5.2; also elsewhere on the board
R~W~: U7.2 (A); also elsewhere on the board
SSO: J6.32, U8.10
STEP: J6.20, U8.2
TR00: J6.26, R45.2, U10.34 (~TR00)
WD: J6.22, U8.6
WG: J6.24, U8.8
~NMI: U4.10; also elsewhere on the board
~RESET: U9.1 (~Mr), U10.19 (~MR); also elsewhere on the board

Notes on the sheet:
DISK CONTROLLER IS OPTIONAL IF NOT NEEDED, DO NOT POPULATE THIS SHEET

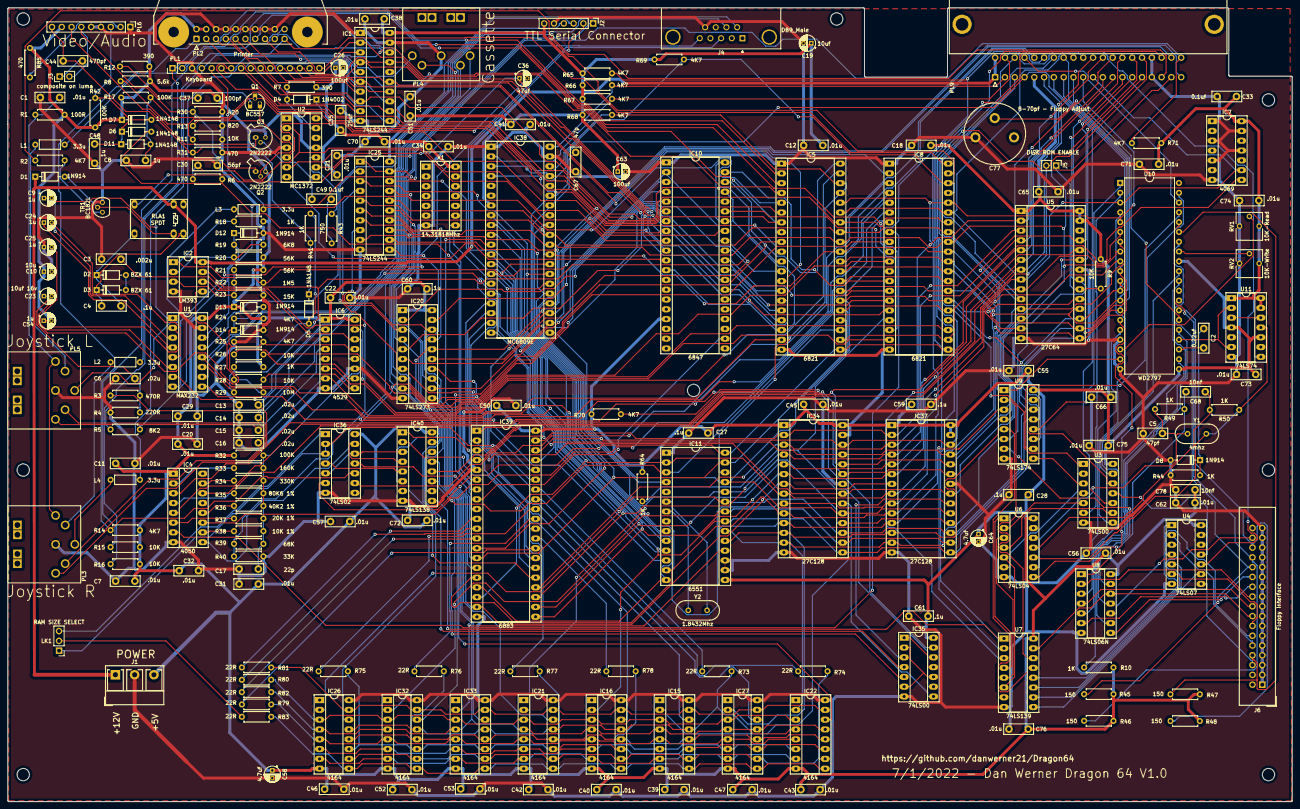
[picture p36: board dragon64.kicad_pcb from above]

Board: 2 copper layers, 333.2 x 205.9 mm, 232 parts (1 on the bottom side), 266 nets.

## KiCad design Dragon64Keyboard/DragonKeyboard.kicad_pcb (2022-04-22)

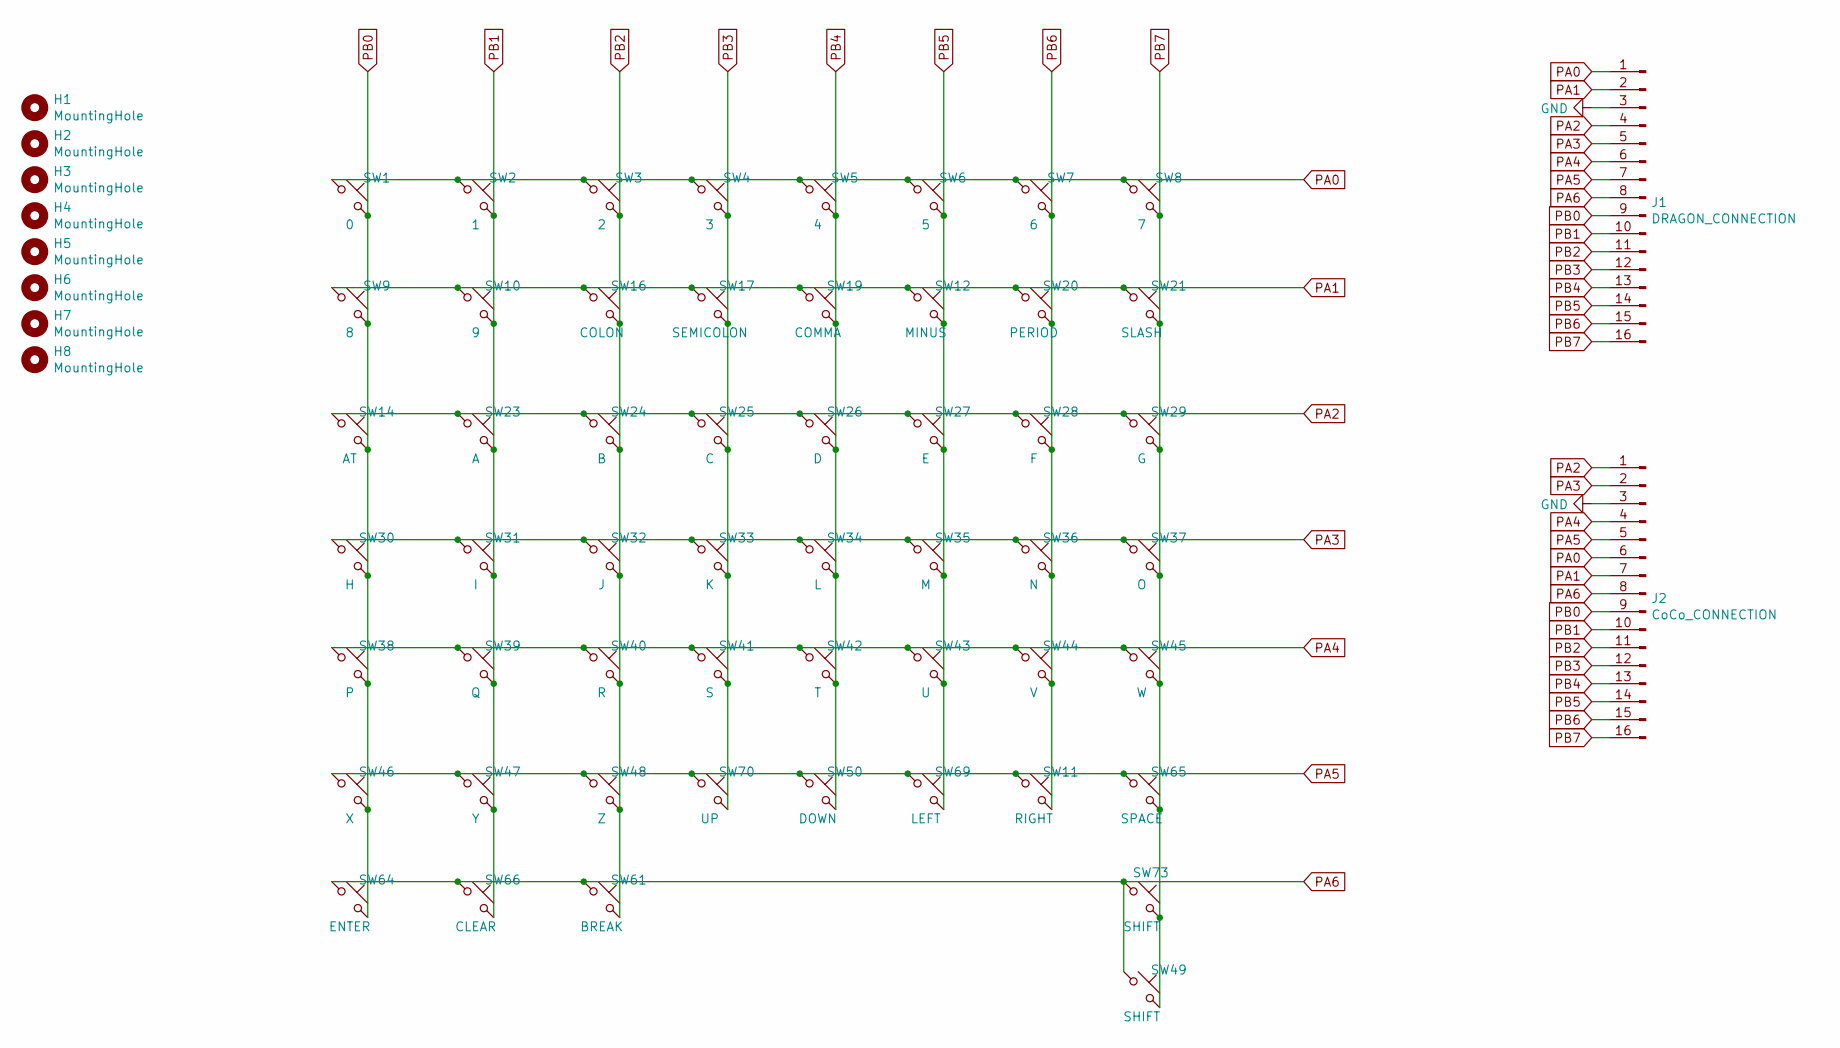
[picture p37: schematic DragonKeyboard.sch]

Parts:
H1, H2, H3, H4, H5, H6, H7, H8: MountingHole; MountingHole_3.2mm_M3_Pad
J1: DRAGON_CONNECTION; PinHeader_1x16_P2.54mm_Vertical
J2: CoCo_CONNECTION; PinHeader_1x16_P2.54mm_Vertical
SW1: 0; CHERRY_PCB_100H
SW2: 1; CHERRY_PCB_100H
SW3: 2; CHERRY_PCB_100H
SW4: 3; CHERRY_PCB_100H
SW5: 4; CHERRY_PCB_100H
SW6: 5; CHERRY_PCB_100H
SW7: 6; CHERRY_PCB_100H
SW8: 7; CHERRY_PCB_100H
SW9: 8; CHERRY_PCB_100H
SW10: 9; CHERRY_PCB_100H
SW11: RIGHT; CHERRY_PCB_100H
SW12: MINUS; CHERRY_PCB_100H
SW14: AT; CHERRY_PCB_100H
SW16: COLON; CHERRY_PCB_100H
SW17: SEMICOLON; CHERRY_PCB_100H
SW19: COMMA; CHERRY_PCB_100H
SW20: PERIOD; CHERRY_PCB_100H
SW21: SLASH; CHERRY_PCB_100H
SW23: A; CHERRY_PCB_100H
SW24: B; CHERRY_PCB_100H
SW25: C; CHERRY_PCB_100H
SW26: D; CHERRY_PCB_100H
SW27: E; CHERRY_PCB_100H
SW28: F; CHERRY_PCB_100H
SW29: G; CHERRY_PCB_100H
SW30: H; CHERRY_PCB_100H
SW31: I; CHERRY_PCB_100H
SW32: J; CHERRY_PCB_100H
SW33: K; CHERRY_PCB_100H
SW34: L; CHERRY_PCB_100H
SW35: M; CHERRY_PCB_100H
SW36: N; CHERRY_PCB_100H
SW37: O; CHERRY_PCB_100H
SW38: P; CHERRY_PCB_100H
SW39: Q; CHERRY_PCB_100H
SW40: R; CHERRY_PCB_100H
SW41: S; CHERRY_PCB_100H
SW42: T; CHERRY_PCB_100H
SW43: U; CHERRY_PCB_100H
SW44: V; CHERRY_PCB_100H
SW45: W; CHERRY_PCB_100H
SW46: X; CHERRY_PCB_100H
SW47: Y; CHERRY_PCB_100H
SW48: Z; CHERRY_PCB_100H
SW49: SHIFT; CHERRY_PCB_225H
SW50: DOWN; SW_Cherry_MX_1.00u_PCB
SW61: BREAK; SW_Cherry_MX_1.75u_PCB
SW64: ENTER; CHERRY_PCB_225H
SW65: SPACE; CHERRY_PCB_625H
SW66: CLEAR; CHERRY_PCB_100H
SW69: LEFT; CHERRY_PCB_100H
SW70: UP; CHERRY_PCB_100H
SW73: SHIFT; CHERRY_PCB_275H

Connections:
GND: J1.3, J2.3
PA0: J1.1, J2.6, SW1.1, SW2.1, SW3.1, SW4.1, SW5.1, SW6.1, SW7.1, SW8.1
PA1: J1.2, J2.7, SW9.1, SW10.1, SW12.1, SW16.1, SW17.1, SW19.1, SW20.1, SW21.1
PA2: J1.4, J2.1, SW14.1, SW23.1, SW24.1, SW25.1, SW26.1, SW27.1, SW28.1, SW29.1
PA3: J1.5, J2.2, SW30.1, SW31.1, SW32.1, SW33.1, SW34.1, SW35.1, SW36.1, SW37.1
PA4: J1.6, J2.4, SW38.1, SW39.1, SW40.1, SW41.1, SW42.1, SW43.1, SW44.1, SW45.1
PA5: J1.7, J2.5, SW11.1, SW46.1, SW47.1, SW48.1, SW50.1, SW65.1, SW69.1, SW70.1
PA6: J1.8, J2.8, SW49.1, SW61.1, SW64.1, SW66.1, SW73.1
PB0: J1.9, J2.9, SW1.2, SW9.2, SW14.2, SW30.2, SW38.2, SW46.2, SW64.2
PB1: J1.10, J2.10, SW2.2, SW10.2, SW23.2, SW31.2, SW39.2, SW47.2, SW66.2
PB2: J1.11, J2.11, SW3.2, SW16.2, SW24.2, SW32.2, SW40.2, SW48.2, SW61.2
PB3: J1.12, J2.12, SW4.2, SW17.2, SW25.2, SW33.2, SW41.2, SW70.2
PB4: J1.13, J2.13, SW5.2, SW19.2, SW26.2, SW34.2, SW42.2, SW50.2
PB5: J1.14, J2.14, SW6.2, SW12.2, SW27.2, SW35.2, SW43.2, SW69.2
PB6: J1.15, J2.15, SW7.2, SW11.2, SW20.2, SW28.2, SW36.2, SW44.2
PB7: J1.16, J2.16, SW8.2, SW21.2, SW29.2, SW37.2, SW45.2, SW49.2, SW65.2, SW73.2

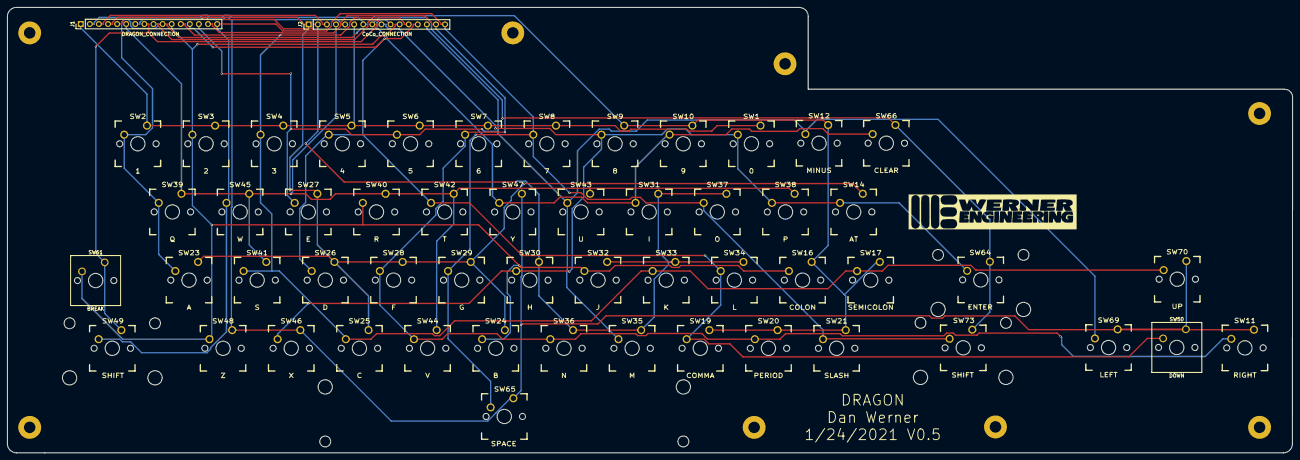
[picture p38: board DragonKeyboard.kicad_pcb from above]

Board: 2 copper layers, 359.1 x 124.5 mm, 63 parts (0 on the bottom side), 16 nets.

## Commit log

2022-03-11 PAL to NTSC
    [dragon64-B_Cu.gbr, dragon64-B_Mask.gbr, dragon64-B_Paste.gbr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]
2022-04-10 Bug fixes and add Floppy Controller
    [disk.sch, dragon64.dsn, dragon64.kicad_pcb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]
2022-04-11 add case
    [DragonCase.scad, disk.sch, dragon64.dsn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]
2022-04-11 enclosure design work
    [DragonCase.scad, keyboard.stl]
2022-04-13 PCB layout work
    [dragon64.dsn, dragon64.kicad_pcb]
2022-04-22 pcb cleanup and readme
    [BOM.csv, BOM.xlsx, DragonCase.scad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]
2022-04-27 pcb routing
    [dragon64.dsn, dragon64.kicad_pcb]
2022-04-29 enclosure changes
    [DragonCase.scad, DragonCase_top.stl, dragon64.dsn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]
2022-05-30 add rom images
    [dragon64.kicad_pcb, dragon64.sch, pia.sch]
2022-05-30 update schematic and enclosure
    [DragonCase.scad, DragonCase_top.stl, dragon64.kicad_pcb]
2022-06-09 documentation update
    [disk.sch]
2022-06-23 PCB updates
    [disk.sch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]
2022-07-02 version 1.0 cleanup
    [dragon64-B_Cu.gbr, dragon64-B_Mask.gbr, dragon64-B_Paste.gbr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]
2023-10-14 update BOM
